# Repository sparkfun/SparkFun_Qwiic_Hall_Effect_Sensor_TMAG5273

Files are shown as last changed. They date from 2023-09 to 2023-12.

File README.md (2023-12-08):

SparkFun Hall-Effect Sensor - TMAG5273
========================================

| [	SparkFun Linear 3D Hall-Effect Sensor - TMAG5273 (Qwiic)  *(SEN-23880)*](https://www.sparkfun.com/products/23880) | [SparkFun Mini Linear 3D Hall-Effect Sensor - TMAG5273 (Qwiic) *(SEN-23881)*](https://www.sparkfun.com/products/23881) |
| --- | --- |
| product in standard 1x1 form factor (https://www.sparkfun.com/products/23880) | product in mini form factor (https://www.sparkfun.com/products/23881) |

Do you have a project that could use an inconspicuous [HID](https://en.wikipedia.org/wiki/Human_interface_device) (human interface device)? Ever wanted to tamper-proof your window alarm (i.e. contact sensors) from teenagers sneaking out or home intruders? Do you have a mechanical switch that keeps failing?

If you answered yes to any of those questions, the TMAG5273 from [Texas Instruments](https://www.ti.com) could be the solution to your problems. The TMAG5273 is low-power 3D [hall-effect sensor](https://en.wikipedia.org/wiki/Hall_effect_sensor) that is perfect for detecting and measuring changes in a nearby magnetic field. With a linear, magnetic range configurable to either ±40 mT or ±80 mT and TI's integrated angle calculation engine (CORDIC), the TMAG5273 can be used in various applications:

* Detecting motor movement
* Creating a [HID](https://en.wikipedia.org/wiki/Human_interface_device) (human interface device) *(i.e. joysticks, knobs, scroll wheels, etc.)*
* Replacing various mechanical switches (i.e. rotary encoders, contact switches, reed switches, etc.)*

In addition, the included magnetic tamper detection and wake-up/threshold settings can be configured to trigger interrupts through the I<sup>2</sup>C interface or only with the dedicated interrupt pin.

*These products are available in both the standard 1"x1" and mini Qwiic breakout boards. The mini is panel mount compatible for use in enclosures.*

Repository Contents
-------------------

* **[/docs](/docs/)** - Online documentation files
    * [assets](/docs/assets/) - Assets files
        * [board_files](/docs/assets/board_files/) - Files for the product design
            * [Eagle design files](/docs/assets/board_files/eagle_files.zip) (.zip)
            * [Schematic](/docs/assets/board_files/schematic.pdf) (.pdf)
            * [Dimensions](/docs/assets/board_files/dimensions.pdf) (.pdf)
        * [component_documentation](/docs/assets/component_documentation/) - Datasheets for hardware components
        * [img/hookup_guide/](/docs/assets/img/hookup_guide/) - Images for hookup guide documentation
* **[/Hardware](/Hardware/)** - Eagle design files (.brd, .sch)
  * **[/1U](/Hardware/1U/)** - 1"x1" Form Factor
    * **[/Production](/Hardware/1U/Production/)** - Production files
  * **[/Mini](/Hardware/Mini/)** - Mini Form Factor
    * **[/Production](/Hardware/Mini/Production/)** - Production files

Documentation
--------------

* **[Hookup Guide (mkdocs)](http://docs.sparkfun.com/SparkFun_Qwiic_Hall_Effect_Sensor_TMAG5273/)** - Hookup guide for the Qwiic hall-effect sensor hosted by GitHub pages.
  * [Arduino Library](https://github.com/sparkfun/SparkFun_TMAG5273_Arduino_Library/tree/main)

*Need to download or print our hookup guide?*

* [Print *(Print to PDF)* from Single-Page View](http://docs.sparkfun.com/SparkFun_Qwiic_Hall_Effect_Sensor_TMAG5273/print_view)

Product Variants
----------------

* [SEN-23880](https://www.sparkfun.com/products/23880)- v1.0, Initial Release *(1"x1" Form Factor)*
* [SEN-23881](https://www.sparkfun.com/products/23881)- v1.0, Initial Release *(Mini Form Factor)*

Version History
---------------

* [v10](https://github.com/sparkfun/SparkFun_Qwiic_Hall_Effect_Sensor_TMAG5273/releases/tag/v10) - Initial Release

License Information
-------------------

This product is ***open source***!

Please review the [`LICENSE.md`](./LICENSE.md) file for license information.

If you have any questions or concerns about licensing, please contact technical support on our [SparkFun forums](https://forum.sparkfun.com/viewforum.php?f=152).

Distributed as-is; no warranty is given.

- Your friends at SparkFun.

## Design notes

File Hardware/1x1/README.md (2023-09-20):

SparkFun <PRODUCT NAME> Design Files
=====================================

The .sch and .brd files hare are Eagle CAD schematic and PCB design files from SparkFun Electronics.
A freeware version of Autodesk Eagle can be found [here](https://www.autodesk.com/products/eagle/free-download).

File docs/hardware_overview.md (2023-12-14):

---
icon: material/cog
---

## Board Dimensions
The Qwiic Hall-Effect Sensors are laid out in the standardized 0.5"x 1" (1.77 x 2.54 cm) *mini* form-factor and the regular, 1" x 1" (2.54 x 2.54 cm) Qwiic breakout board. These boards also include standard 0.13" mounting holes, which are compatible with 4-40 screws. The dimensions of these boards are illustrated in the drawings below, where the listed measurements are in inches.

<div class="grid" markdown>

<div markdown>
<figure markdown>
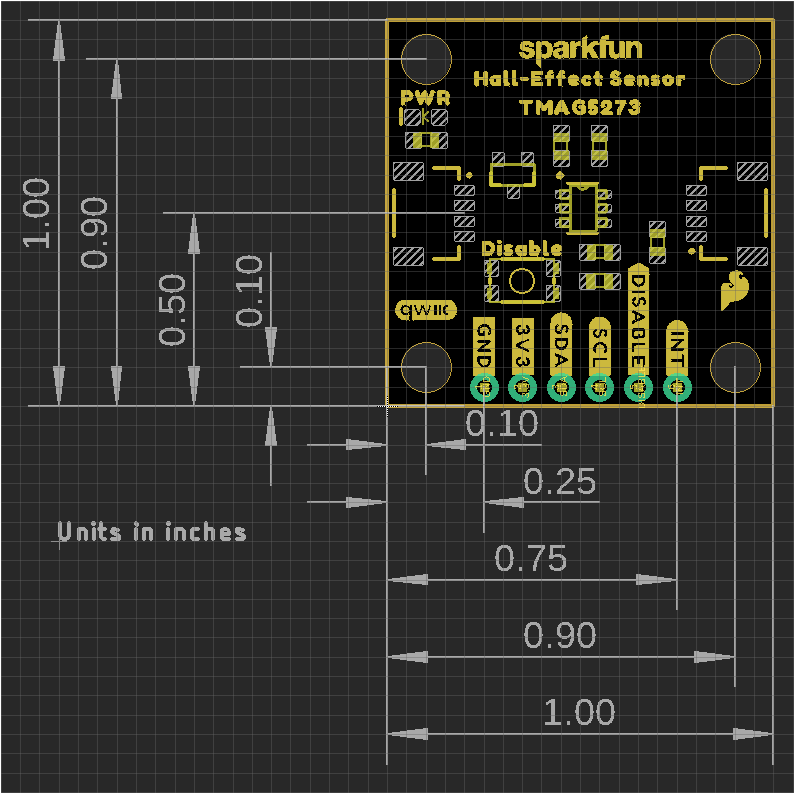
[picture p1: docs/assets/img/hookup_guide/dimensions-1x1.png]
Board Dimensions of the standard board

</figure>
</div>

<div markdown>
<figure markdown>
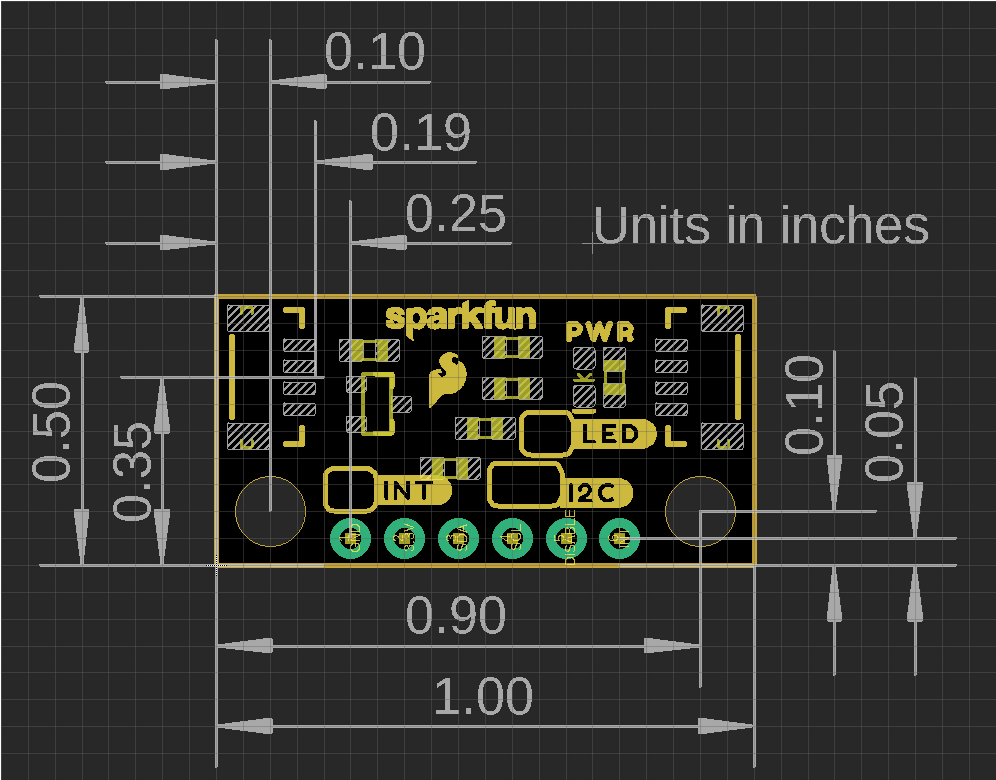
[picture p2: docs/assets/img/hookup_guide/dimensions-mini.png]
Board Dimensions of the mini board

</figure>
</div>

</div>

<center>
*[Dimensions (PDF)](./assets/board_files/dimensions.pdf) for the Qwiic Hall-Effect Sensor boards, in inches.*
</center>

??? tip "Need more measurements?"
	For more information about the board's dimensions, users can download the [eagle files](./assets/board_files/eagle_files.zip) for the boards. These files can be opened in Eagle and additional measurements can be made with the dimensions tool.

	??? info ":octicons-download-16:{ .heart } Eagle - Free Download!"
		Eagle is a [CAD]("computer-aided design") program for electronics that is free to use for hobbyists and students. However, it does require an account registration to utilize the software.

		<center>
		[Download from<br>:autodesk-primary:{ .autodesk }](https://www.autodesk.com/products/eagle/free-download "Go to downloads page"){ .md-button .md-button--primary width="250px" }
		</center>

	??? info ":straight_ruler: Dimensions Tool"
		This video from Autodesk demonstrates how to utilize the dimensions tool in Eagle, to include additional measurements:

		<center>
		<div class="video">
		<iframe src="https://www.youtube.com/embed/dZLNd1FtNB8" title="EAGLE Dimension Tool" frameborder="0" allow="accelerometer; autoplay; clipboard-write; encrypted-media; gyroscope; picture-in-picture" allowfullscreen></iframe>
		</div>
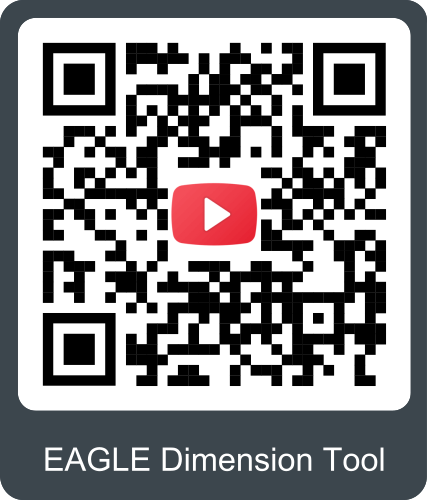
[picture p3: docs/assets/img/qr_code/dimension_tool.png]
QR code to play video
		
		</center>

## Power
The TMAG5273 requires a supply voltage between **2.3 to 3.6V** (1). This power can be provided to the board, either, through one of the *polarized* Qwiic connectors or the dedicated 3.3V (`3V3`) and ground (`GND`) [PTH](https://en.wikipedia.org/wiki/Through-hole_technology "Plated Through Holes") pins broken out on the board.
{ .annotate }

1. While the sensor's listed voltage range is 1.7 to 3.6V, its under-voltage range is 1.9 to 2.2V. Users may find that their sensor is unresponsive below 2.3V.

<div class="grid" markdown>

<div markdown>
<figure markdown>
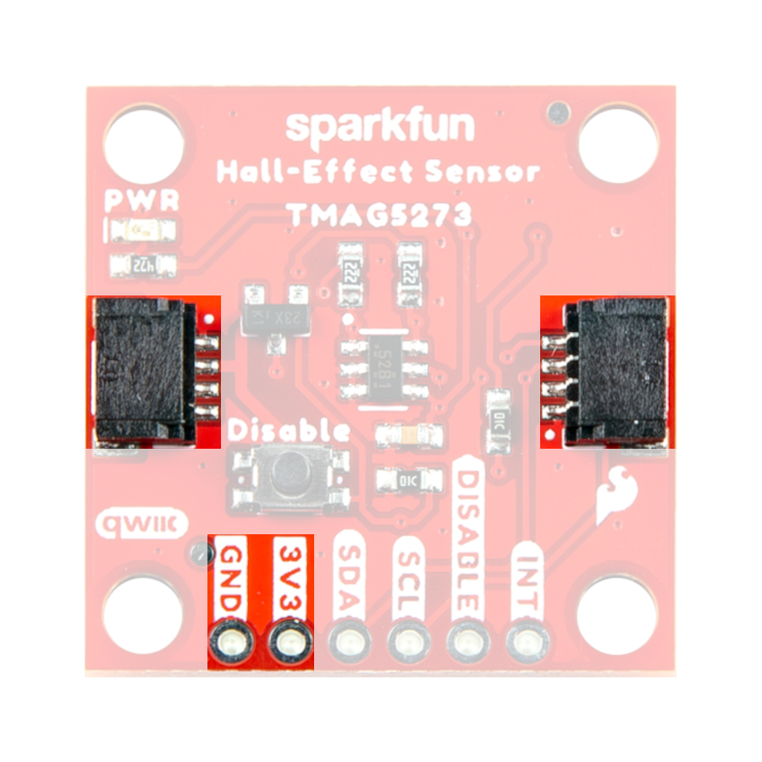
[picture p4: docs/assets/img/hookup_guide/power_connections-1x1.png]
Power connections on the standard board

</figure>
</div>

<div markdown>
<figure markdown>
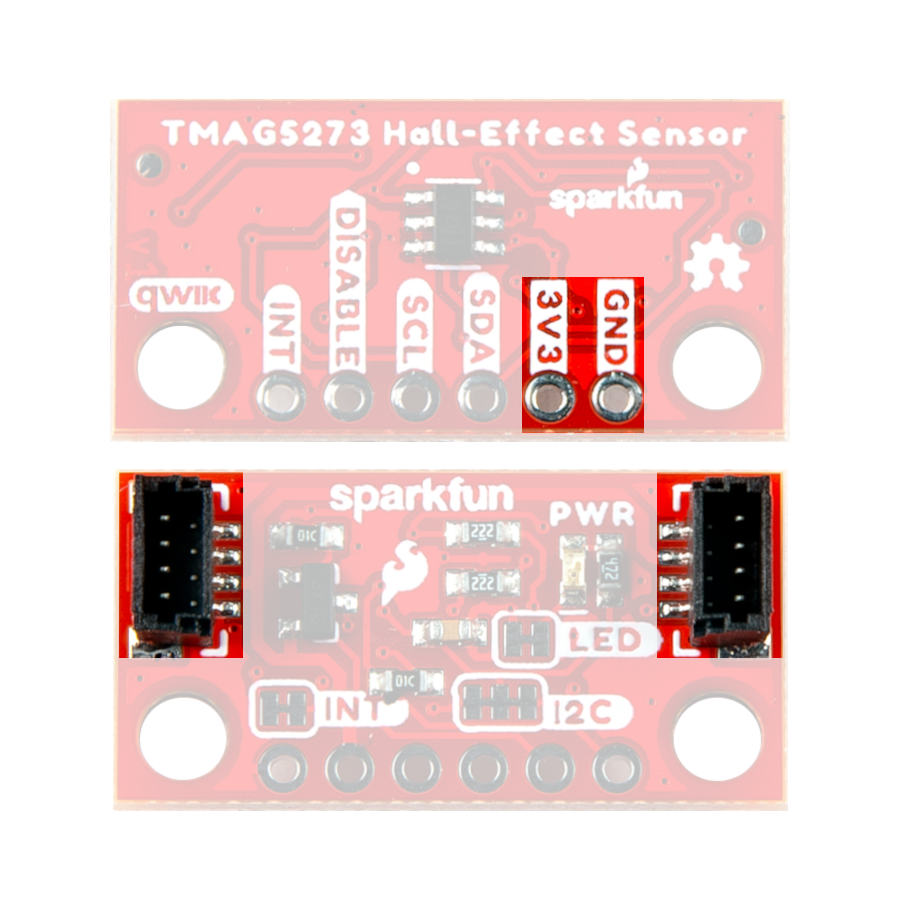
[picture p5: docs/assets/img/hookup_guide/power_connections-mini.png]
Power connections on the mini board

</figure>
</div>

</div>

<center>
*Qwiic Hall-Effect Sensor boards' power connections.*
</center>

!!! warning
	The Qwiic connect system is meant to run on **3.3V**. Ensure that another voltage is not being supplied through the PTH pins when utilized in conjunction with this system.

	??? tip "Under-Voltage Threshold"
		The under-voltage threshold of the TMAG5273 is **1.9 to 2.2V**. It is recommended that users provide an input voltage between **2.3 to 3.6V**.

!!! info
	For more details, users can reference the [schematic](./assets/board_files/schematic.pdf) and the [TMAG5273 datasheet](./assets/component_documentation/tmag5273.pdf).

### Power Status LED
The red, `PWR` LED will begin to light up once **~1.4V** is supplied to the board; however, for most users, it will light up when **3.3V** is supplied through the Qwiic connector. A jumper is available to disconnect the power from the LED, for low-power applications (see Jumpers section below).

<div class="grid" markdown>

<div markdown>
<figure markdown>
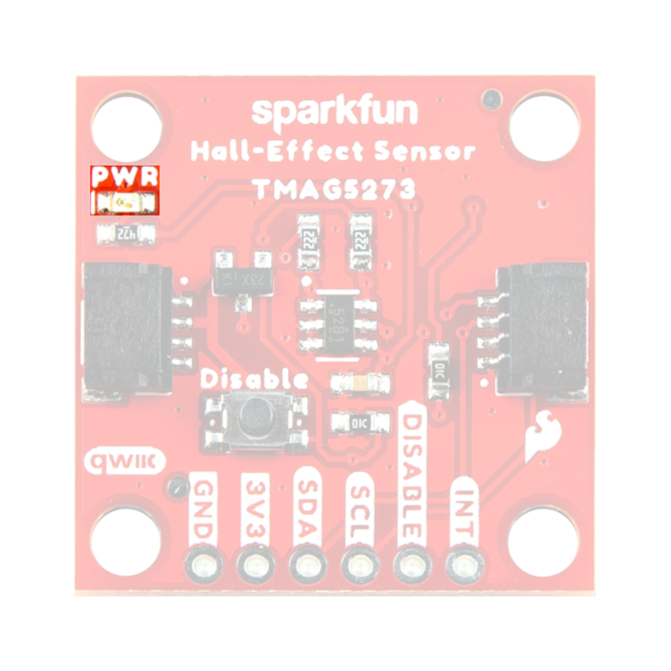
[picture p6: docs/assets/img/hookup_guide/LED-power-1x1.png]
Power LED on the standard board

</figure>
</div>

<div markdown>
<figure markdown>
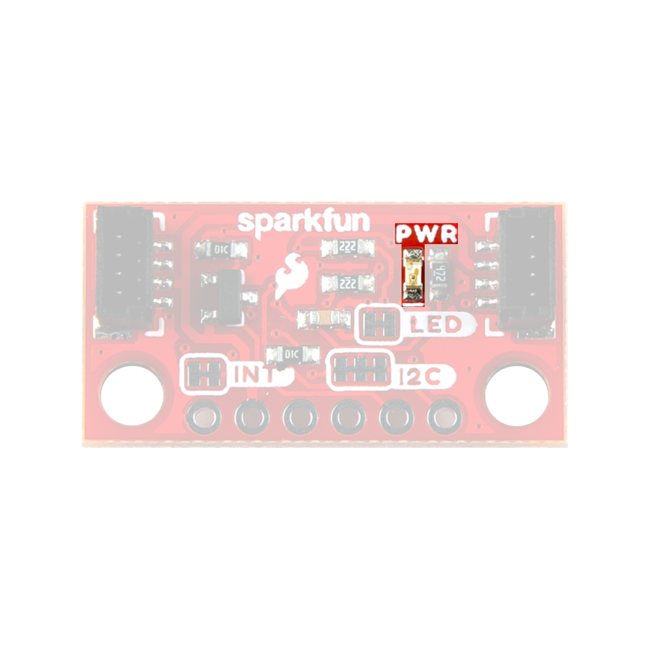
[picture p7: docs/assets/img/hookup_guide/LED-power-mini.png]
Power LED on the mini board

</figure>
</div>

</div>

<center>
*The `PWR` status LED on the Qwiic Hall-Effect Sensor boards.*
</center>

!!! tip "Minimum Voltage"
	Users should keep in mind that the forward voltage of the red LED is lower than the minimum voltage required to power the TMAG5273 sensor. Therefore, the LED could potentially be *(dimly)* lit, when there isn't enough voltage to power the sensor.

## :fontawesome-solid-microchip:&nbsp; TMAG5273
The Qwiic Hall-Effect Sensor board features the [TMAG5273 sensor](./assets/component_documentation/tmag5273.pdf) from [Texas Instruments](https://www.ti.com). The TMAG5273 is low-power 3D [hall-effect sensor](https://en.wikipedia.org/wiki/Hall_effect_sensor) that is perfect for detecting and measuring changes in a nearby magnetic field. The magnetic range of the sensor is configurable to either ±40 mT or ±80 mT. In addition, the TMAG5273 features TI's integrated angle calculation engine (CORDIC) with gain adjustment, tamper detection, and temperature compensation (for NdBFe and ceramic magnet types). The operation sensor's interrupt can be configured to trigger through the I<sup>2</sup>C interface or an interrupt pin, based upon a wake-up/threshold setting or the conversion of a new measurement.

<div class="grid" markdown>

<div markdown>

**Features:**

<div class="annotate" markdown>

* Configurable I<sup>2</sup>C Address:
    * Default (7-bit): **0x35** *(hex)* or **`0110101`** *(bin)*
* Operating Voltage: **1.7 to 3.6V** (1)
* Current Draw:
	* Active: 2.3mA
	* Sleep Mode: 5nA
	* Wake-Up/Sleep (@ 1Hz): 1&micro;A
* Full-Scale Range: &plusmn;40mT or &plusmn;80mT (2)
* Accuracy: &plusmn;5% (3)
	* Temperature Compensation (4)
* CORDIC Engine (5)
* Output Data Rate (Hz): (6)
	* 0.05, 0.2, 0.5, 1, 2, 10, 20, 33, 50, 66, 100, 200, or 1000
* Operating Temperature: -40 to 125&deg;C
* Interrupt Triggers:
	* Threshold
	* Conversion

</div>

1. The sensor may be unresponsive below 2.3V; its under-voltage range is 1.9 to 2.2V
2. The range on each axis
3. The typical sensitivity at room temperature
4. Adjusts for magnet type *(NdBFe or ceramic)*
5. Integrated angle calculation *(along a single axis)*
6. [CRC](https://en.wikipedia.org/wiki/Cyclic_redundancy_check "Cyclic Redundancy Check") can be enabled

</div>

<div markdown>

<figure markdown>
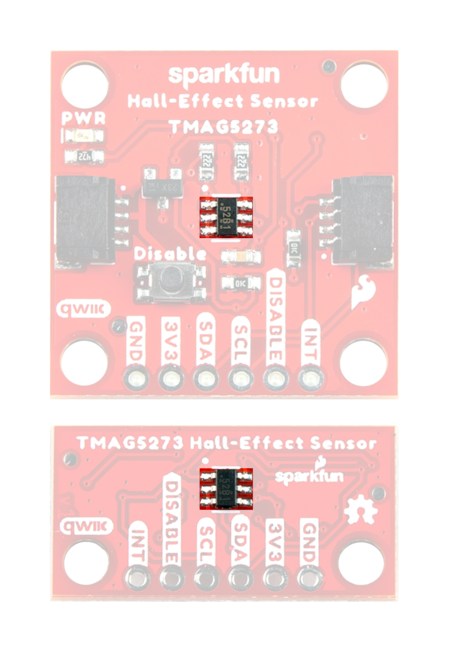
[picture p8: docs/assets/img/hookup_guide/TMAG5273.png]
TMAG5273 sensor on the boards

<figcaption markdown>The TMAG5273 sensor on the Qwiic Hall-Effect Sensor boards.</figcaption>
</figure>

</div>

</div>

??? tip "Sensor Alignment"
	=== "Position"
		We have positioned the TMAG5273 chip, based on the offset of the internal hall elements in the sensor.

		<figure markdown>
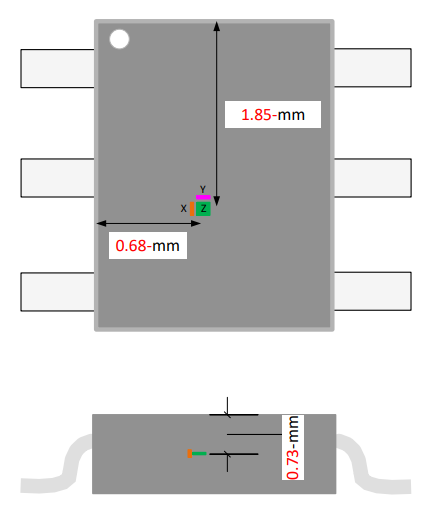
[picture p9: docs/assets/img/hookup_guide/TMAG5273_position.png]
TMAG5273 hall-effect elements position
		
		<figcaption markdown>Position of the hall elements in the TMAG5273. Source: [TMAG5273 Datasheet](./assets/component_documentation/tmag5273.pdf)</figcaption>
		</figure>

		!!! info
			For exact measurements, users can download and reference the [eagle files](./assets/board_files/eagle_files.zip) of the boards. We recommend referencing the sensor's position based on the board's CNC milled, mounting holes.
			
			!!! note
				In manufacturing, we panelize our boards on a single [PCB](https://en.wikipedia.org/wiki/Printed_circuit_board "Printed Circuit Board") with a v-score separation. This is an efficient method to assemble multiple boards at once. After the panel is populated, cleaned, and inspected, the individual boards are separated by slicing the v-scores.

				While efficient, this process means that measurements referencing the edges of the PCB won't be as accurate when compared to the included mounting holes.

	=== "Orientation"
		The orientation of the sensor's axes is illustrated in the figure below.

		<figure markdown>
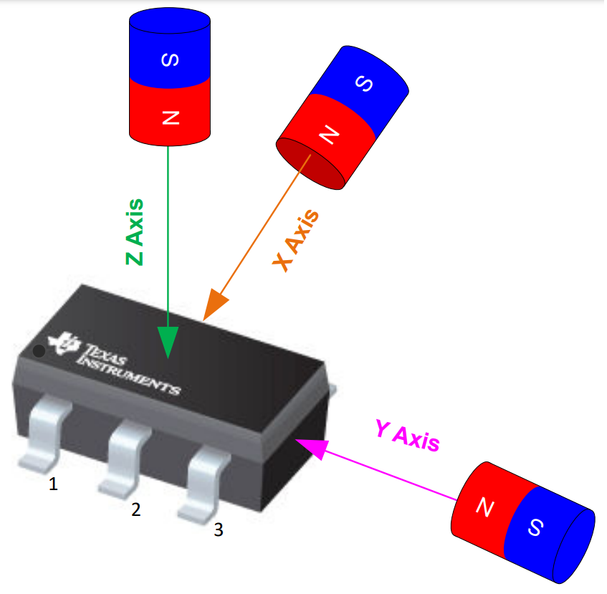
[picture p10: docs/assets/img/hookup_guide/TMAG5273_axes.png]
TMAG5273 sensor's field orientations
		
		<figcaption markdown>The magnetic field orientation of the TMAG5273 hall-effect sensor. The TMAG5273's orientation is indicated by the black dot, just below the TI logo. Source: [TMAG5273 Datasheet](./assets/component_documentation/tmag5273.pdf)</figcaption>
		</figure>

		!!! info
			The orientation of the TMAG5273 sensor is indicated by the white silkscreen dot, next to the sensor, on the [PCB](https://en.wikipedia.org/wiki/Printed_circuit_board "Printed Circuit Board") of the Qwiic Hall-Effect Sensor boards. That dot correlates with the black dot just below the Texas Instruments logo in the figure above. 

??? note "Interrupt Operation"
	The interrupt function for the TMAG5273 can be set up to operate on either the `INT` or `SCL` pins. Users can also configure what triggers the interrupt, a threshold or data conversion. Control of the interrupt's operation is managed in the following registers:

	* `DEVICE_CONFIG_2`
	* `SENSOR_CONFIG_2`
	* `INT_CONFIG_1`

??? note "Magnetic Offset Correction"
	The TMAG5273 features an offset correction, on a pair of magnetic axes for situations where the sensor might be affected by a persistent magnetic field. The offsets are configured in the following registers:

	* `MAG_OFFSET_CONFIG_1`
	* `MAG_OFFSET_CONFIG_2`
	* `SENSOR_CONFIG_2`

	<figure markdown>
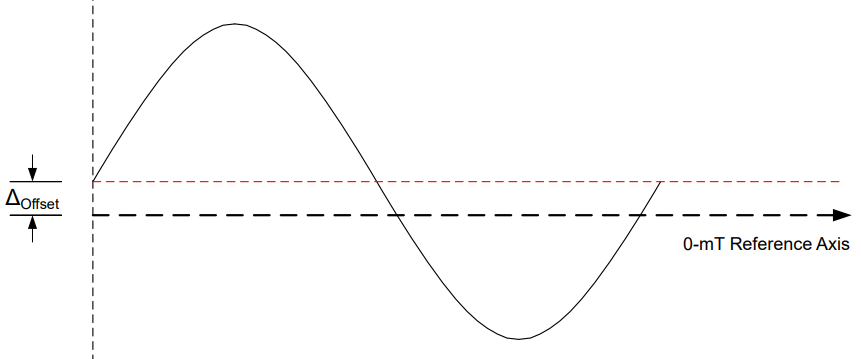
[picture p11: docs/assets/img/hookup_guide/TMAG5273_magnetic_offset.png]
example of a magnetic offset
	
	<figcaption markdown>The magnetic flux measurements of a sine curve with an offset above the reference axis. Source: [TMAG5273 Datasheet](./assets/component_documentation/tmag5273.pdf)</figcaption>
	</figure>

??? note "Gain Adjustment"
	The TMAG5273 features a gain adjustment, on a pair of magnetic axes for situations where a magnet's rotation axis is offset from the position of the sensor's hall elements. The gain adjustments are configured in the following registers:

	* `MAG_GAIN_CONFIG`
	* `SENSOR_CONFIG_2`

	<figure markdown>
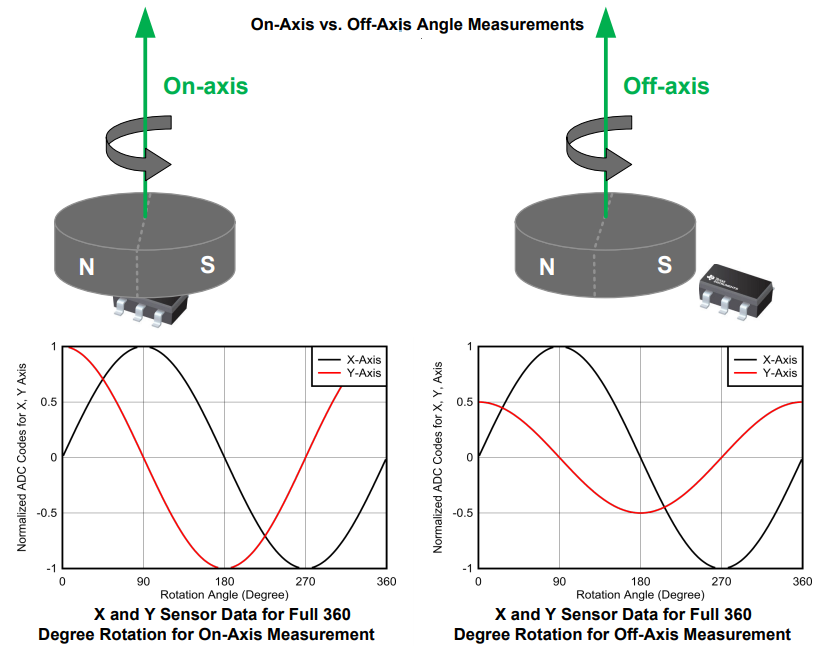
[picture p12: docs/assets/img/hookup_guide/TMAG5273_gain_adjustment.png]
example of a gain adjustment
	
	<figcaption markdown>The magnetic flux measurements of the TMAG5273 utilizing a magnet, with an on-axis and off-axis position. Source: [TMAG5273 Datasheet](./assets/component_documentation/tmag5273.pdf)</figcaption>
	</figure>

??? example "Tamper Detection"
	Magnetic tamper detection can be employed with the TMAG5273 by continuously monitoring for external magnetic fields. For more details, users can reference section **8.2.1** of the [TMAG5273 datasheet](./assets/component_documentation/tmag5273.pdf) and the [application note](./assets/component_documentation/sboa514a.pdf).

!!! info
	For more details, users can reference the [TMAG5273 datasheet](./assets/component_documentation/tmag5273.pdf).

## Breakout Pins
There are six [PTH](https://en.wikipedia.org/wiki/Through-hole_technology "Plated Through Holes") pins broken out on the Qwiic Hall-Effect Sensor boards. The pins are evenly spaced at 0.1" on the outer edge of the board; perfect for attaching [headers](https://www.sparkfun.com/categories/381). These pins provide access to the I<sup>2</sup>C interface and interrupt pin of the TMAG5273 sensor; and included is a `DISABLE` pin that controls the power to the sensor.

!!! note
	The I<sup>2</sup>C interface can also be accessed through the Qwiic connectors on the board.

### Disable Pin
Unfortunately, the TMAG5273 doesn't incorporate a software reset. The intended use of the TMAG5273 is to hard reset the sensor's power with a [GPIO](https://en.wikipedia.org/wiki/General-purpose_input/output "General Purpose I/O") pin. However, with the Qwiic connect system, users may not want to power cycle the other Qwiic devices on the system. Therefore, we have incorporated `DISABLE` pin whose circuitry allows users to reset the TMAG5273, without interrupting the power of the Qwiic connect system.

<div class="grid" markdown>

<div markdown>
<figure markdown>
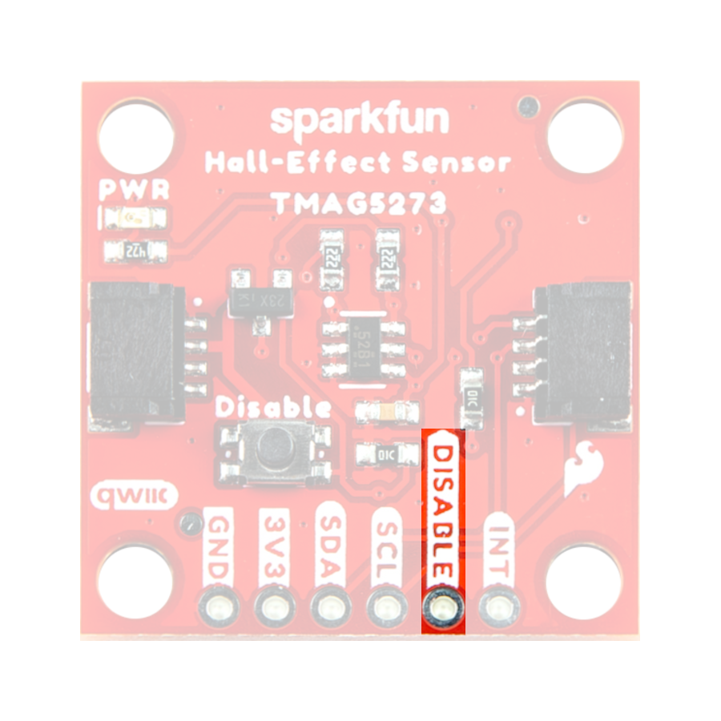
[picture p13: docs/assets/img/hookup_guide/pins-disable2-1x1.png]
Disable pin on the standard board

</figure>
</div>

<div markdown>
<figure markdown>
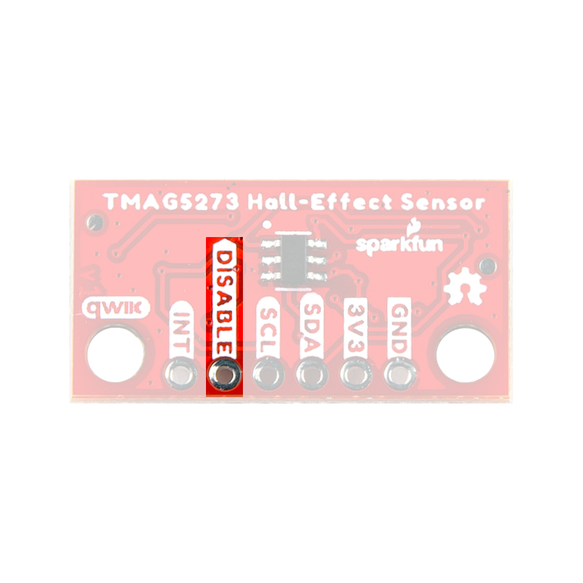
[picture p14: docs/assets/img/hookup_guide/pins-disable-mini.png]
Disable pin on the mini board

</figure>
</div>

</div>
<center>
*The `DISABLE` pin on the Qwiic Hall-Effect Sensor boards.*
</center>

!!! info
	For more details, users can reference the [schematic](./assets/board_files/schematic.pdf) and the [TMAG5273 datasheet](./assets/component_documentation/tmag5273.pdf).

#### Disable Button
A ++"Disable"++ button is only provided on the regular, 1" x 1" Qwiic board. This button is connected to the same reset circuitry of the `DISABLE` pin.

<figure markdown>
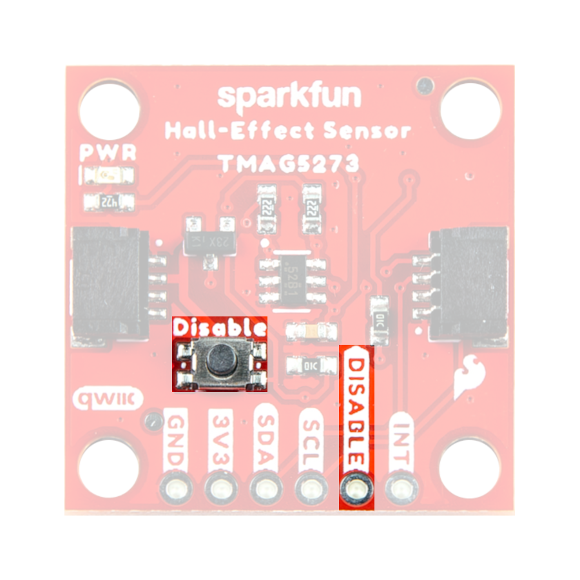
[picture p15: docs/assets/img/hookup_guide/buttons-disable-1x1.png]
Disable button on the standard board

<figcaption markdown>The ++"Disable"++ button on the Qwiic Hall-Effect Sensor.</figcaption>
</figure>

!!! tip
	The button casing appears to be ferromagnetic. Therefore, a strong magnetic field *(i.e. from a rare Earth magnet)* could potentially exert enough force to rotate or lift the board.

### I<sup>2</sup>C Pins
The I<sup>2</sup>C interface can also be accessed either through the breakout pins or the Qwiic connectors on the board. In most cases, the Qwiic connector will be the simplest method to connect the Qwiic Hall-Effect Sensor boards to a microcontroller.

<div class="grid" markdown>

<div markdown>
<figure markdown>
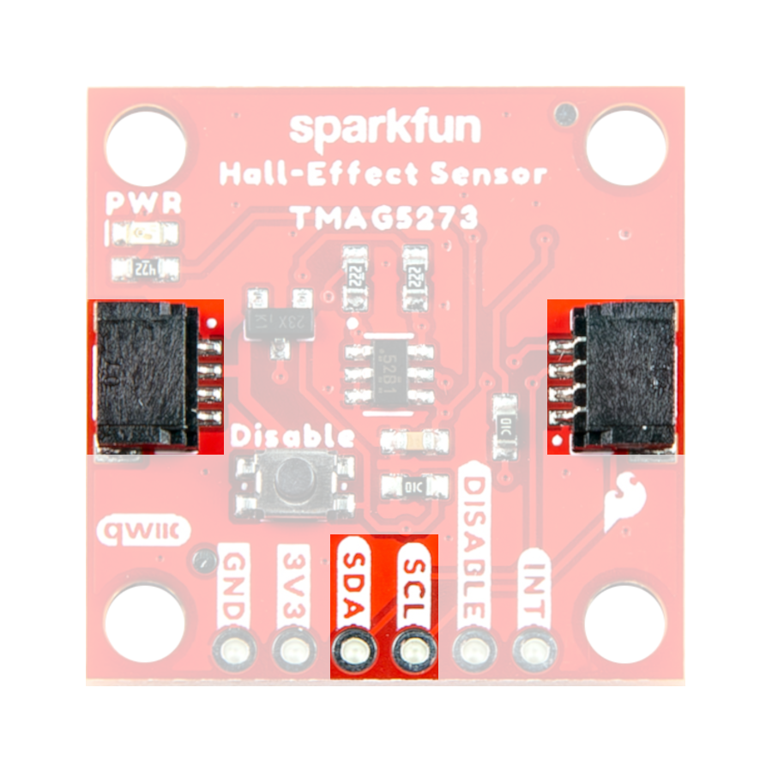
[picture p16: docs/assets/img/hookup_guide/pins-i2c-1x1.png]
I2C pins on the standard board

</figure>
</div>

<div markdown>
<figure markdown>
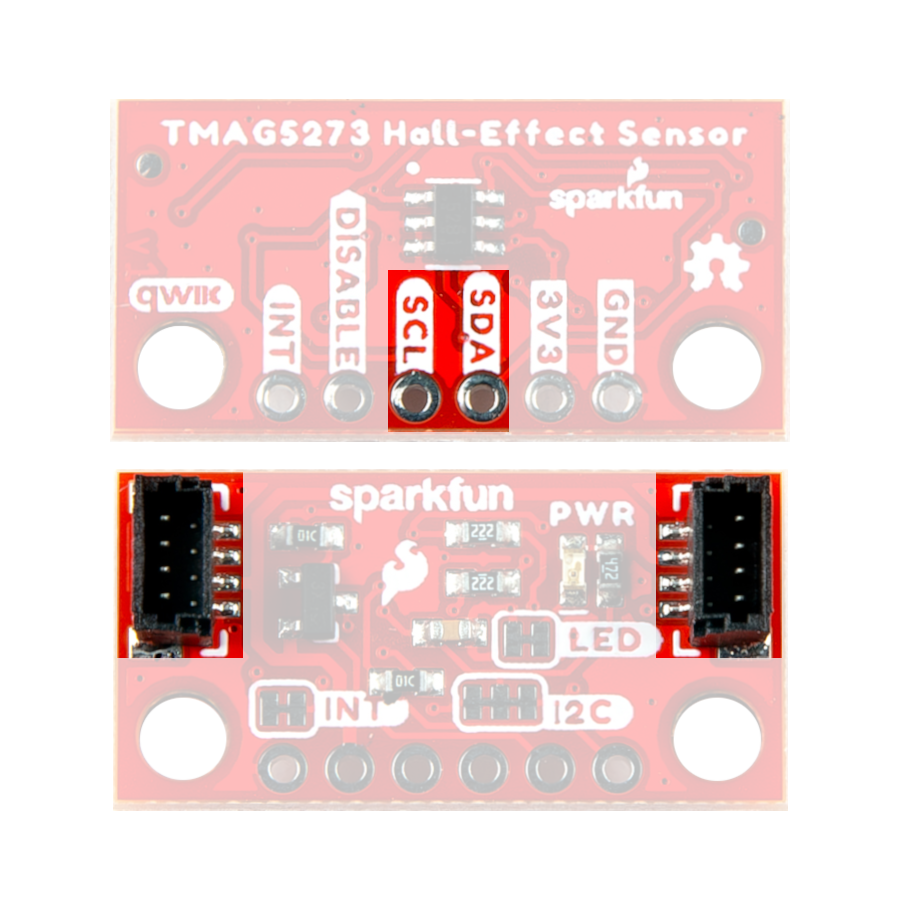
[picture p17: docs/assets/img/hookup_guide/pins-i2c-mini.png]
I2C pins on the mini board

</figure>
</div>

</div>

<center>
*I<sup>2</sup>C pins on the Qwiic Hall-Effect Sensor boards.*
</center>

??? tip " Qwiic Connector"
	Qwiic connectors are provided for users to seamlessly integrate I<sup>2</sup>C devices with [SparkFun's Qwiic Ecosystem](https://www.sparkfun.com/qwiic).

	<div class="grid" markdown>

	<div markdown>

	<figure markdown>
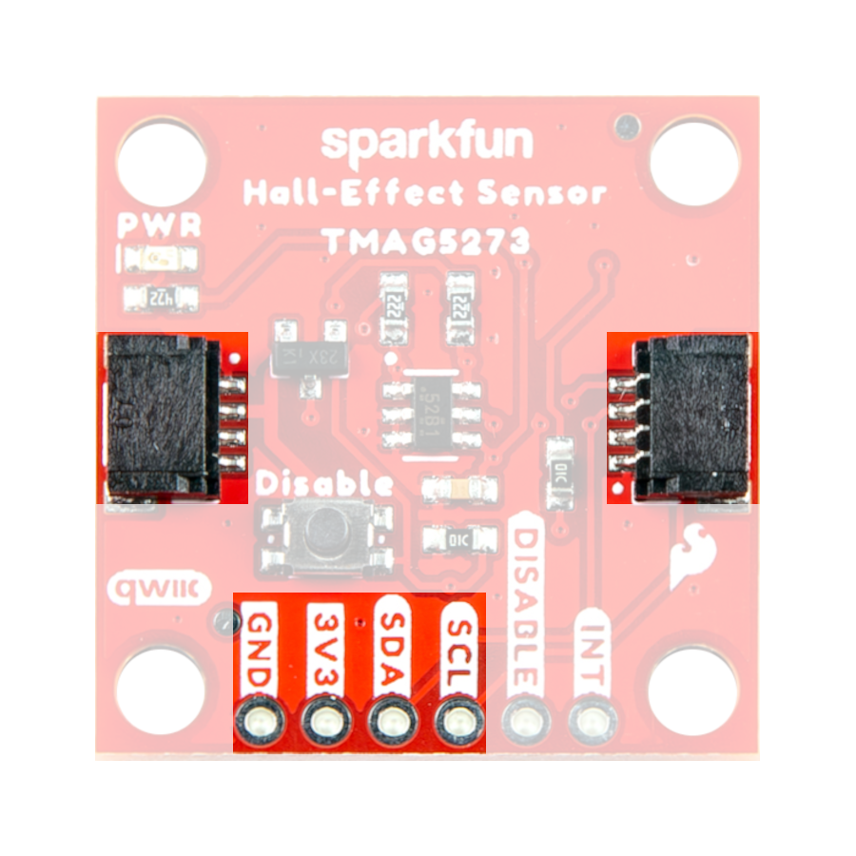
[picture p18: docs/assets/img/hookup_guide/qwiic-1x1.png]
Qwiic connector and pins on the standard board
	
	</figure>

	</div>

	<div markdown>

	<figure markdown>
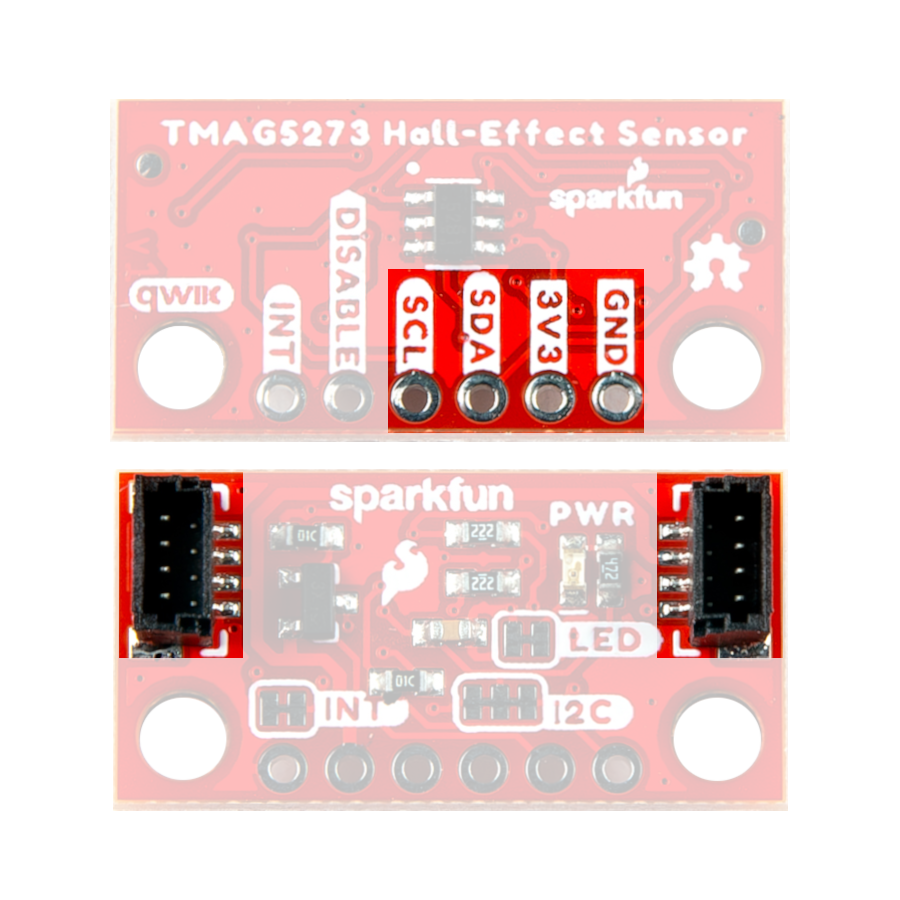
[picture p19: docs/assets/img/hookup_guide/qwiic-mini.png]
Qwiic connector and pins on the mini board
	
	</figure>

	</div>

	</div>

	<center>
	*Qwiic connector and its pins on the Qwiic Hall-Effect Sensor boards.*
	</center>

!!! warning "Interrupt Function"
	TI does not recommend sharing the same I<sup>2</sup>C bus with multiple secondary devices when using the `SCL` pin for interrupt function. The `SCL` interrupt may cause bus contention issues that would corrupt the I<sup>2</sup>C transactions with other secondary devices, when present on the same I<sup>2</sup>C bus.

### Interrupt Pin
The interrupt function can be configured to operate through either the `SCL` or `INT` pins. When utilizing the interrupt pin (`INT`), the interrupt function can be configured to trigger once a conversion is completed or when a magnetic threshold has been surpassed.

<div class="grid" markdown>

<div markdown>
<figure markdown>
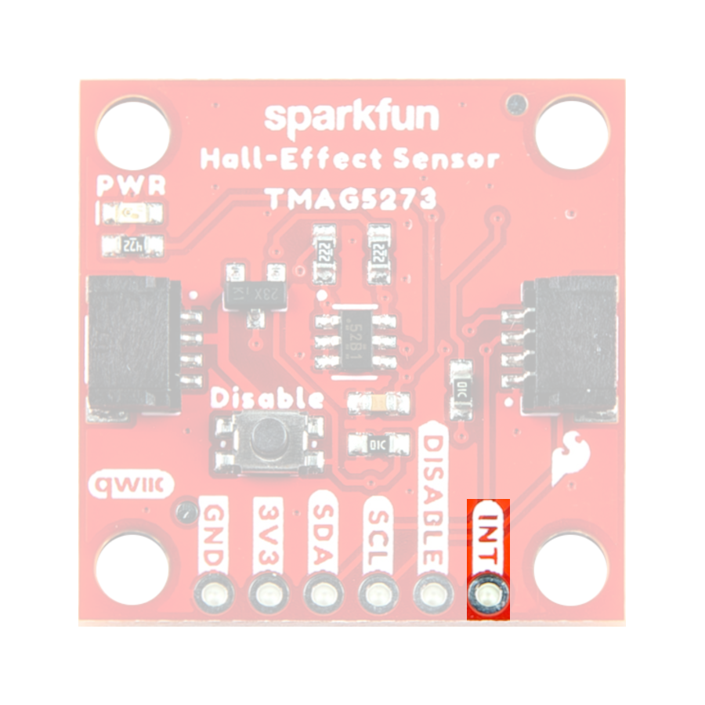
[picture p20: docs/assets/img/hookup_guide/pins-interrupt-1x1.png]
Interrupt pin on the standard board

</figure>
</div>

<div markdown>
<figure markdown>
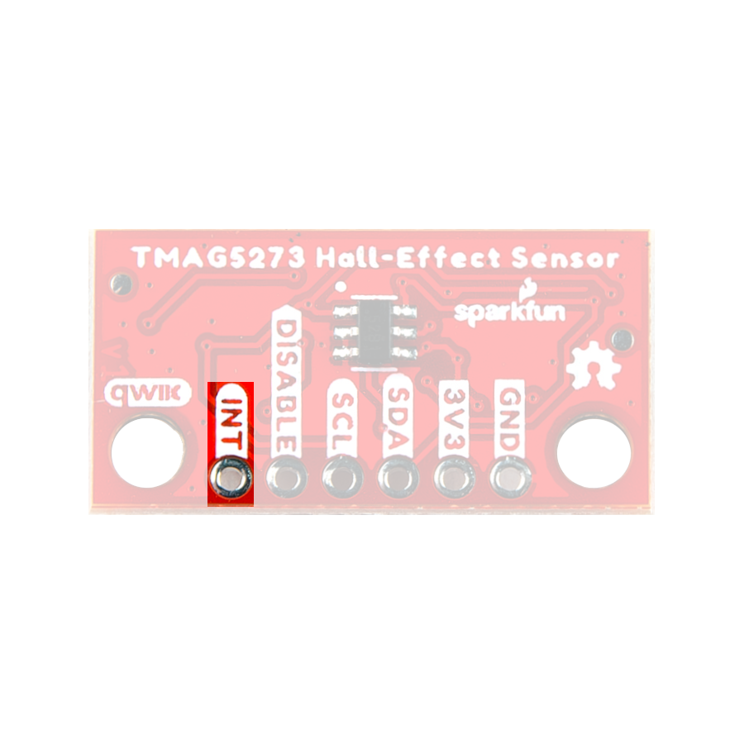
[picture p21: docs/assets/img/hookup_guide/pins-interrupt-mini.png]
Interrupt pin on the mini board

</figure>
</div>

</div>

<center>
*Interrupt pin on the Qwiic Hall-Effect Sensor boards.*
</center>

## Qwiic Connectors
Qwiic connectors are provided for users to seamlessly integrate with [SparkFun's Qwiic Ecosystem](https://www.sparkfun.com/qwiic). Otherwise, users can access the I<sup>2</sup>C interface through the [PTH pins broken out on the board](#i2c-interface).

<div class="grid" markdown>

<div markdown>
<figure markdown>
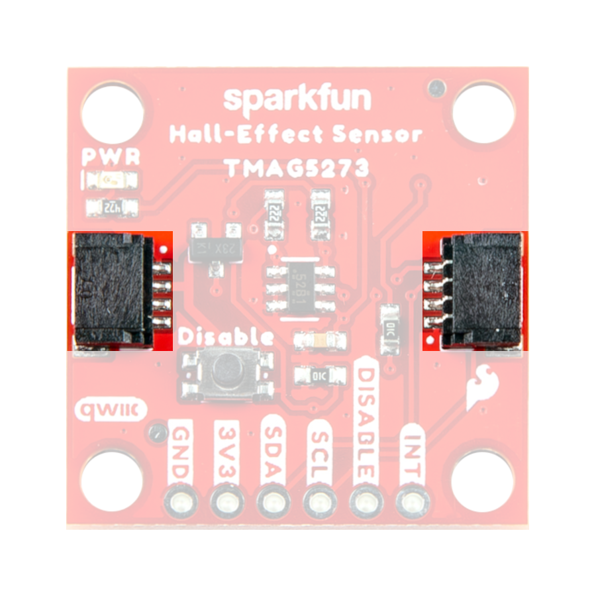
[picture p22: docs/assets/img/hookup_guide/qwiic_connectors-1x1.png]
Qwiic connector on the standard board

</figure>
</div>

<div markdown>
<figure markdown>
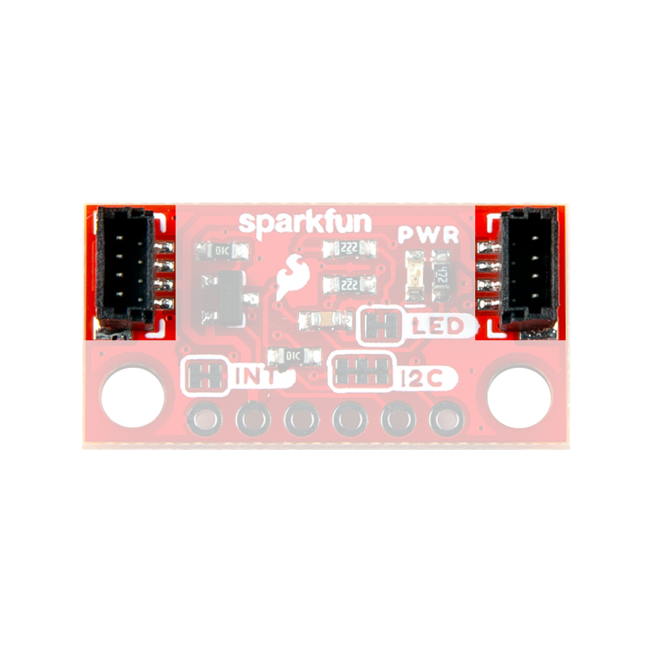
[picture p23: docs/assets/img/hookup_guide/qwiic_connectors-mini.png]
Qwiic connector on the mini board

</figure>
</div>

</div>

<center>
*Qwiic connectors on the Qwiic Hall-Effect Sensor boards.*
</center>

??? tip "What is Qwiic?"

	<!-- Qwiic Banner -->
	<center>
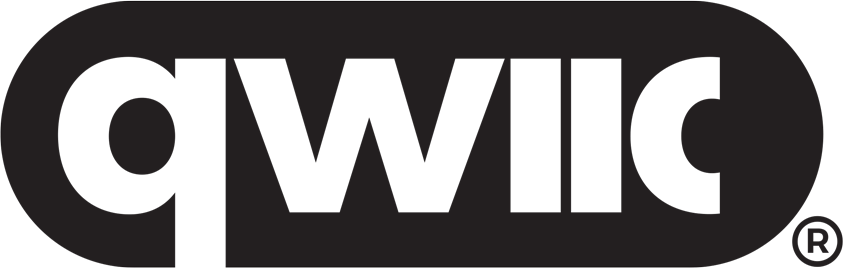
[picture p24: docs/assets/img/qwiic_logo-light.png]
Qwiic Logo - light theme (https://www.sparkfun.com/qwiic)
	
	Qwiic Logo - dark theme (https://www.sparkfun.com/qwiic)
	</center>

	---

	The [Qwiic connect system](https://www.sparkfun.com/qwiic) is a solderless, polarized connection system that allows users to seamlessly daisy chain I<sup>2</sup>C boards together. Play the video below to learn more about the Qwiic connect system or click on the banner above to learn more about [Qwiic products](https://www.sparkfun.com/qwiic).

	<center>
	<div class="video">
	<iframe src="https://www.youtube.com/embed/x0RDEHqFIF8" title="SparkFun's Qwiic Connect System" frameborder="0" allow="accelerometer; encrypted-media; gyroscope; picture-in-picture" allowfullscreen></iframe>
	</div>
	</center>

	!!! abstract "Features of the Qwiic System"

		=== "No Soldering"

			no soldering - light theme
			no soldering - dark theme

			Qwiic cables (4-pin JST) plug easily from development boards to sensors, shields, accessory boards and more, making easy work of setting up a new prototype.

		=== "Polarized Connector"

			polarized connector - light theme
			polarized connector - dark theme

			There's no need to worry about accidentally swapping the SDA and SCL wires on your breadboard. The Qwiic connector is polarized so you know you’ll have it wired correctly 	every time, right from the start.

			The PCB connector is part number SM04B-SRSS ([Datasheet](https://cdn.sparkfun.com/assets/parts/1/2/2/8/9/Qwiic_Connector_Datasheet.pdf)) or equivalent. The mating connector used on cables is part number SHR04V-S-B or an equivalent *(1mm pitch, 4-pin JST connector)*.

		=== "Daisy Chain-able"

			daisy chainable - light theme
			daisy chainable - dark theme

			It’s time to leverage the power of the I<sup>2</sup>C bus! Most Qwiic boards will have two or more connectors on them, allowing multiple devices to be connected.

## Jumpers

??? note "Never modified a jumper before?"
	Check out our <a href="https://learn.sparkfun.com/tutorials/664">Jumper Pads and PCB Traces tutorial</a> for a quick introduction!

	<div class="grid cards col-4" markdown align="center">

	-   <a href="https://learn.sparkfun.com/tutorials/664">
		<figure markdown>
		Tutorial thumbnail
		</figure>

		---

		**How to Work with Jumper Pads and PCB Traces**</a>

	</div>

There are three jumpers on the back of the board that can be used to easily modify the hardware connections of the board.

* **LED** - This jumper can be used to disconnect power from the red, power LED for low-power applications.
* **I2C** - This jumper can be used to remove the pull-up resistors on the I<sup>2</sup>C bus.
* **INT** - This jumper can be used to remove the pull-up resistor from the `INT` pin.

<div class="grid" markdown>

<div markdown>
<figure markdown>
Jumpers on the standard board
<figcaption markdown>Jumpers on the back of the Qwiic Hall-Effect Sensor board.</figcaption>
</figure>
</div>

<div markdown>
<figure markdown>
Jumpers on the mini board
<figcaption markdown>Jumpers on the Qwiic Hall-Effect Sensor board.</figcaption>
</figure>
</div>

</div>

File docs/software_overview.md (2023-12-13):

---
icon: simple/arduino
---

## Arduino IDE
!!! tip
	For first-time users, who have never programmed before and are looking to use the Arduino IDE, we recommend beginning with the <a href="https://www.sparkfun.com/products/15631">SparkFun Inventor's Kit (SIK)</a>, which is designed to help users get started programming with the Arduino IDE.

Most users may already be familiar with the Arduino IDE and its use. However, for those of you who have never heard the name *Arduino* before, feel free to check out the [Arduino website](https://www.arduino.cc/en/Guide/HomePage). To get started with using the Arduino IDE, check out our tutorials below:

<div class="grid cards" markdown align="center">

-   <a href="https://learn.sparkfun.com/tutorials/50"><figure markdown>
	What is an Arduino?
	</figure>

	---

	**What is an Arduino?**</a>

-   <a href="https://learn.sparkfun.com/tutorials/61"><figure markdown>
	Installing the Arduino IDE
	</figure>

	---
	
	**Installing the Arduino IDE**</a>

-   <a href="https://learn.sparkfun.com/tutorials/15"><figure markdown>
	Installing an Arduino Library
	</figure>

	---
	
	**Installing an Arduino Library**</a>

-   <a href="https://learn.sparkfun.com/tutorials/1265"><figure markdown>
	Installing Board Definitions in the Arduino IDE
	</figure>

	---
	
	**Installing Board Definitions in the Arduino IDE**</a>
</div>

??? tip "Need help setting up the RedBoard Plus?"
	### RedBoard Plus
	The following instructions should help users get started with the RedBoard Plus. For more information about the board, please check out our hookup guide below:

	<div class="grid cards" markdown align="center">

	-   <a href="https://learn.sparkfun.com/tutorials/1758">
		<figure markdown>
		Tutorial Thumbnail
		</figure>

		---

		**RedBoard Plus Hookup Guide**</a>

	</div>

	#### CH340 Driver
	Users will need to install the appropriate driver for their computer to recognize the serial-to-UART chip on their board/adapter. Most of the latest operating systems will recognize the CH340C chip on the board and automatically install the required driver.

	!!! tip
		To manually install the *latest* CH340 driver on their computer, users can download it from the [WCH website](http://www.wch-ic.com/products/CH340.html?). For more information, check out our [How to Install CH340 Drivers Tutorial](https://www.sparkfun.com/ch340).

	<div class="grid cards" markdown align="center">

	-   <a href="https://learn.sparkfun.com/tutorials/908">
		<figure markdown>
		Tutorial Thumbnail
		</figure>

		---

		**How to Install CH340 Drivers**</a>

	</div>

	#### Selecting a Board
	When selecting a board to program in the Arduino IDE, users should select the **Arduino Uno** from the **Tools** drop-down menu _(_i.e. **Tools** > **Board** > **Arduino AVR Boards** > **Arduino Uno**)_.

	<figure markdown>
	Click to enlarge
	<figcaption markdown>Select the **Arduino Uno** from the Tools drop-down menu in the Arduino IDE.</figcaption>
	</figure>

	??? info "Arduino IDE 2.x.x - *Alternative Method*"
		In the newest version of the Arduino IDE 2.`x`.`x`, users can also select their board (*green*) and port (*blue*) from the `Select Board & Port` dropdown menu (*yellow*).

		<figure markdown>
		Click to enlarge
		<figcaption markdown>Selecting the **Arduino Uno** and **COM5** port from the **Select Board & Port** drop-down menu in the Arduino IDE (v2.0.3).</figcaption>
	</figure>

## SparkFun TMAG5273 Arduino Library
The [SparkFun TMAG5273 Arduino library](https://github.com/sparkfun/SparkFun_TMAG5273_Arduino_Library) can be installed from the library manager in the Arduino IDE by searching for:

	SparkFun TMAG5273 Arduino library

<figure markdown>
Click to enlarge
<figcaption markdown>SparkFun TMAG5273 Arduino library in the library manager of the Arduino IDE.</figcaption>
</figure>

??? tip "Manually Downloading the Arduino Library"
	For users who would like to manually download and install the library, the `*.zip` file can be accessed from the [GitHub repository](https://github.com/sparkfun/SparkFun_TMAG5273_Arduino_Library) or downloaded by clicking the button below.

	<center>
	[:octicons-download-16:{ .heart } Download the Arduino Library](https://github.com/sparkfun/SparkFun_TMAG5273_Arduino_Library/archive/refs/heads/main.zip){ .md-button .md-button--primary }
	</center>

<!-- 
??? tip "Arduino IDE *(v1.x.x)*"
	In the Arduino IDE v1.x.x, the library manager will have the following appearance for the SparkFun TMAG5273 Arduino library:

	<figure markdown>
	[![](./assets/img/hookup_guide/arduino_library-legacy.png "Click to enlarge"){ width="400" }](./assets/img/hookup_guide/arduino_library-legacy.png)
	<figcaption markdown>SparkFun TMAG5273 Arduino library in the library manager of the Arduino IDE (v1.x.x).</figcaption>
	</figure>
 -->

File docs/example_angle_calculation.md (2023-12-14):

## Description
The [`Example3_AngleCalculations.ino`](https://github.com/sparkfun/SparkFun_TMAG5273_Arduino_Library/blob/main/examples/Example3_AngleCalculations) example file can be accessed from the **File** > **Examples** > **SparkFun TMAG5273 Arduino Library** > **Example3_AngleCalculations** drop-down menu. This example demonstrates one of the advanced features of the TMAG5273; it enables a CORDIC engine to calculate the angle of a magnet rotating about the z-axis.

??? code "`Example3_AngleCalculations.ino`"
	??? info "Code Verification"
		This code was last verified to be functional under the following parameters:

		```
		Arduino IDE Version: 2.2.1
		Arduino Library Version: 1.0.3

		Hardware Platform:
		- SparkFun RedBoard Plus
		- SparkFun Linear 3D Hall-Effect Sensor - TMAG5273 (Qwiic)
		- SparkFun Mini Linear 3D Hall-Effect Sensor - TMAG5273 (Qwiic)
		```

	```cpp linenums="1"
	--8<-- "https://raw.githubusercontent.com/sparkfun/SparkFun_TMAG5273_Arduino_Library/main/examples/Example3_AngleCalculations/Example3_AngleCalculations.ino"
	```

## Hardware Connections
For this example, users simply need to connect their Qwiic Hall-Effect Sensor board to their microcontroller, utilizing the I<sup>2</sup>C interface. With the recommended hardware, users can easily connect their boards with the Qwiic connection system.

<div class="grid" markdown>

<div markdown>
<figure markdown>
The sensor connected to a RedBoard Plus
</figure>
</div>

<div markdown>
<figure markdown>
The mini sensor connected to a RedBoard Plus
</figure>
</div>

</div>

<center>
*The Qwiic Hall-Effect Sensor boards are connected to a [RedBoard Plus](https://www.sparkfun.com/products/18158), with a [Qwiic cable](https://www.sparkfun.com/products/15081).*
</center>

??? info "Pin Connections"
	For users with a development board without a Qwiic connector, the table below illustrates the required pin connections. Make sure that the logic-level of the sensor is compatible with the development board that is being connected.

	<center>

	| Sensor Pin | Microcontroller Pin | RedBoard/Uno |
	| :--------: | :------------------ | :----------: |
	| `SCL` | I<sup>2</sup>C - Serial Clock | `SCL`/`A5` |
	| `SDA` | I<sup>2</sup>C - Serial Data  | `SDA`/`A4` |
	| `3V3` | Power: **1.7 to 3.6V**        | `3.3V`     |
	| `GND` | Ground                        | `GND`      |

	</center>

## Serial Monitor
This example enables the CORDIC engine to calculate the angle of a magnet rotating about the z-axis, which is then displayed in the [Serial Monitor](https://learn.sparkfun.com/tutorials/112).

<figure markdown>
Data stream in the serial monitor
<figcaption markdown>
The angle of the magnet is streamed from the TMAG5273 sensor into the [Serial Monitor](https://learn.sparkfun.com/tutorials/112).
</figcaption>
</figure>

!!! tip
	For this example to work, users should rotate a magnet's polarity about the z-axis of the TMAG5273 hall-effect sensor. Similar to how the magnetic knob is used for this stove top:

	<center>
	<div class="video_desc2">
	<iframe src="https://www.youtube.com/embed/B4OhGdPjmc4?&amp;start=22;&amp;end=32;" title="Demo Video - Magnetic Knob on Samsung Cooktop" frameborder="0" allow="accelerometer; autoplay; clipboard-write; encrypted-media; gyroscope; picture-in-picture" allowfullscreen></iframe>
	</div>
	</center>

	!!! warning
		The casing of rare Earth magnets is often conductive. Users should take precautions to avoid shorting out the components or electrical contacts with these types of magnets.

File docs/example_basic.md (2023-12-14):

## Description
Once the [Arduino library has been installed](../software_overview/#sparkfun-TMAG5273-arduino-library), the [`Example1_BasicReadings.ino`](https://github.com/sparkfun/SparkFun_TMAG5273_Arduino_Library/blob/main/examples/Example1_BasicReadings) example file can be accessed from the **File** > **Examples** > **SparkFun TMAG5273 Arduino Library** > **Example1_BasicReadings** drop-down menu. This example reads the raw magnetic flux (mT) and temperature (&deg;C) data from the TMAG5273 sensor through the I<sup>2</sup>C interface and displays them in the [Serial Monitor](https://learn.sparkfun.com/tutorials/112).

??? code "`Example1_BasicReadings.ino`"
	??? info "Code Verification"
		This code was last verified to be functional under the following parameters:

		```
		Arduino IDE Version: 2.2.1
		Arduino Library Version: 1.0.3

		Hardware Platform:
		- SparkFun RedBoard Plus
		- SparkFun Linear 3D Hall-Effect Sensor - TMAG5273 (Qwiic)
		- SparkFun Mini Linear 3D Hall-Effect Sensor - TMAG5273 (Qwiic)
		```

	```cpp linenums="1"
	--8<-- "https://raw.githubusercontent.com/sparkfun/SparkFun_TMAG5273_Arduino_Library/main/examples/Example1_BasicReadings/Example1_BasicReadings.ino"
	```

## Hardware Connections
For this example, users simply need to connect their Qwiic Hall-Effect Sensor board to their microcontroller, utilizing the I<sup>2</sup>C interface. With the recommended hardware, users can easily connect their boards with the Qwiic connection system.

<div class="grid" markdown>

<div markdown>
<figure markdown>
The sensor connected to a RedBoard Plus
</figure>
</div>

<div markdown>
<figure markdown>
The mini sensor connected to a RedBoard Plus
</figure>
</div>

</div>

<center>
*The Qwiic Hall-Effect Sensor boards are connected to a [RedBoard Plus](https://www.sparkfun.com/products/18158), with a [Qwiic cable](https://www.sparkfun.com/products/15081).*
</center>

??? info "Pin Connections"
	For users with a development board without a Qwiic connector, the table below illustrates the required pin connections. Make sure that the logic-level of the sensor is compatible with the development board that is being connected.

	<center>

	| Sensor Pin | Microcontroller Pin | RedBoard/Uno |
	| :--------: | :------------------ | :----------: |
	| `SCL` | I<sup>2</sup>C - Serial Clock | `SCL`/`A5` |
	| `SDA` | I<sup>2</sup>C - Serial Data  | `SDA`/`A4` |
	| `3V3` | Power: **1.7 to 3.6V**        | `3.3V`     |
	| `GND` | Ground                        | `GND`      |

	</center>

## Serial Monitor
This example reads the magnetic flux (mT) and temperature values (&deg;C) from the TMAG5273 sensor and displays them in the [Serial Monitor](https://learn.sparkfun.com/tutorials/112).

<figure markdown>
Data stream in the serial monitor
<figcaption markdown>
The magnetic flux (mT) and temperature (&deg;C) values streamed from the TMAG5273 sensor into the [Serial Monitor](https://learn.sparkfun.com/tutorials/112).
</figcaption>
</figure>

!!! tip
	For this example to work, users will need to move a magnet near the sensor.

	!!! warning
		The casing of rare Earth magnets is often conductive. Users should take precautions to avoid shorting out the components or electrical contacts with these types of magnets.

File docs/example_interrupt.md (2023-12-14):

## Description
The [`Example2_Interrupts.ino`](https://github.com/sparkfun/SparkFun_TMAG5273_Arduino_Library/blob/main/examples/Example2_Interrupts) example file can be accessed from the **File** > **Examples** > **SparkFun TMAG5273 Arduino Library** > **Example2_Interrupts** drop-down menu. This example builds upon the previous code in [`Example1_BasicReadings.ino`](https://github.com/sparkfun/SparkFun_TMAG5273_Arduino_Library/blob/main/examples/Example1_BasicReadings). Instead of constantly streaming the sensor values from the TMAG5273, the microcontroller enables a magnetic threshold interrupt on the x-axis. Then, it waits until an interrupt is triggered on the `INT` pin before the data is retrieved through the I<sup>2</sup>C interface.

??? code "`Example2_Interrupts.ino`"
	??? info "Code Verification"
		The code modification was last verified to be functional under the following parameters:

		```
		Arduino IDE Version: 2.2.1
		Arduino Library Version: 1.0.3

		Hardware Platform:
		- SparkFun RedBoard Plus
		- SparkFun Linear 3D Hall-Effect Sensor - TMAG5273 (Qwiic)
		- SparkFun Mini Linear 3D Hall-Effect Sensor - TMAG5273 (Qwiic)
		```

	!!! warning "Required Modification"
		This code was developed to be utilized with the ESP32 on the [IoT Motor Driver](https://www.sparkfun.com/products/22132). Users will need to modify the example code, to utilize the interrupt pins of the ATmega328P on the RedBoard Plus. Replace {--uint8_t intPin = 4;--} with {++uint8_t intPin = 2;++} to utilize the `D2` pin on the RedBoard Plus, which can handle interrupts.

		<div class="grid" markdown>

		<div markdown>

		**Original Code:**

		```cpp hl_lines="3"
		--8<-- "https://raw.githubusercontent.com/sparkfun/SparkFun_TMAG5273_Arduino_Library/main/examples/Example2_Interrupts/Example2_Interrupts.ino:9:11"
		```

		</div>

		<div markdown>

		**Modified Code:**

		```cpp hl_lines="3"
		// Interrupt pin used
		// NOTE: This pin is specific to the SparkFun IoT Motor Driver
		uint8_t intPin = 2;
		```

		</div>

		</div>

	```cpp linenums="1"
	--8<-- "https://raw.githubusercontent.com/sparkfun/SparkFun_TMAG5273_Arduino_Library/main/examples/Example2_Interrupts/Example2_Interrupts.ino"
	```

## Hardware Connections
For this example, users simply need to connect their Qwiic Hall-Effect Sensor board to their microcontroller, utilizing the I<sup>2</sup>C interface and interrupt pin. Users can easily connect the I<sup>2</sup>C interface with the Qwiic connection system on their boards. To connect the interrupt pin, we recommend utilizing an [IC-hook](https://www.sparkfun.com/products/9741) for a temporary connection.

<div class="grid" markdown>

<div markdown>
<figure markdown>
The sensor connected to a RedBoard Plus
</figure>
</div>

<div markdown>
<figure markdown>
The mini sensor connected to a RedBoard Plus
</figure>
</div>

</div>

<center>
*The Qwiic Hall-Effect Sensor boards are connected to a [RedBoard Plus](https://www.sparkfun.com/products/18158), with a [Qwiic cable](https://www.sparkfun.com/products/15081) and an [IC-hook](https://www.sparkfun.com/products/9741).*
</center>

??? info "Pin Connections"
	For users with a development board without a Qwiic connector, the table below illustrates the required pin connections. Make sure that the logic-level of the sensor is compatible with the development board that is being connected.

	<center>

	| Sensor Pin | Microcontroller Pin | RedBoard/Uno |
	| :--------: | :------------------ | :----------: |
	| `INT` | Interrupt Pin                 | `D2`       |
	| `SCL` | I<sup>2</sup>C - Serial Clock | `SCL`/`A5` |
	| `SDA` | I<sup>2</sup>C - Serial Data  | `SDA`/`A4` |
	| `3V3` | Power: **1.7 to 3.6V**        | `3.3V`     |
	| `GND` | Ground                        | `GND`      |

	</center>

## Serial Monitor
This example waits until an interrupt is triggered by the magnetic threshold before data is retrieved from the TMAG5273 sensor. The data is then displayed in the [Serial Monitor](https://learn.sparkfun.com/tutorials/112).

<figure markdown>
Data stream in the serial monitor
<figcaption markdown>
The magnetic flux (mT) and temperature (&deg;C) values streamed from the TMAG5273 sensor into the [Serial Monitor](https://learn.sparkfun.com/tutorials/112).
</figcaption>
</figure>

!!! tip
	For this example to work, users will need to move a magnet near the sensor to trigger the interrupt.

	!!! warning
		The casing of rare Earth magnets is often conductive. Users should take precautions to avoid shorting out the components or electrical contacts with these types of magnets.

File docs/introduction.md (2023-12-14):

---
icon: material/book-open-page-variant
---

# Introduction

Do you have a project that could use an inconspicuous [HID](https://en.wikipedia.org/wiki/Human_interface_device) (human interface device)? Ever wanted to tamper-proof your window alarm (i.e. contact sensors) from teenagers sneaking out or home intruders? Do you have a mechanical switch that keeps failing?

<section class="grid cards" markdown>

-   <a href="https://www.sparkfun.com/products/23880">
	**SparkFun Linear 3D Hall-Effect Sensor - TMAG5273 (Qwiic)**<br>
	**SKU:** SEN-23880

	---

	<figure markdown>
	Product Thumbnail
	</figure></a>

	<center>
	[QR code to product page&nbsp;&nbsp;Purchase from SparkFun :fontawesome-solid-cart-plus:{ .heart }](https://www.sparkfun.com/products/23880){ .md-button .md-button--primary }
	</center>

-   <a href="https://www.sparkfun.com/products/23881">
	**SparkFun Mini Linear 3D Hall-Effect Sensor - TMAG5273 (Qwiic)**<br>
	**SKU:** SEN-23881

	---

	<figure markdown>
	Product image
	</figure></a>

	<center>
	[QR code to product page&nbsp;&nbsp;&nbsp;Purchase from SparkFun :fontawesome-solid-cart-plus:{ .heart }](https://www.sparkfun.com/products/23881){ .md-button .md-button--primary }
	</center>

</section>

If you answered yes to any of those questions, the TMAG5273 from [Texas Instruments](https://www.ti.com) could be the solution to your problems. The [TMAG5273](](./assets/component_documentation/tmag5273.pdf)) is low-power 3D [hall-effect sensor](https://en.wikipedia.org/wiki/Hall_effect_sensor) that is perfect for detecting and measuring changes in a nearby magnetic field. With a linear, magnetic range configurable to either ±40 mT or ±80 mT and TI's integrated angle calculation engine (CORDIC), the TMAG5273 can be used in various applications:

* Detecting motor movement
* Creating a [HID](https://en.wikipedia.org/wiki/Human_interface_device) (human interface device) *(i.e. joysticks, knobs, scroll wheels, etc.)*
* Replacing various mechanical switches (i.e. rotary encoders, contact switches, reed switches, etc.)*

In addition, the included magnetic tamper detection and wake-up/threshold settings can be configured to trigger interrupts through the I<sup>2</sup>C interface or only with the dedicated interrupt pin.

## :fontawesome-solid-list-check:&nbsp;Required Materials
To get started, users will need a few items. Now some users may already have a few of these items, feel free to modify your cart accordingly.

<div class="annotate" markdown>

* Computer with an operating system (OS) that is compatible with all the software installation requirements
* A compatible microcontroller/Arduino board; we recommend the [SparkFun RedBoard Plus](https://www.sparkfun.com/products/18158).
* [USB 3.1 Cable A to C - 3 Foot](https://www.sparkfun.com/products/14743) - Used to interface with the RedBoard Plus (1)
* [SparkFun Qwiic Cable Kit](https://www.sparkfun.com/products/15081) (2)
* [SparkFun Hall-Effect Sensor - TMAG5273](https://www.sparkfun.com/products/23880) (3)
* [Magnet Square - 0.25"](https://www.sparkfun.com/products/8643) (4)

</div>

1. If your computer doesn't have a USB-A slot, then choose an appropriate cable or adapter.
2. Check out our [other Qwiic cable options](https://www.sparkfun.com/search/results?term=qwiic+cable).
3. The [mini version](https://www.sparkfun.com/products/23881) of this product is panel-mount compatible.
4. Check out the [other magnets](https://www.sparkfun.com/categories/322) in our catalog.

<div class="grid cards" markdown>

-   <a href="https://www.sparkfun.com/products/14743">
	<figure markdown>
	USB 3.1 Cable A to C - 3 Foot
	</figure>

	---

	**USB 3.1 Cable A to C - 3 Foot**<br>
	CAB-14743</a>

-   <a href="https://www.sparkfun.com/products/18158">
	<figure markdown>
	Product Thumbnail
	</figure>

	---

	**SparkFun RedBoard Plus**<br>
	DEV-18158</a>

-   <a href="https://www.sparkfun.com/products/15081">
	<figure markdown>
	Product Thumbnail
	</figure>

	---

	**SparkFun Qwiic Cable Kit**<br>
	KIT-15081</a>

-   <a href="https://www.sparkfun.com/products/23880">
	<figure markdown>
	Product Thumbnail
	</figure>

	---

	**SparkFun Linear 3D Hall-Effect Sensor - TMAG5273 (Qwiic)**<br>
	SEN-23880</a>

	??? tip "Button Casing"
		The button casing appears to be ferromagnetic. Therefore, a strong magnetic field *(i.e. from a rare Earth magnet)* could potentially exert enough force to rotate or lift the board.

-   <a href="https://www.sparkfun.com/products/23880">
	<figure markdown>
	Product Thumbnail
	</figure>

	---

	**SparkFun Mini Linear 3D Hall-Effect Sensor - TMAG5273 (Qwiic)**<br>
	SEN-23881</a>

-   <a href="https://www.sparkfun.com/products/8643">
	<figure markdown>
	Product Thumbnail
	</figure>

	---

	**Magnet Square - 0.25"**<br>
	COM-08643</a>

	??? danger "Metal Casing"
		The casing for rare Earth magnets, such as these, is often conductive. Users should take precautions to avoid shorting out the components or electrical contacts.

</div>

??? note "Headers and Wiring"
	To add headers or hookup wires, users will need [soldering equipment](https://www.sparkfun.com/categories/49) and [headers](https://www.sparkfun.com/categories/381)/[wire](https://www.sparkfun.com/search/results?term=hook-up+wire).

	!!! tip "New to soldering?"
		Check out our [How to Solder: Through-Hole Soldering](https://learn.sparkfun.com/tutorials/5) tutorial for a quick introduction!

		<div class="grid cards" markdown align="center">

		-   <a href="https://learn.sparkfun.com/tutorials/5">
			<figure markdown>
			Tutorial Thumbnail
			</figure>

			---

			**How to Solder: Through-Hole Soldering**</a>

		</div>

	<div class="grid cards" markdown>

	-   <a href="https://www.sparkfun.com/products/9325">
		<figure markdown>
		Product Thumbnail
		</figure>

		---

		**Solder Lead Free - 100-gram Spool**<br>
		TOL-09325</a>

	-   <a href="https://www.sparkfun.com/products/14228">
		<figure markdown>
		Product Thumbnail
		</figure>

		---

		**Weller WLC100 Soldering Station**<br>
		TOL-14228</a>

	-   <a href="https://www.sparkfun.com/products/14579">
		<figure markdown>
		Product Thumbnail
		</figure>

		---

		**Chip Quik No-Clean Flux Pen - 10mL**<br>
		TOL-14579</a>

	-   <a href="https://www.sparkfun.com/products/116">
		<figure markdown>
		Product Thumbnail
		</figure>

		---

		**Break Away Headers - Straight**<br>
		PRT-00116</a>

	-   <a href="https://www.sparkfun.com/products/11375">
		<figure markdown>
		Product Thumbnail
		</figure>

		---

		**Hook-Up Wire - Assortment (Stranded, 22 AWG)**<br>
		PRT-11375</a>

	</div>

??? note "Jumper Modification"
	To modify the [jumpers](../hardware_overview/#jumpers), users will need [soldering equipment](https://www.sparkfun.com/categories/49) and/or a [hobby knife](https://www.sparkfun.com/categories/379).

	!!! tip "New to jumper pads?"
		Check out our [Jumper Pads and PCB Traces Tutorial](https://learn.sparkfun.com/tutorials/664) for a quick introduction!

		<div class="grid cards" markdown align="center">

		-   <a href="https://learn.sparkfun.com/tutorials/664">
			<figure markdown>
			Tutorial thumbnail
			</figure>

			---

			**How to Work with Jumper Pads and PCB Traces**</a>

		</div>

	<div class="grid cards" markdown>

	-   <a href="https://www.sparkfun.com/products/9325">
		<figure markdown>
		Product Thumbnail
		</figure>

		---

		**Solder Lead Free - 100-gram Spool**<br>
		TOL-09325</a>

	-   <a href="https://www.sparkfun.com/products/14228">
		<figure markdown>
		Product Thumbnail
		</figure>

		---

		**Weller WLC100 Soldering Station**<br>
		TOL-14228</a>

	-   <a href="https://www.sparkfun.com/products/14579">
		<figure markdown>
		Product Thumbnail
		</figure>

		---

		**Chip Quik No-Clean Flux Pen - 10mL**<br>
		TOL-14579</a>

	-   <a href="https://www.sparkfun.com/products/9200">
		<figure markdown>
		Product Thumbnail
		</figure>

		---

		**Hobby Knife**<br>
		TOL-09200</a>

	</div>

## :material-bookshelf:&nbsp;Suggested Reading

As a more sophisticated product, we will skip over the more fundamental tutorials (i.e. [**Ohm's Law**](https://learn.sparkfun.com/tutorials/voltage-current-resistance-and-ohms-law) and [**What is Electricity?**](https://learn.sparkfun.com/tutorials/what-is-electricity)). However, below are a few tutorials that may help users familiarize themselves with various aspects of the board.

<div class="grid cards" markdown align="center">

-   <a href="https://learn.sparkfun.com/tutorials/61"><figure markdown>
	Installing the Arduino IDE
	</figure>

	---

	**Installing the Arduino IDE**</a>

-   <a href="https://learn.sparkfun.com/tutorials/15"><figure markdown>
	Installing an Arduino Library
	</figure>

	---

	**Installing an Arduino Library**</a>

-   <a href="https://learn.sparkfun.com/tutorials/1758">
	<figure markdown>
	Tutorial Thumbnail
	</figure>

	---

	**RedBoard Plus Hookup Guide**</a>

	??? tip "<div align="left">USB Driver<div>"
		<article class="grid cards" markdown align="center">

		-   <a href="https://learn.sparkfun.com/tutorials/908">
			<figure markdown>
			Tutorial Thumbnail
			</figure>

			---

			**How to Install CH340 Drivers**</a>

		</article>

-   <a href="https://learn.sparkfun.com/tutorials/112">
	<figure markdown>
	Tutorial Thumbnail
	</figure>

	---

	**Serial Terminal Basics**</a>

-   <a href="https://learn.sparkfun.com/tutorials/62">
	<figure markdown>
	Tutorial Thumbnail
	</figure>

	---

	**Logic Levels**</a>

-   <a href="https://learn.sparkfun.com/tutorials/82">
	<figure markdown>
	Tutorial Thumbnail
	</figure>

	---

	**I2C**</a>

-   <a href="https://learn.sparkfun.com/tutorials/5">
	<figure markdown>
	Tutorial Thumbnail
	</figure>

	---

	**How to Solder: Through-Hole Soldering**</a>

-   <a href="https://learn.sparkfun.com/tutorials/664">
	<figure markdown>
	Tutorial Thumbnail
	</figure>

	---

	**How to Work with Jumper Pads and PCB Traces**</a>

</div>

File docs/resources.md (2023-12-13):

## Product Resources

<section class="grid cards" markdown>

- **Composite (Both Boards)**

	---

	* :material-folder-cog: Design Files:
		* :fontawesome-solid-file-pdf: [Board Dimensions](./assets/board_files/dimensions.pdf)
		* :fontawesome-solid-file-pdf: [Schematic](./assets/board_files/schematic.pdf)
		* :material-folder-zip: [Eagle Files](./assets/board_files/eagle_files.zip)
	* :simple-arduino: [Arduino Library](https://github.com/sparkfun/SparkFun_TMAG5273_Arduino_Library/tree/main)
	* Component Documentation
		* :fontawesome-solid-file-pdf: [TMAG52735 Datasheet](./assets/component_documentation/tmag5273.pdf)
	* :material-github: [Hardware Repo](https://github.com/sparkfun/SparkFun_Qwiic_Hall_Effect_Sensor_TMAG5273)

- **Regular Version (1" x 1")**

	---
	<figure markdown>
	Product Thumbnail
	</figure></a>

	* :sfe-logo: [Product Page](https://www.sparkfun.com/products/23880)
	* :material-folder-cog: Design Files:
		* :fontawesome-solid-file-pdf: [Board Dimensions](./assets/board_files/dimensions-1x1.pdf)
		* :fontawesome-solid-file-pdf: [Schematic](./assets/board_files/schematic-1x1.pdf)
		* :material-folder-zip: [Eagle Files](./assets/board_files/eagle_files-1x1.zip)

- **Mini Version (0.5" x 1")**

	---

	<figure markdown>
	Product image
	</figure></a>

	* :sfe-logo: [Product Page](https://www.sparkfun.com/products/23881)
	* :material-folder-cog: Design Files:
		* :fontawesome-solid-file-pdf: [Board Dimensions](./assets/board_files/dimensions-mini.pdf)
		* :fontawesome-solid-file-pdf: [Schematic](./assets/board_files/schematic-mini.pdf)
		* :material-folder-zip: [Eagle Files](./assets/board_files/eagle_files-mini.zip)

</section>

### Additional Resources

* :material-account-supervisor: [SparkFun Technical Assistance](https://www.sparkfun.com/technical_assistance)

## 🏭&nbsp;Manufacturer's Resources
ST Microelectronics also provides additional resources for the TMAG52735:

* [TMAG52735 Product Page](https://www.st.com/en/mems-and-sensors/TMAG5273.html)

<center>
QR code to the hookup guide
</center>

[Designing with Hall-effect sensors - electronic smart lock](https://www.youtube.com/watch?v=3g0DYSVJstQ)
[Designing joysticks with Hall-effect sensors](https://www.youtube.com/watch?v=slAN-Ly4Mfk)

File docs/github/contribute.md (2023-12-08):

# Contribute: Make an Augmentation!
Spot an improvement opportunity? Feel free to contribute to our open-source design and documentation. 

## :material-file-document-multiple:&nbsp;Improve our Documentation
All of this documentation can be modified by you! Please help us make it better.

* These pages are contained in the [`docs` folder](https://github.com/sparkfun/SparkFun_Qwiic_Hall_Effect_Sensor_TMAG5273/tree/main/docs) of the [SparkFun Qwiic Hall-Effect Sensor TMAG5273 repository](https://github.com/sparkfun/SparkFun_Qwiic_Hall_Effect_Sensor_TMAG5273).

<!-- ### :material-source-pull:&nbsp;Submit a Correction -->
### Submit a Correction

1. With a GitHub account, [fork this repository](https://github.com/sparkfun/SparkFun_Qwiic_Hall_Effect_Sensor_TMAG5273/fork).
2. Add your corrections or improvements to the markdown file.
3. File a pull request with your changes, and enjoy making the ~~words~~ ~~worlds~~ world a better place.
	* Once received, the documentation specialist will automatically be notified.
	* We will review your suggested improvements to make sure they are correct and fit within our documentation standards.

## :material-cog:&nbsp;Improve our Hardware Design
All of our designs are open-source! Please help us make it better.

* Our board design files are contained in the [`Hardware` folder](https://github.com/sparkfun/SparkFun_Qwiic_Hall_Effect_Sensor_TMAG5273/tree/main/Hardware) of the [SparkFun Qwiic Hall-Effect Sensor TMAG5273 repository](https://github.com/sparkfun/SparkFun_Qwiic_Hall_Effect_Sensor_TMAG5273).

<!-- ### :material-source-pull:&nbsp;Submit a Design Enhancement -->
### Submit a Design Enhancement

1. With a GitHub account, [fork this repository](https://github.com/sparkfun/SparkFun_Qwiic_Hall_Effect_Sensor_TMAG5273/fork).
2. Add your design augmentation(s)
3. File a pull request with your changes, and enjoy making the ~~words~~ ~~worlds~~ world a better place.
	1. Once received, the engineer in charge of the original design will automatically be notified.
	2. We will review your suggested improvement(s) to verify that they are within our board design standards and meet our product design requirements.
	3. If approved, we will flag these changes for our next board revision. Congrats! 🍻

		!!! info
			Even if your suggestion is accepted, these changes may not be immediately available for purchase. We may have to cycle through our current product inventory first.

## Contributors&nbsp;:clap:
Let's provide some recognition to the contributors for this project!

GitHub Contributors Image
<br>


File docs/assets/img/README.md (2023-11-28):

img directory
====================
This folder should contain the images for the product documentation

## General Images
* `sfe_logo_sm.png` - SparkFun flame logo (Cover page for with-pdf extension)
* `sfe_logo_sq.png` - SparkFun flame logo (favicon)

## Directory
* `hookup_guide` - Images for the hookup guide pages

## QR Codes
* [QR code generator](https://qrgenerator.org/)
	* Flame Color: #E0311D
	* Frame Color: #3C464D
	* Label Font: Arial
* [Remove meta data from svg](https://jakearchibald.github.io/svgomg/)

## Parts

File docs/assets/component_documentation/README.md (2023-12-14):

component_documentation directory
====================

A copy of the datasheets, user manuals, programming guides, etc. of the major electrical components on the board.

* [TMAG5273 Datasheet](tmag5273.pdf) (PDF)
* [DMG2305UX Datasheet](DMG2305UX.pdf) (PDF)

Application Notes:

* [Introduction to Hall-Effect Sensors](slyt824a.pdf)
* [Magnet Selection for Linear Position Applications](slya059a.pdf)
* [Angle Calculation Methods Using Position Sensor Output Data](slya069a.pdf)
* [Angle Measurement With Multi-Axis Linear Hall-Effect Sensors](sbaa463a.pdf)
* [Absolute Angle Measurements for Rotational Motion Using Hall-Effect Sensors](sbaa503a.pdf)
* [Measuring 3D Motion With Absolute Position Sensors](sbaa512a.pdf)
* [Reed Switch Replacement with TI's Hall-effect and Linear 3D Hall-effect Sensors](sbaa510.pdf)
* [Using Hall-Effect Sensors For Contactless Rotary Encoding and Knob Applications](slya063a.pdf)
* [Joystick and Lever Design With Hall-Effect Sensors](slyu064.pdf)
* [3D Hall-Effect Sensor for Knobs in Appliances](slya080.pdf)
* [Limit Detection for Tamper and End-of-Travel Detection Using Hall-Effect Sensors](sboa514a.pdf)

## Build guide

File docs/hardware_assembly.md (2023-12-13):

---
icon: material/tools
---

## Qwiic Cable
The simplest method to connect a microcontroller to a Qwiic Hall-Effect Sensor board is through the Qwiic connector.

<figure markdown>
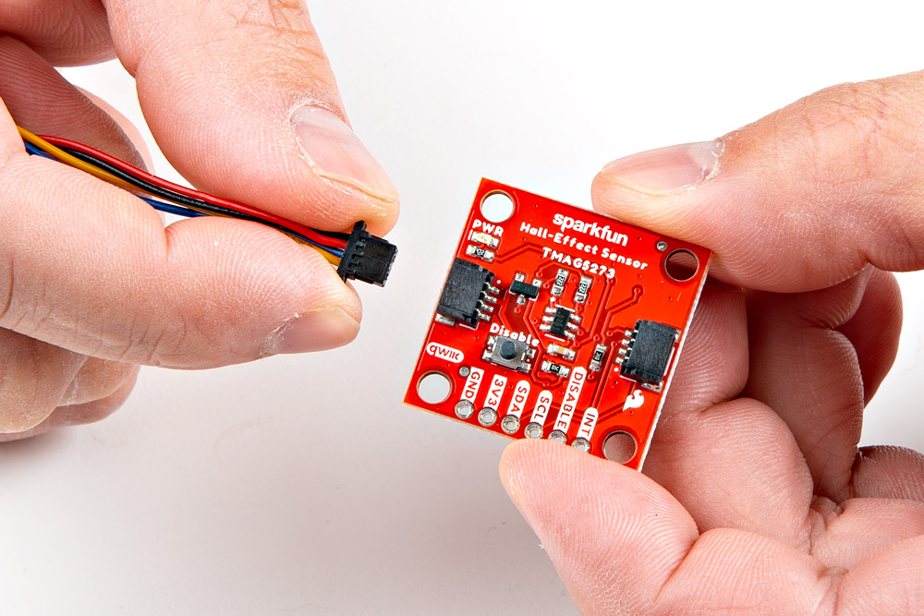
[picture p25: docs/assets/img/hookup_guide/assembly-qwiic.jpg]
Connecting Qwiic cable

<figcaption markdown>Connecting a [Qwiic cable](https://www.sparkfun.com/products/15081) to the Qwiic Hall-Effect Sensor board.</figcaption>
</figure>

!!! info
	The [Qwiic connection system](https://www.sparkfun.com/qwiic) is a standardized solderless, polarized connector interface that allows users to seamlessly daisy chain I<sup>2</sup>C boards together.

??? tip "Remove Tape"
	Users with the mini version of the Qwiic Hall-Effect Sensor board should remove the tape covering the Qwiic connector.

	<div class="grid" markdown>

	<div markdown>

	<figure markdown>
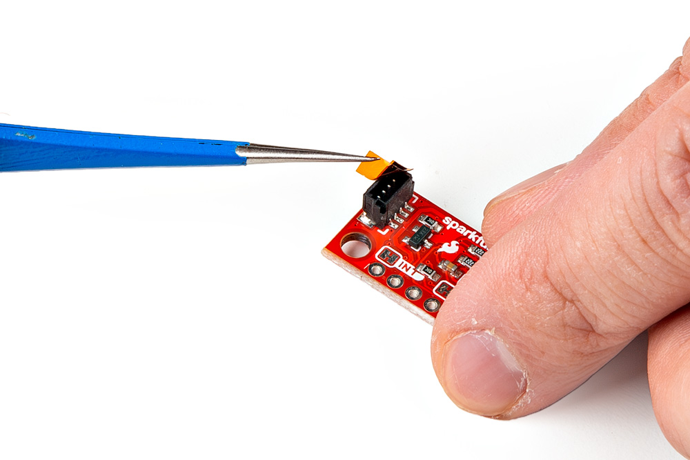
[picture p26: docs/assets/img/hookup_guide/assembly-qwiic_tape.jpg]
Removing tape
	
	<figcaption markdown>Removing the tape from the Qwiic connector to the Qwiic Hall-Effect Sensor board.</figcaption>
	</figure>

	</div>

	<div markdown>

	!!! info
		The tape is used by the [pick-and-place machine](https://en.wikipedia.org/wiki/Pick-and-place_machine) to place the connector on the board during assembly.

	!!! note
		The tweezers are not necessary, they were only used for illustration purposes. *(Fingers would have obscured the camera shot.)*

	</div>

	</div>

## Breakout Pins
The [PTH](https://en.wikipedia.org/wiki/Through-hole_technology "Plated Through Holes") pins on the Qwiic Hall-Effect Sensor board are broken out into 0.1"-spaced pins on the outer edge of the board.

??? note "New to soldering?"
	If you have never soldered before or need a quick refresher, check out our [How to Solder: Through-Hole Soldering](https://learn.sparkfun.com/tutorials/how-to-solder-through-hole-soldering) guide.

	<div class="grid cards col-4" markdown align="center">

	-   <a href="https://learn.sparkfun.com/tutorials/5">
		<figure markdown>
		Tutorial thumbnail
		</figure>

		---
		
		**How to Solder: Through-Hole Soldering**</a>

	</div>

### Hookup Wires
For a more permanent connection, users can solder wires directly to the board.

<figure markdown>
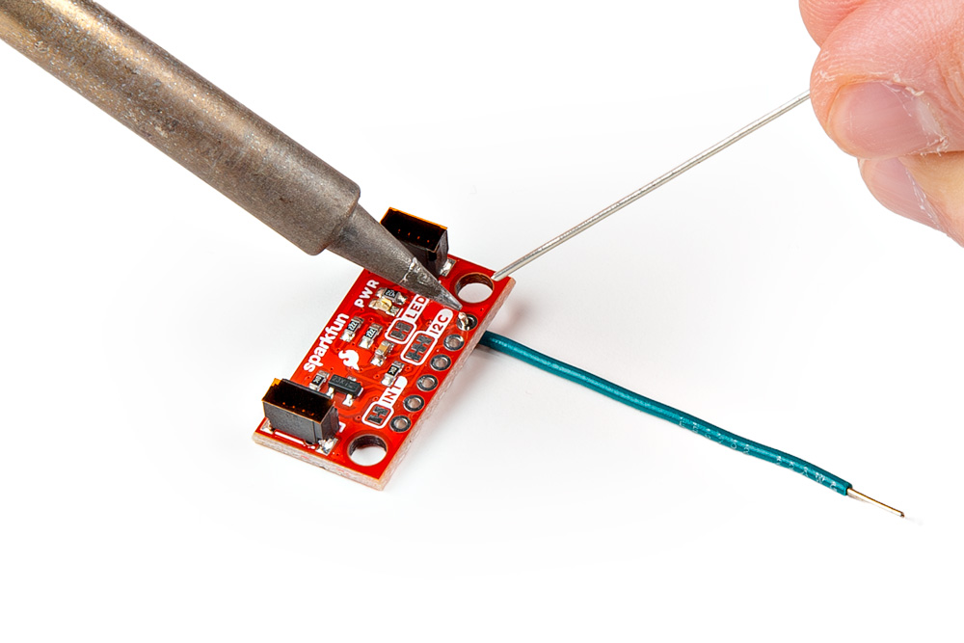
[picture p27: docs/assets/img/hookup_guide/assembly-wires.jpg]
Soldering wires

<figcaption markdown>Soldering wires to the Qwiic Hall-Effect Sensor board.</figcaption>
</figure>

### Headers
When [selecting headers](https://www.sparkfun.com/categories/381), be sure you are aware of the functionality or physical arrangement required.

<figure markdown>
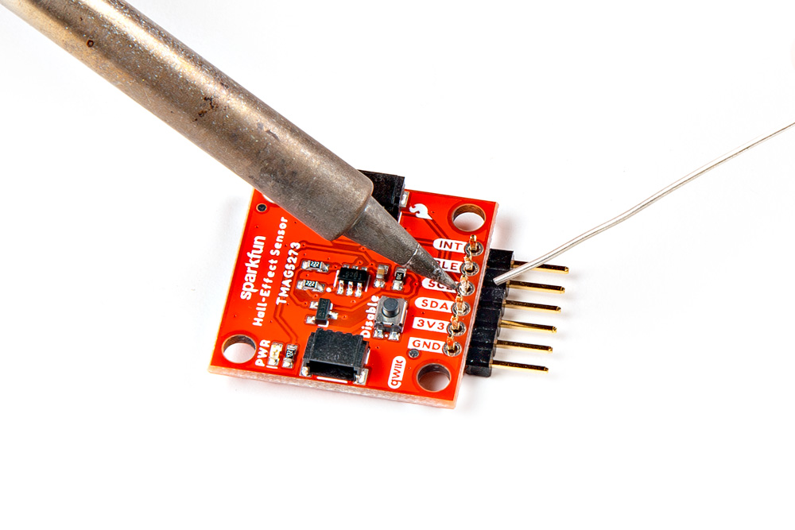
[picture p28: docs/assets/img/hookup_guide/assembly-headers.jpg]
Soldering headers

<figcaption markdown>Soldering [headers](https://www.sparkfun.com/products/116) to the Qwiic Hall-Effect Sensor board.</figcaption>
</figure>

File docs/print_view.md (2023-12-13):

---
hide:
  - navigation
  - toc
icon: material/printer
---

--8<-- "./docs/introduction.md:5"

# Hardware Overview
--8<-- "./docs/hardware_overview.md:5"

# Hardware Assembly
--8<-- "./docs/hardware_assembly.md:5"

# Software Overview
--8<-- "./docs/software_overview.md:5"

## Example - Basic
--8<-- "./docs/example_basic.md:2"

## Example - Interrupt
--8<-- "./docs/example_interrupt.md:2"

## Example - Angle Calculation
--8<-- "./docs/example_angle_calculation.md:2"

# Troubleshooting Tips
--8<-- "./docs/troubleshooting_tips.md:5"

# Resources
--8<-- "./docs/resources.md"

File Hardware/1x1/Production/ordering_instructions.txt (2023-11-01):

panel size, 117x117mm
PCB thickness, 1.6mm
number of layers, 2
soldermask color, Red
silkscreen color, White
oz copper, 1oz
finish, HASL lead free
stencils, top
pcs per panel, 16
min trace width, 0.2540mm / 0.0100in
min drill size, 0.3048mm / 0.0120in

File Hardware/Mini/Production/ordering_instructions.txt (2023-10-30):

panel size, 169x93mm
PCB thickness, 1.6mm
number of layers, 2
soldermask color, Red
silkscreen color, White
oz copper, 1oz
finish, HASL lead free
stencils, top+bottom
pcs per panel, 36
min trace width, 0.2540mm / 0.0100in
min drill size, 0.3048mm / 0.0120in

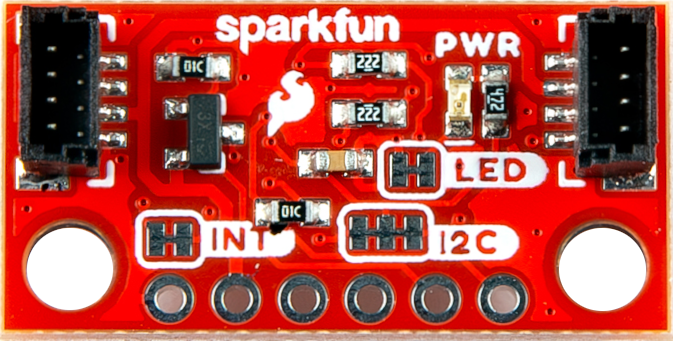
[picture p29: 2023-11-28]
docs/assets/img/hookup_guide/23881-bottom.png

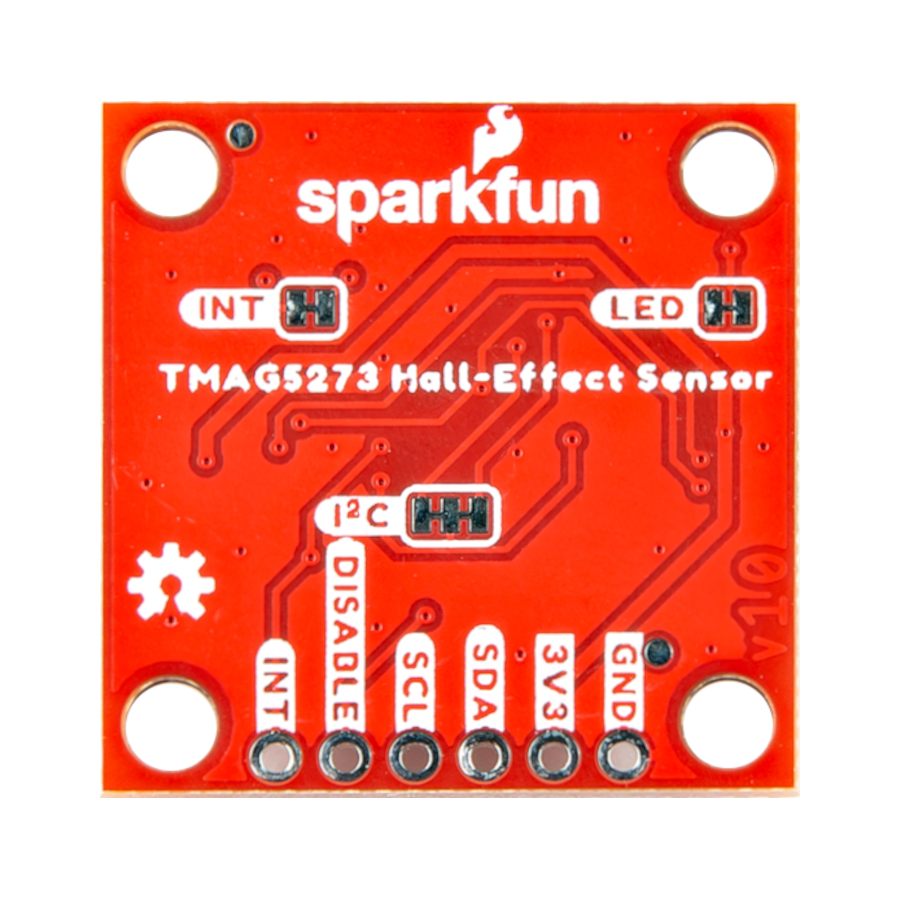
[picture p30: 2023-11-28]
docs/assets/img/hookup_guide/23880-template_bottom.png

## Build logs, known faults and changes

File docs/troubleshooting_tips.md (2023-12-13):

---
icon: sfe-logo
---

!!! warning "Need Help?"
	If you need technical assistance or more information on a product that is not working as you expected, we recommend heading on over to the [SparkFun Technical Assistance](https://www.sparkfun.com/technical_assistanc) page for some initial troubleshooting.

	<center>
	[SparkFun Technical Assistance Page](https://www.sparkfun.com/technical_assistance){ .md-button .md-button--primary }
	</center>
	
	If you can't find what you need there, the [SparkFun Forums](https://forum.sparkfun.com/index.php) is a great place to search product forums and ask questions.
	
	!!! info "Account Registration Required"
		If this is your first visit to our forum, you'll need to create a [Forum Account](https://forum.sparkfun.com/ucp.php?mode=register) to post questions.

### `PWR` LED dims when the board is disabled

The `PWR` LED on the Qwiic hall-effect sensor may only dim when it is disabled through the ++"Disable"++ button or `DISABLE` PTH pin. This will occur when the Qwiic hall-effect sensor is used in conjunction with development boards that have pull-up resistors on their `SDA` and `SCL` pins.

The combination of the pull-up resistors on the development board and the Qwiic hall-effect sensor will bypass the `DISABLE` pin's power cut-off circuitry. This results in the development board back-powering the Qwiic hall-effect sensor and its LED. In most circumstances, users shouldn't experience any issues, as the sensor should be within the under-voltage threshold and still reset.[^1] However, if the issue persists, users can disconnect the pull-up resistors on the Qwiic hall-effect sensor by cutting the `I2C` jumper.

[^1]: We have thoroughly tested this issue with all of our development boards and have found that the Qwiic hall-effect sensor will still reset, when disabled because the sensor will be within its under-voltage threshold.

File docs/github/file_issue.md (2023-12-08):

# Did we make a mistake?

Spot something wrong? Please let us know. 

<!-- Technical Assistance Box -->
!!! warning "Need Help?"
	If you need technical assistance or more information on a product that is not working as you expected, we recommend heading on over to the [SparkFun Technical Assistance](https://www.sparkfun.com/technical_assistanc) page for some initial troubleshooting. This **Submit Issues** page is not where users should seek assistance.

	<center>
	[SparkFun Technical Assistance Page](https://www.sparkfun.com/technical_assistance){ .md-button .md-button--primary }
	</center>
	
	If you can't find what you need there, the [SparkFun Forums](https://forum.sparkfun.com/index.php) is a great place to search the product forums and ask questions.
	
	!!! info "Account Registration Required"
		For your first visit to our forum, you'll need to create a [Forum Account](https://forum.sparkfun.com/ucp.php?mode=register) to post questions.

## :material-file-document-multiple:&nbsp;Discrepancies in the Documentation

All of our documentation can be modified by you! Please help us make it better.

* The documentation files for these pages are contained in the [`docs` folder](https://github.com/sparkfun/SparkFun_Qwiic_Hall_Effect_Sensor_TMAG5273/tree/main/docs) of the [SparkFun Qwiic Hall-Effect Sensor TMAG5273 repository](https://github.com/sparkfun/SparkFun_Qwiic_Hall_Effect_Sensor_TMAG5273).

### 🔍 Spot something wrong?

If a section of the documentation is incorrect, please [open an issue](https://github.com/sparkfun/SparkFun_Qwiic_Hall_Effect_Sensor_TMAG5273/issues) and let us know.

### Do you have a suggested correction?

Please, refer to the [Contribute](../contribute/#improve-our-documentation) page.

<!-- 
1. With a GitHub account, [fork this repository](https://github.com/sparkfun/SparkFun_Qwiic_Hall_Effect_Sensor_TMAG5273/fork).
2. Add your correction(s) or improvement(s) to the markdown file(s)
3. File a pull request with your changes, and enjoy making the ~~words~~ ~~worlds~~ world a better place.
	* Once received, the documentation specialist will automatically be notified.
	* We will review your suggested improvement(s) to make sure they are correct and fit within our documentation standards. -->

## :material-cog:&nbsp;Problems in the Hardware Design

All of our designs are open-source! Please help us make it better.

* Our board design files are contained in the [`Hardware` folder](https://github.com/sparkfun/SparkFun_Qwiic_Hall_Effect_Sensor_TMAG5273/tree/main/Hardware) of the [SparkFun Qwiic Hall-Effect Sensor TMAG5273 repository](https://github.com/sparkfun/SparkFun_Qwiic_Hall_Effect_Sensor_TMAG5273).

### Does something not make sense? 🤔

If part of the design is confusing, please [open an issue](https://github.com/sparkfun/SparkFun_Qwiic_Hall_Effect_Sensor_TMAG5273/issues) and let us know.

### Did we forget to include an important function of the board? 🤦

If part of the board's functionality is missing, please [open an issue](https://github.com/sparkfun/SparkFun_Qwiic_Hall_Effect_Sensor_TMAG5273/issues) and file a feature request.

!!! tip "Design Considerations"
	Please keep in mind that we may intentionally exclude certain functions of the board to meet our product design requirements.

	* *For example, our Qwiic Micro boards are intended to fit on a small board layout and only use I<sup>2</sup>C communication; therefore, we may not have the SPI and interrupt pins available for users.*

### Do you wish to contribute directly to improving the board design?

Please, refer to the [Contribute](../contribute/#improve-our-hardware-design) page.

<!-- 1. With a GitHub account, [fork this repository](https://github.com/sparkfun/SparkFun_Qwiic_Hall_Effect_Sensor_TMAG5273/fork).
2. Add your design augmentation(s)
3. File a pull request with your changes, and enjoy making the ~~words~~ ~~worlds~~ world a better place.
	1. Once received, the engineer in charge of the original design will automatically be notified.
	2. We will review your suggested improvement(s) to verify that they are within our board design standards and meet our product design requirements.
	3. If approved, we will flag these changes for our next board revision. Congrats! 🍻

		!!! info
			Even if your suggestion is accepted, these changes may not be immediately available for purchase. We may have to cycle through our current product inventory first. -->

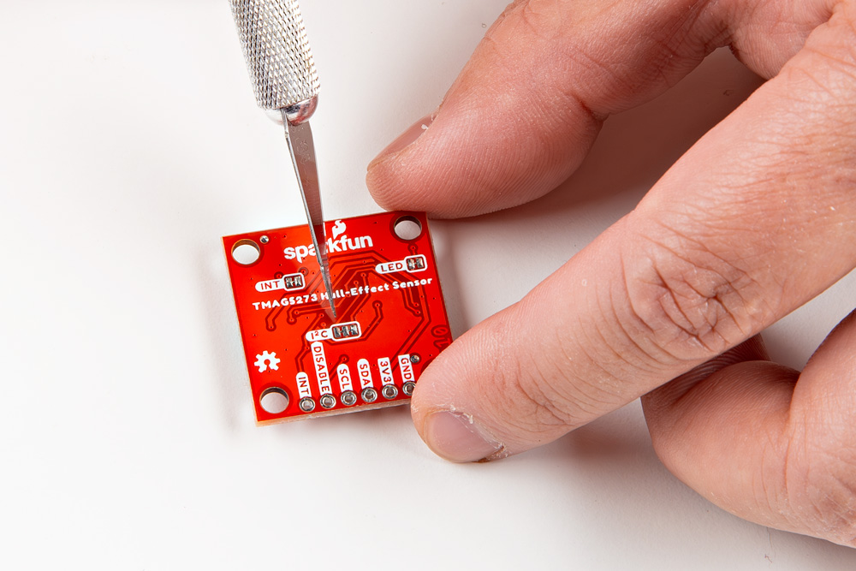
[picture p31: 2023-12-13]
docs/assets/img/hookup_guide/troubleshoot-i2c_jumper.jpg

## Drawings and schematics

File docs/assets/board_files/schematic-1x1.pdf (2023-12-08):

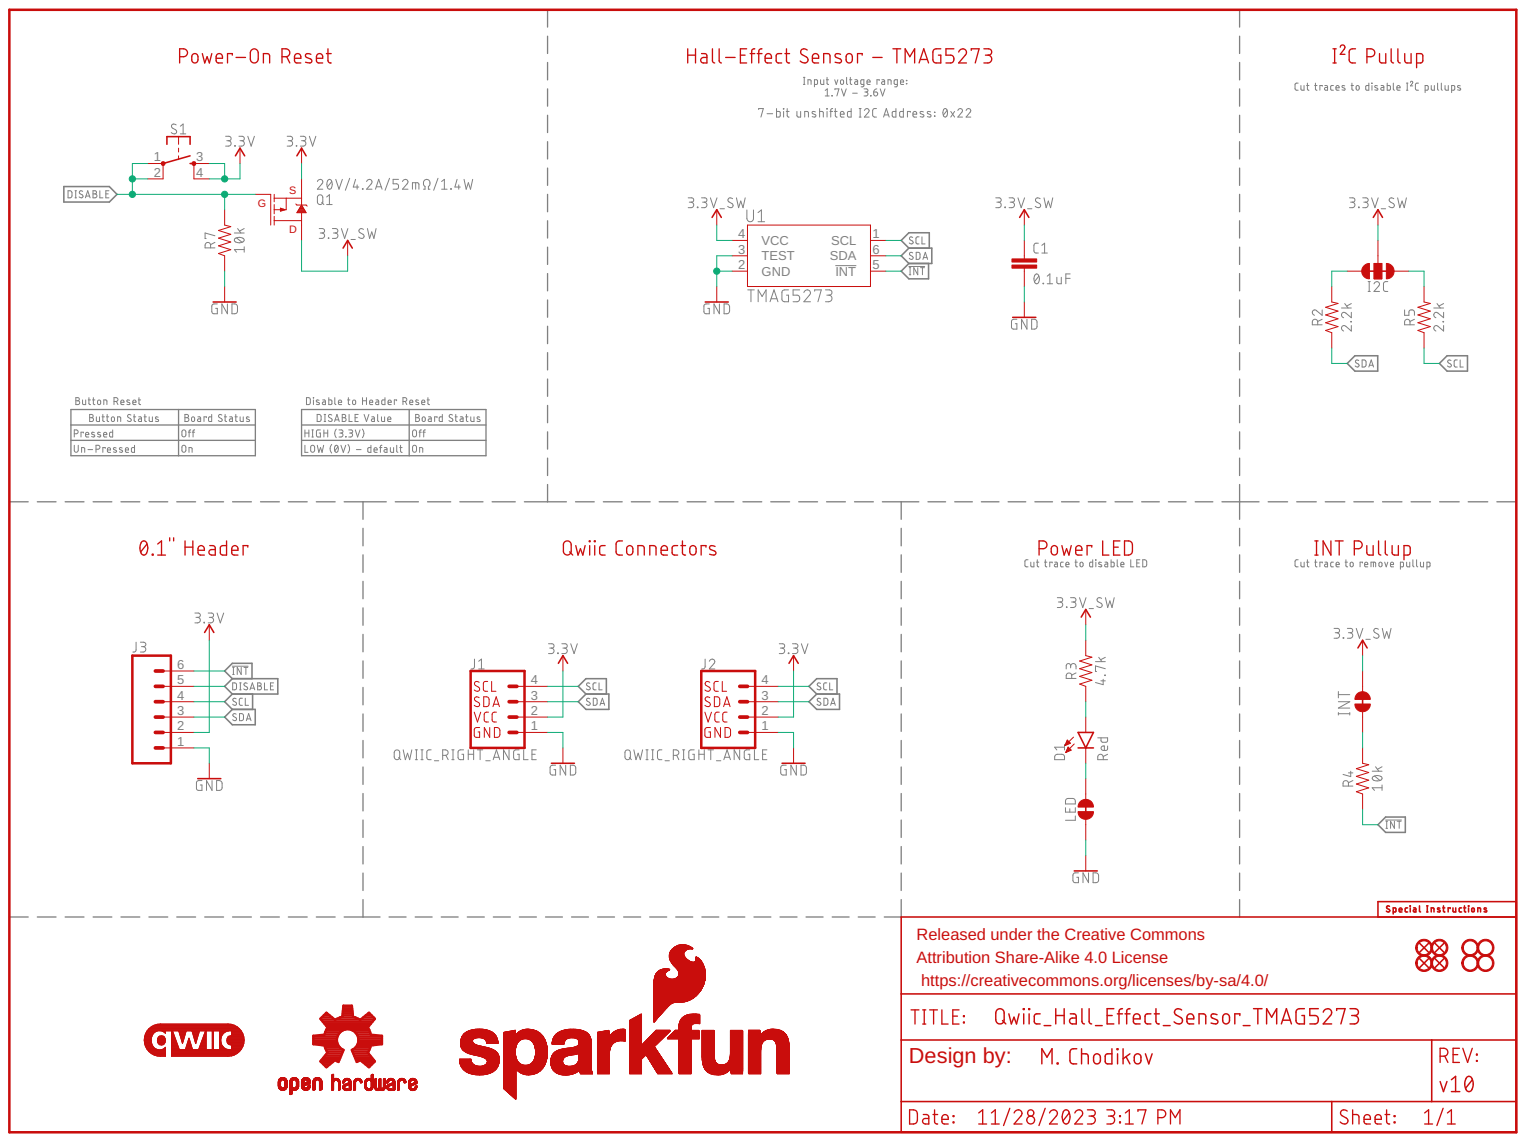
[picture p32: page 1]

Released under the Creative Commons
Attribution Share-Alike 4.0 License
https://creativecommons.org/licenses/by-sa/4.0/

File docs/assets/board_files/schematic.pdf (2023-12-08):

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

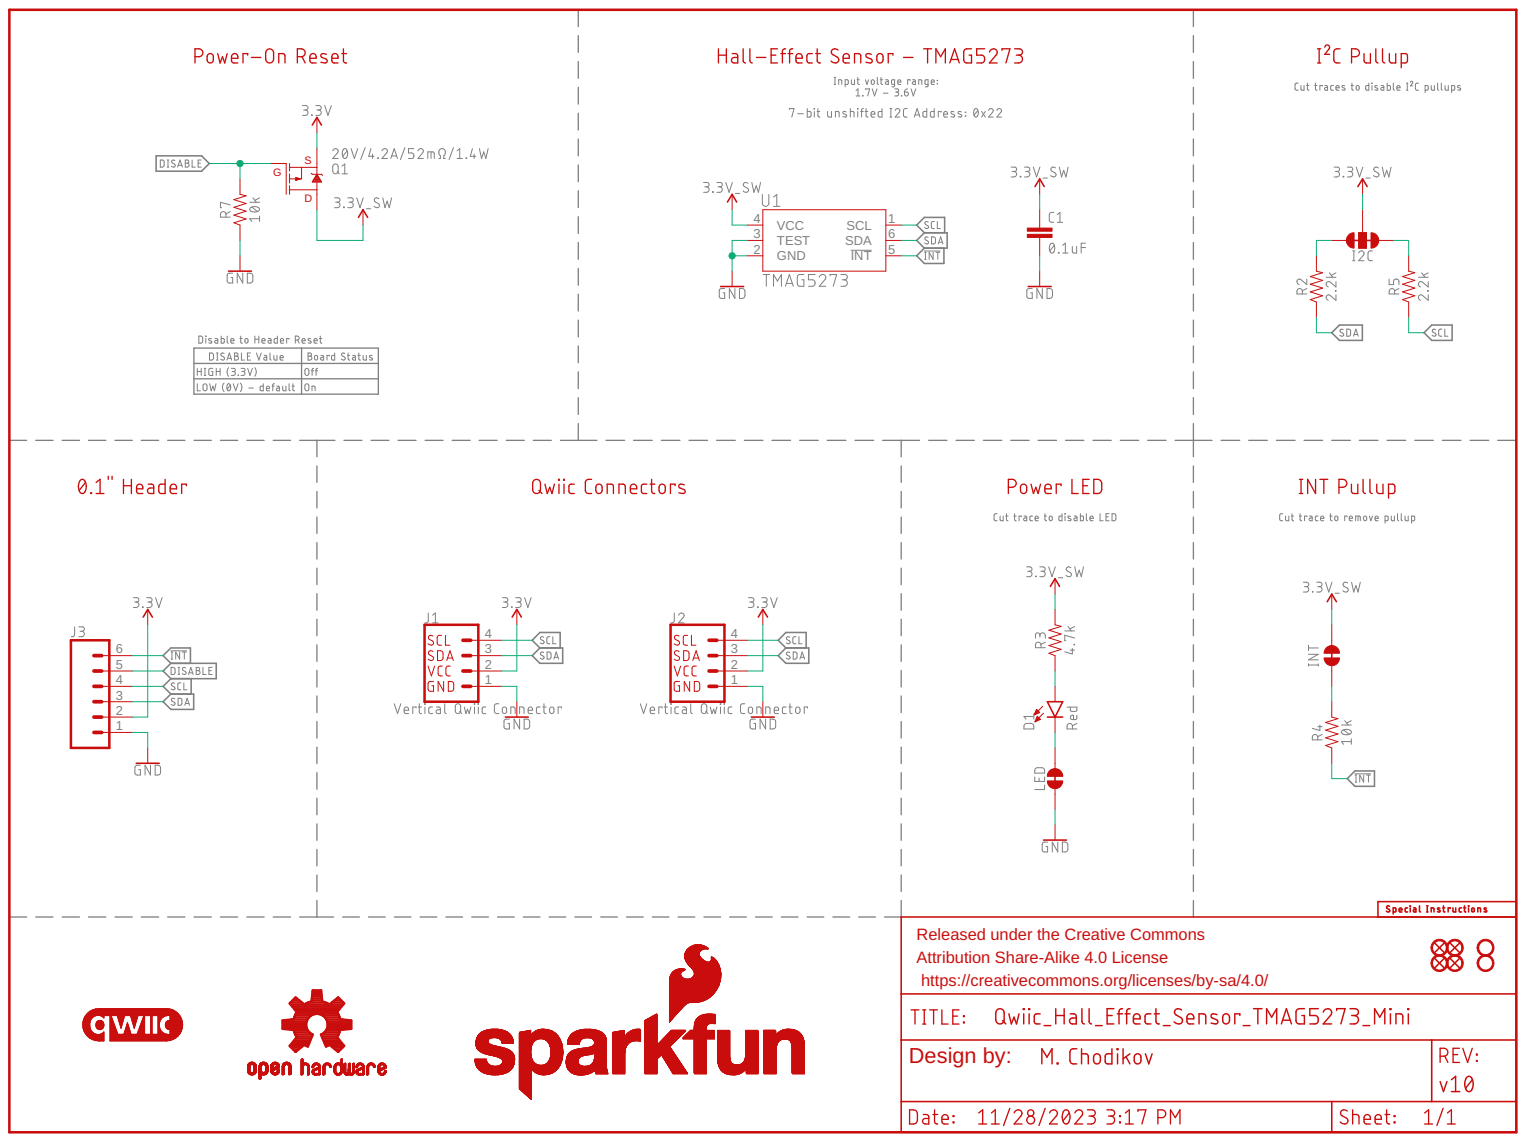
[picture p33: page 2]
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

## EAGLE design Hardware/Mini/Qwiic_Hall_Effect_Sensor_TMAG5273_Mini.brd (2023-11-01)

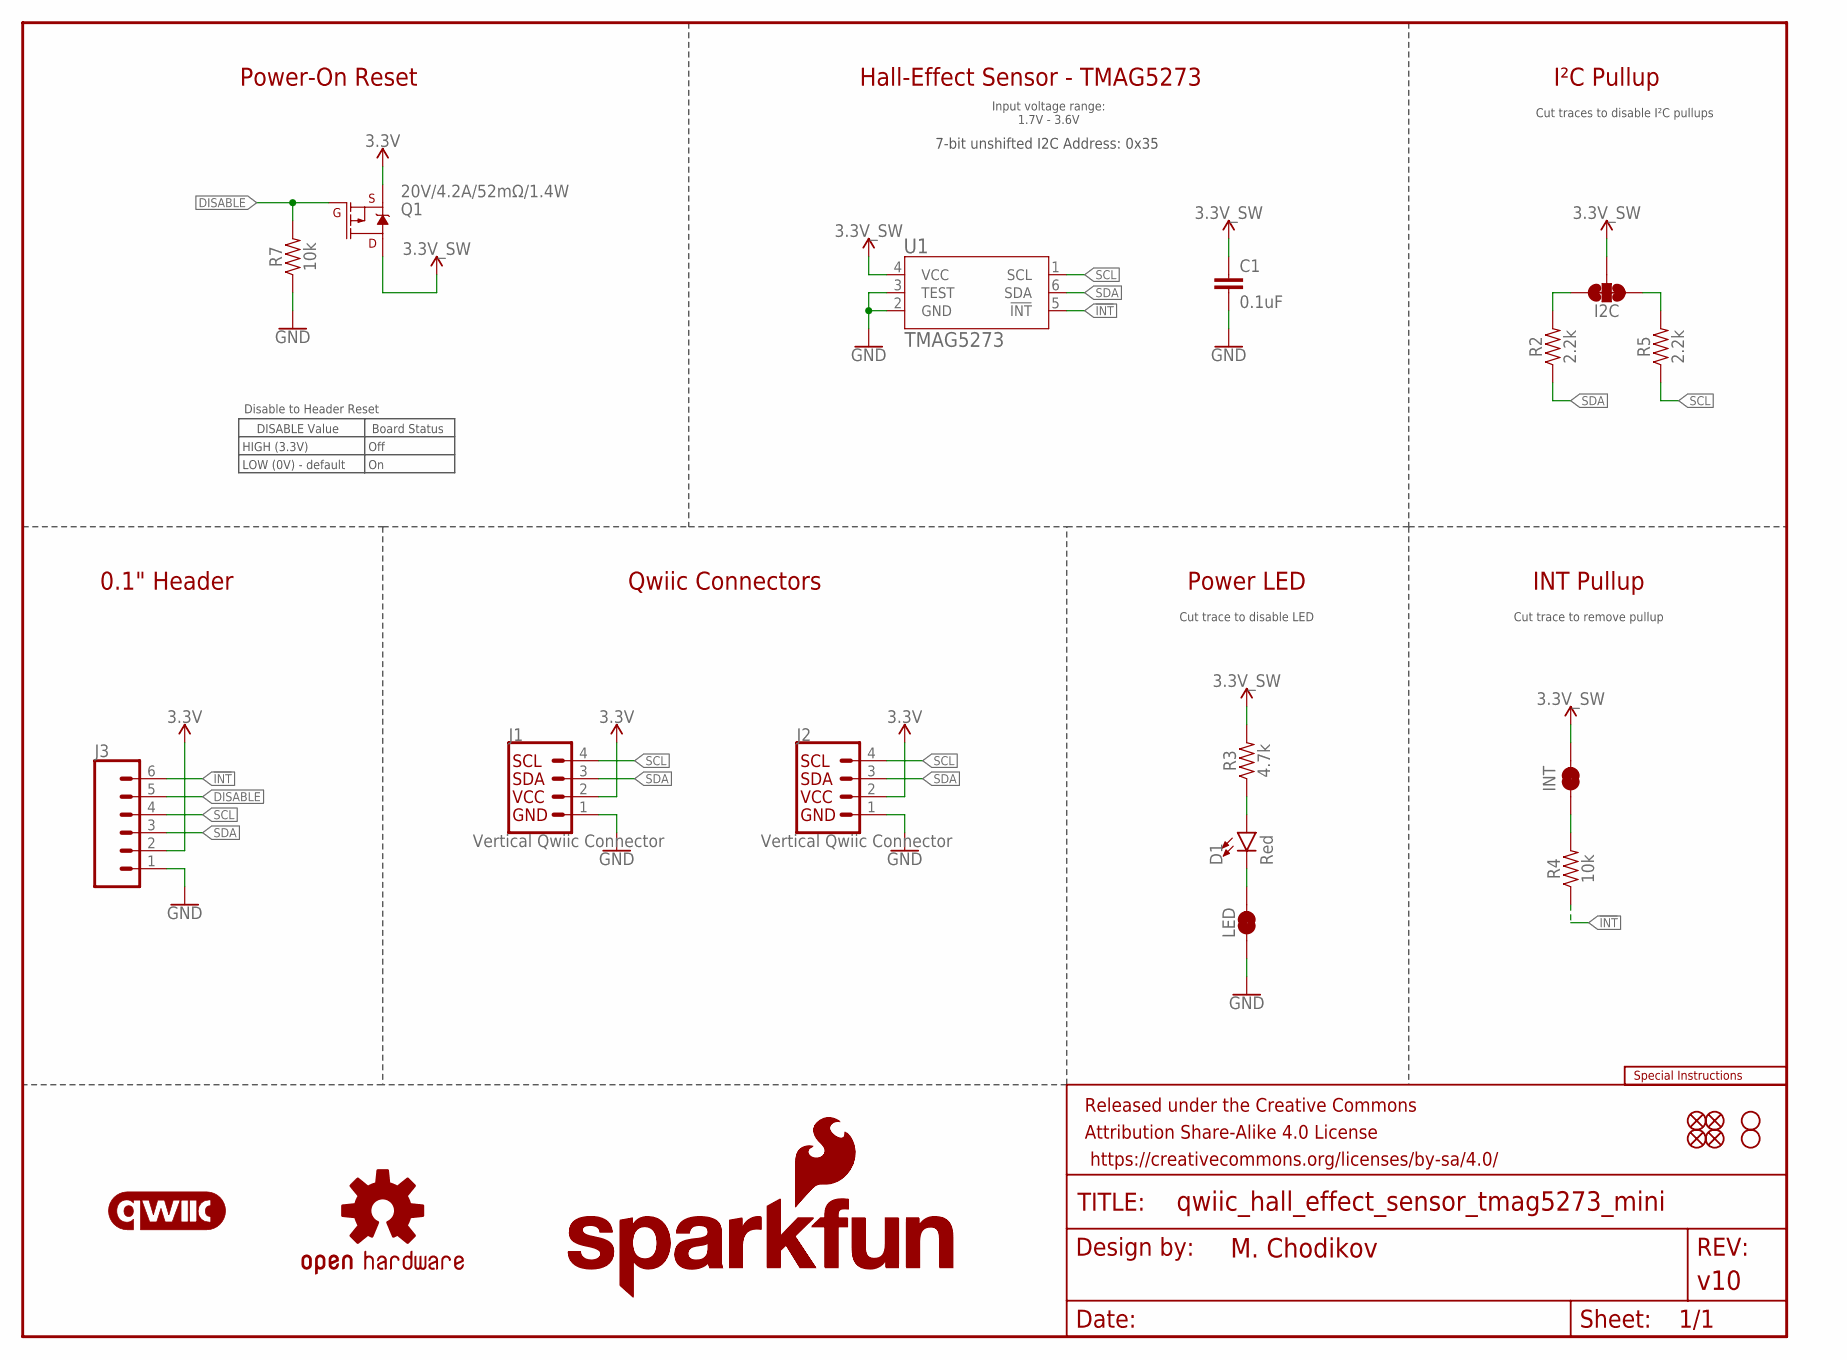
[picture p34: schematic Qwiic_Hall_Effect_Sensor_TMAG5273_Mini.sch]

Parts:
C1: 0.1uF; 0603
D1: Red; LED-0603
FD1, FD2, FD3, FD4: FIDUCIAL1X2; FIDUCIAL-1X2
FRAME1: FRAME-LETTER; CREATIVE_COMMONS
H2, H4: STAND-OFF
I2C: JUMPER-SMT_3_2-NC_TRACE_SILK; SMT-JUMPER_3_2-NC_TRACE_SILK
INT: JUMPER-SMT_2_NC_TRACE_SILK; SMT-JUMPER_2_NC_TRACE_SILK
J1, J2: Vertical Qwiic Connector; JST04_1MM_VERT
J3: CONN_06NO_SILK_FEMALE_PTH; 1X06_NO_SILK
LED: JUMPER-SMT_2_NC_TRACE_SILK; SMT-JUMPER_2_NC_TRACE_SILK
LOGO1: OSHW-LOGOMINI; OSHW-LOGO-MINI
LOGO2: SFE_LOGO_NAME_FLAME5_MM; SFE_LOGO_NAME_FLAME_5MM
LOGO3: QWIIC_LOGO_4MM; QWIIC_4MM
LOGO4: SFE_LOGO_NAME7_MM; SFE_LOGO_NAME_7MM
LOGO5: SPECIAL_INSTRUCTIONS-ORDERING; ORDERING_INSTRUCTIONS
LOGO6: SFE_LOGO_FLAME.1_INCH; SFE_LOGO_FLAME_.1
Q1: 20V/4.2A/52mΩ/1.4W; SOT23-3
R2, R5: 2.2k; 0603
R3: 4.7k; 0603
R4, R7: 10k; 0603
U1: TMAG5273; SOT23-6_DBV_TEX

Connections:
3.3V: J1.2, J2.2, J3.2, Q1.2 (S)
3.3V_SW: C1.1, I2C.2, INT.2, Q1.3 (D), R3.2, U1.4 (VCC)
!INT: J3.6, R4.1, U1.5 (!INT)
DISABLE: J3.5, Q1.1 (G), R7.2
GND: C1.2, J1.1, J2.1, J3.1, LED.1, R7.1, U1.2 (GND), U1.3 (TEST)
unnamed: D1.C, LED.2
unnamed: I2C.3, R2.2
unnamed: D1.A, R3.1
unnamed: INT.1, R4.2
unnamed: I2C.1, R5.2
SCL: J1.4, J2.4, J3.4, R5.1, U1.1 (SCL)
SDA: J1.3, J2.3, J3.3, R2.1, U1.6 (SDA)

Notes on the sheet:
7-bit unshifted I2C Address: 0x35
Hall-Effect Sensor - TMAG5273
I²C Pullup
Cut traces to disable I²C pullups
Input voltage range: 1.7V - 3.6V
Cut trace to disable LED
Power LED
Cut trace to remove pullup
INT Pullup
0.1" Header
Qwiic Connectors
Power-On Reset
Disable to Header Reset
DISABLE Value
HIGH (3.3V)
LOW (0V) - default
Off
Board Status

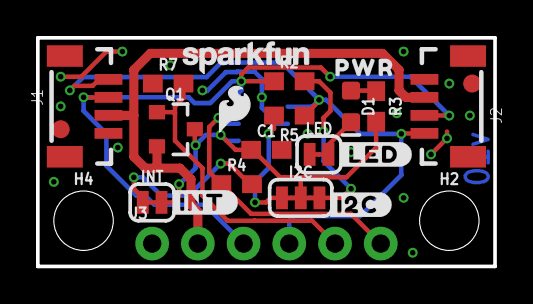
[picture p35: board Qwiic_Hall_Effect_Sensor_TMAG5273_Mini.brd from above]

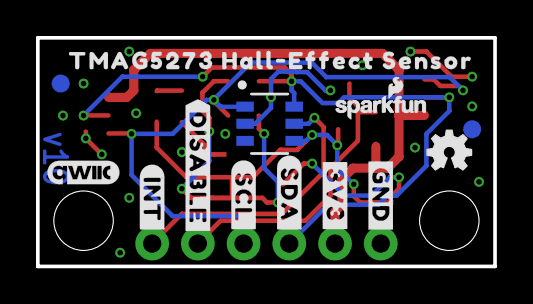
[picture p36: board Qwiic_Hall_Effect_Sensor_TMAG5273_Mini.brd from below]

Board: 2 copper layers, 25.4 x 12.7 mm, 39 parts (13 on the bottom side), 12 nets.

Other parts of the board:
U$1: PWR5282
U$2: #SCL#38
U$3: #SDA#37
U$4: #3V3#37
U$5: #GND#36
U$6: TMAG5273_HALL#EFFECT_SENSOR0
U$7: #DISABLE#5291
U$8: #I2C#5276
U$9: #INT#5285
U$10: #LED#5275
U$12: #INT#5287

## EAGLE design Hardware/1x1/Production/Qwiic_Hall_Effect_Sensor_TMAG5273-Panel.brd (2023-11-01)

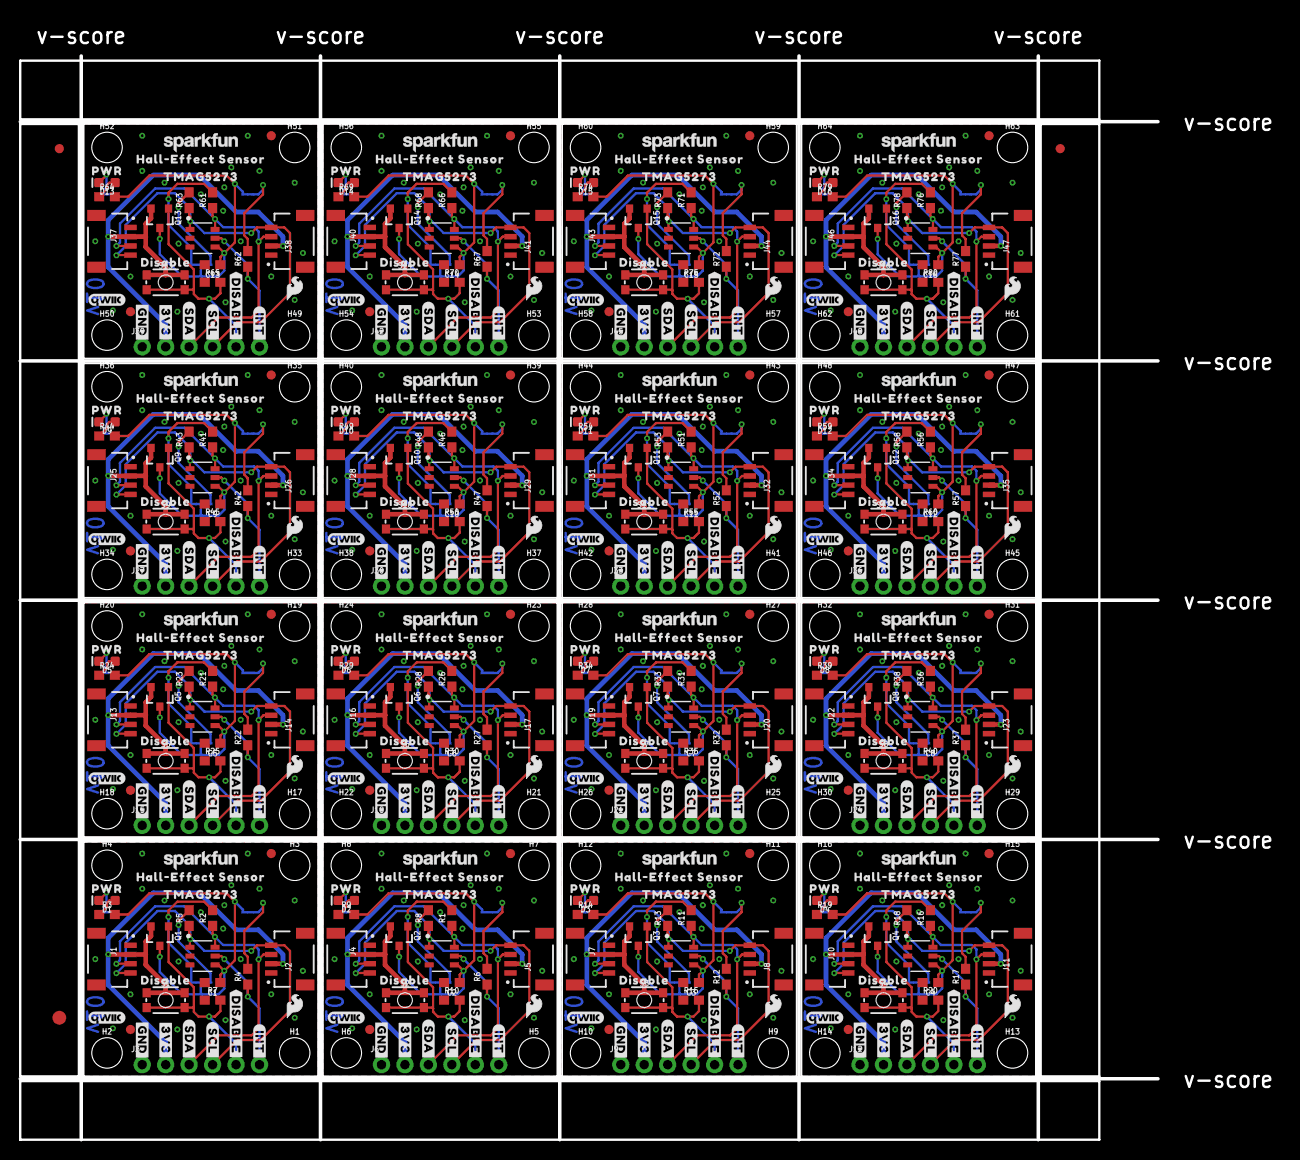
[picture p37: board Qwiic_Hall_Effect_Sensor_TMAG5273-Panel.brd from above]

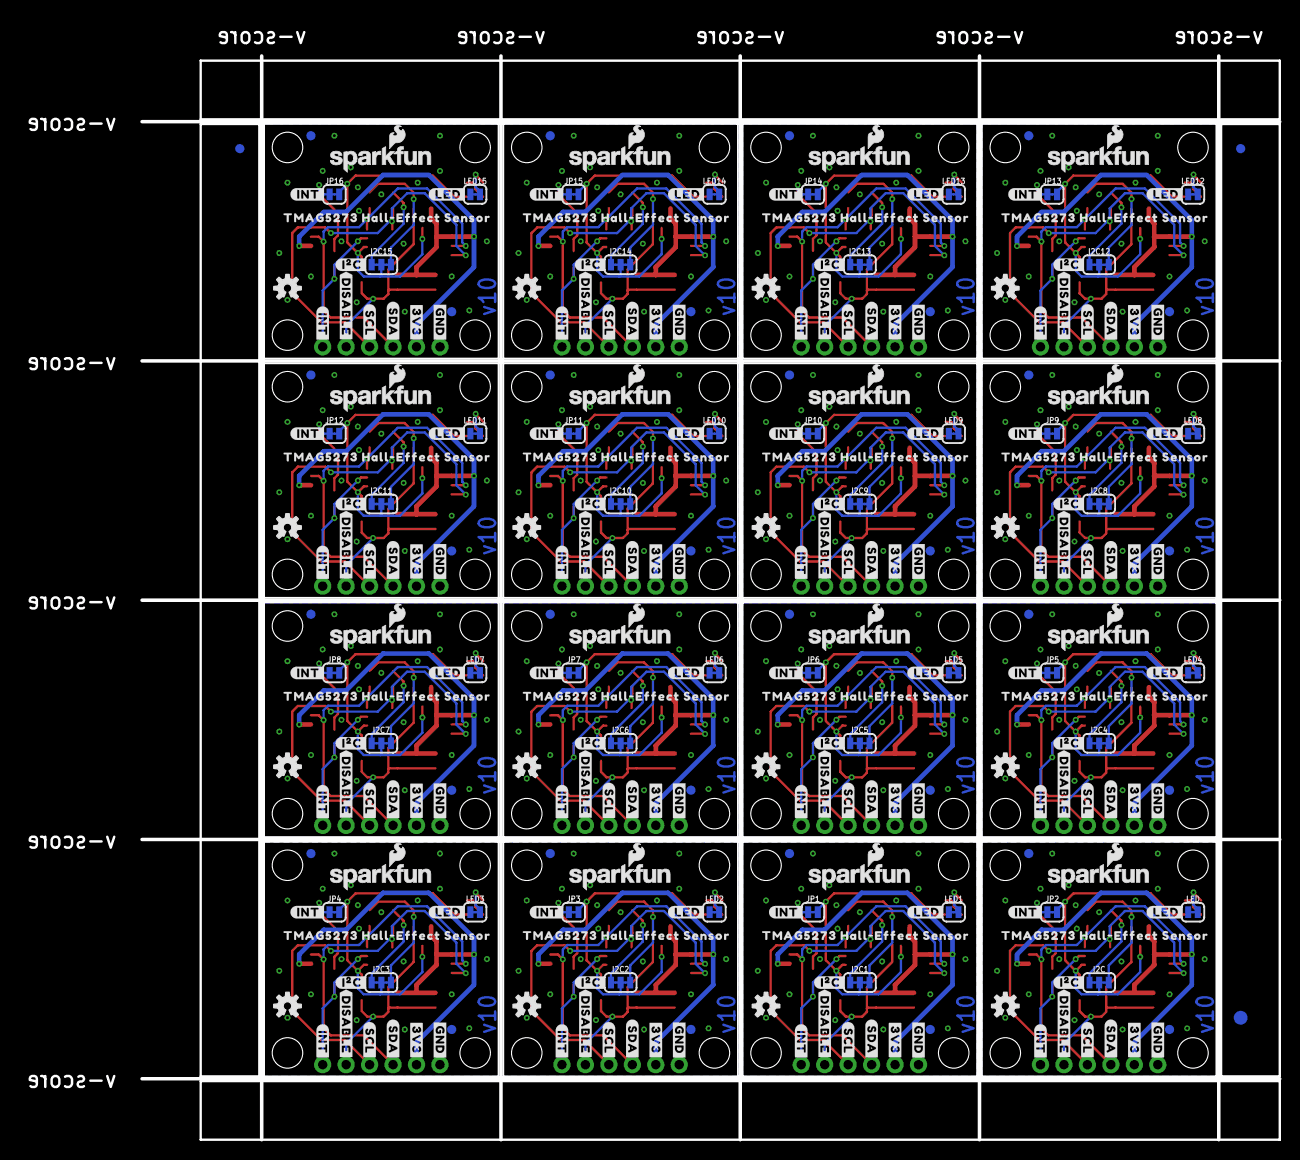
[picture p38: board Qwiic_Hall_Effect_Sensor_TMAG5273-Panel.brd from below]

Board: 2 copper layers, 123.2 x 117.3 mm, 790 parts (275 on the bottom side), 192 nets.

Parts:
C1, C2, C3, C4, C5, C6, C7, C8, C9, C10, C11, C12, C13, C14, C15, C16: 0.1uF; 0603
D1, D2, D3, D4, D5, D6, D7, D8, D9, D10, D11, D12, D13, D14, D15, D16: Red; LED-0603
E$1, E$2, E$3, E$4: FIDUCIAL-1X2
E$5, E$6: FIDUCIAL-1.5X3
FD1, FD2, FD3, FD4, FD5, FD6, FD7, FD8, FD9, FD10, FD11, FD12, FD13, FD14, FD15, FD16, FD17, FD18, FD19, FD20, FD21, FD22, FD23, FD24, FD25, FD26, FD27, FD28, FD29, FD30, FD31, FD32, FD33, FD34, FD35, FD36, FD37, FD38, FD39, FD40, FD41, FD42, FD43, FD44, FD45, FD46, FD47, FD48, FD49, FD50, FD51, FD52, FD53, FD54, FD55, FD56, FD57, FD58, FD59, FD60, FD61, FD62, FD63, FD64: FIDUCIAL1X2; FIDUCIAL-1X2
H1, H2, H3, H4, H5, H6, H7, H8, H9, H10, H11, H12, H13, H14, H15, H16, H17, H18, H19, H20, H21, H22, H23, H24, H25, H26, H27, H28, H29, H30, H31, H32, H33, H34, H35, H36, H37, H38, H39, H40, H41, H42, H43, H44, H45, H46, H47, H48, H49, H50, H51, H52, H53, H54, H55, H56, H57, H58, H59, H60, H61, H62, H63, H64: STAND-OFF
I2C, I2C1, I2C2, I2C3, I2C4, I2C5, I2C6, I2C7, I2C8, I2C9, I2C10, I2C11, I2C12, I2C13, I2C14, I2C15: JUMPER-SMT_3_2-NC_TRACE_SILK; SMT-JUMPER_3_2-NC_TRACE_SILK
J1, J2, J4, J5, J7, J8, J10, J11, J13, J14, J16, J17, J19, J20, J22, J23, J25, J26, J28, J29, J31, J32, J34, J35, J37, J38, J40, J41, J43, J44, J46, J47: QWIIC_RIGHT_ANGLE; JST04_1MM_RA
J3, J6, J9, J12, J15, J18, J21, J24, J27, J30, J33, J36, J39, J42, J45, J48: 1X06_NO_SILK
JP1, JP2, JP3, JP4, JP5, JP6, JP7, JP8, JP9, JP10, JP11, JP12, JP13, JP14, JP15, JP16: JUMPER-SMT_2_NC_TRACE_SILK; SMT-JUMPER_2_NC_TRACE_SILK
LED, LED1, LED2, LED3, LED4, LED5, LED6, LED7, LED8, LED9, LED10, LED11, LED12, LED13, LED14, LED15: JUMPER-SMT_2_NC_TRACE_SILK; SMT-JUMPER_2_NC_TRACE_SILK
LOGO1, LOGO5, LOGO11, LOGO16, LOGO21, LOGO26, LOGO31, LOGO36, LOGO41, LOGO46, LOGO51, LOGO56, LOGO61, LOGO66, LOGO71, LOGO76: OSHW-LOGOS; OSHW-LOGO-S
LOGO2, LOGO7, LOGO12, LOGO17, LOGO22, LOGO27, LOGO32, LOGO37, LOGO42, LOGO47, LOGO52, LOGO57, LOGO62, LOGO67, LOGO72, LOGO77: SFE_LOGO_NAME_FLAME.1_INCH; SFE_LOGO_NAME_FLAME_.1
LOGO3, LOGO8, LOGO13, LOGO18, LOGO23, LOGO28, LOGO33, LOGO38, LOGO43, LOGO48, LOGO53, LOGO58, LOGO63, LOGO68, LOGO73, LOGO78: QWIIC_LOGO_4MM; QWIIC_4MM
LOGO4, LOGO9, LOGO14, LOGO19, LOGO24, LOGO29, LOGO34, LOGO39, LOGO44, LOGO49, LOGO54, LOGO59, LOGO64, LOGO69, LOGO74, LOGO79: SFE_LOGO_NAME8_MM; SFE_LOGO_NAME_8MM
LOGO6, LOGO10, LOGO15, LOGO20, LOGO25, LOGO30, LOGO35, LOGO40, LOGO45, LOGO50, LOGO55, LOGO60, LOGO65, LOGO70, LOGO75, LOGO80: SFE_LOGO_FLAME.1_INCH; SFE_LOGO_FLAME_.1
Q1, Q2, Q3, Q4, Q5, Q6, Q7, Q8, Q9, Q10, Q11, Q12, Q13, Q14, Q15, Q16: 20V/4.2A/52mΩ/1.4W; SOT23-3
R1, R2, R5, R8, R11, R13, R16, R18, R21, R23, R26, R28, R31, R33, R36, R38, R41, R43, R46, R48, R51, R53, R56, R58, R61, R63, R66, R68, R71, R73, R76, R78: 2.2k; 0603
R3, R9, R14, R19, R24, R29, R34, R39, R44, R49, R54, R59, R64, R69, R74, R79: 4.7k; 0603
R4, R6, R7, R10, R12, R15, R17, R20, R22, R25, R27, R30, R32, R35, R37, R40, R42, R45, R47, R50, R52, R55, R57, R60, R62, R65, R67, R70, R72, R75, R77, R80: 10k; 0603
S1, S2, S3, S4, S5, S6, S7, S8, S9, S10, S11, S12, S13, S14, S15, S16: TACTILE_SWITCH_SMD_4.6X2.8MM
U1, U2, U3, U4, U5, U6, U7, U8, U9, U10, U11, U12, U13, U14, U15, U16: TMAG5273; SOT23-6_DBV_TEX
U$1, U$22, U$42, U$62, U$82, U$102, U$122, U$142, U$162, U$182, U$202, U$222, U$242, U$262, U$282, U$302: #3V3#37
U$2, U$21, U$41, U$61, U$81, U$101, U$121, U$141, U$161, U$181, U$201, U$221, U$241, U$261, U$281, U$301: #GND#36
U$3, U$23, U$43, U$63, U$83, U$103, U$123, U$143, U$163, U$183, U$203, U$223, U$243, U$263, U$283, U$303: #SDA#37
U$4, U$24, U$44, U$64, U$84, U$104, U$124, U$144, U$164, U$184, U$204, U$224, U$244, U$264, U$284, U$304: #SCL#38
U$5, U$17, U$36, U$37, U$56, U$57, U$76, U$77, U$96, U$97, U$116, U$117, U$136, U$137, U$156, U$157, U$176, U$177, U$196, U$197, U$216, U$217, U$236, U$237, U$256, U$257, U$276, U$277, U$296, U$297, U$316, U$317: #INT#5285
U$6, U$38, U$58, U$78, U$98, U$118, U$138, U$158, U$178, U$198, U$218, U$238, U$258, U$278, U$298, U$318: #INT#5289
U$7, U$25, U$45, U$65, U$85, U$105, U$125, U$145, U$165, U$185, U$205, U$225, U$245, U$265, U$285, U$305: PWR41
U$8, U$26, U$46, U$66, U$86, U$106, U$126, U$146, U$166, U$186, U$206, U$226, U$246, U$266, U$286, U$306: #LED#42
U$9, U$15, U$39, U$40, U$59, U$60, U$79, U$80, U$99, U$100, U$119, U$120, U$139, U$140, U$159, U$160, U$179, U$180, U$199, U$200, U$219, U$220, U$239, U$240, U$259, U$260, U$279, U$280, U$299, U$300, U$319, U$320: #DISABLE#5290
U$10, U$27, U$47, U$67, U$87, U$107, U$127, U$147, U$167, U$187, U$207, U$227, U$247, U$267, U$287, U$307: #I�C#0
U$11, U$28, U$48, U$68, U$88, U$108, U$128, U$148, U$168, U$188, U$208, U$228, U$248, U$268, U$288, U$308: HALL#EFFECT_SENSOR45
U$12, U$29, U$49, U$69, U$89, U$109, U$129, U$149, U$169, U$189, U$209, U$229, U$249, U$269, U$289, U$309: TMAG527346
U$13, U$35, U$55, U$75, U$95, U$115, U$135, U$155, U$175, U$195, U$215, U$235, U$255, U$275, U$295, U$315: DISABLE5281
U$14, U$30, U$50, U$70, U$90, U$110, U$130, U$150, U$170, U$190, U$210, U$230, U$250, U$270, U$290, U$310: #SDA#5280
U$16, U$31, U$51, U$71, U$91, U$111, U$131, U$151, U$171, U$191, U$211, U$231, U$251, U$271, U$291, U$311: #SCL#5281
U$18, U$32, U$52, U$72, U$92, U$112, U$132, U$152, U$172, U$192, U$212, U$232, U$252, U$272, U$292, U$312: #3V3#0
U$19, U$33, U$53, U$73, U$93, U$113, U$133, U$153, U$173, U$193, U$213, U$233, U$253, U$273, U$293, U$313: #GND#4
U$20, U$34, U$54, U$74, U$94, U$114, U$134, U$154, U$174, U$194, U$214, U$234, U$254, U$274, U$294, U$314: TMAG5273_HALL#EFFECT_SENSOR5

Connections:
3.3V: J1.2, J2.2, J3.2, Q1.2, S1.3, S1.4
3.3V1: J4.2, J5.2, J6.2, Q2.2, S2.3, S2.4
3.3V2: J7.2, J8.2, J9.2, Q3.2, S3.3, S3.4
3.3V3: J10.2, J11.2, J12.2, Q4.2, S4.3, S4.4
3.3V4: J13.2, J14.2, J15.2, Q5.2, S5.3, S5.4
3.3V5: J16.2, J17.2, J18.2, Q6.2, S6.3, S6.4
3.3V6: J19.2, J20.2, J21.2, Q7.2, S7.3, S7.4
3.3V7: J22.2, J23.2, J24.2, Q8.2, S8.3, S8.4
3.3V8: J25.2, J26.2, J27.2, Q9.2, S9.3, S9.4
3.3V9: J28.2, J29.2, J30.2, Q10.2, S10.3, S10.4
3.3V10: J31.2, J32.2, J33.2, Q11.2, S11.3, S11.4
3.3V11: J34.2, J35.2, J36.2, Q12.2, S12.3, S12.4
3.3V12: J37.2, J38.2, J39.2, Q13.2, S13.3, S13.4
3.3V13: J40.2, J41.2, J42.2, Q14.2, S14.3, S14.4
3.3V14: J43.2, J44.2, J45.2, Q15.2, S15.3, S15.4
3.3V15: J46.2, J47.2, J48.2, Q16.2, S16.3, S16.4
3.3V_SW: C1.1, I2C.2, JP2.2, Q1.3, R3.2, U1.4
3.3V_SW1: C2.1, I2C1.2, JP1.2, Q2.3, R9.2, U2.4
3.3V_SW2: C3.1, I2C2.2, JP3.2, Q3.3, R14.2, U3.4
3.3V_SW3: C4.1, I2C3.2, JP4.2, Q4.3, R19.2, U4.4
3.3V_SW4: C5.1, I2C4.2, JP5.2, Q5.3, R24.2, U5.4
3.3V_SW5: C6.1, I2C5.2, JP6.2, Q6.3, R29.2, U6.4
3.3V_SW6: C7.1, I2C6.2, JP7.2, Q7.3, R34.2, U7.4
3.3V_SW7: C8.1, I2C7.2, JP8.2, Q8.3, R39.2, U8.4
3.3V_SW8: C9.1, I2C8.2, JP9.2, Q9.3, R44.2, U9.4
3.3V_SW9: C10.1, I2C9.2, JP10.2, Q10.3, R49.2, U10.4
3.3V_SW10: C11.1, I2C10.2, JP11.2, Q11.3, R54.2, U11.4
3.3V_SW11: C12.1, I2C11.2, JP12.2, Q12.3, R59.2, U12.4
3.3V_SW12: C13.1, I2C12.2, JP13.2, Q13.3, R64.2, U13.4
3.3V_SW13: C14.1, I2C13.2, JP14.2, Q14.3, R69.2, U14.4
3.3V_SW14: C15.1, I2C14.2, JP15.2, Q15.3, R74.2, U15.4
3.3V_SW15: C16.1, I2C15.2, JP16.2, Q16.3, R79.2, U16.4
!INT: J3.6, R4.1, U1.5
!INT1: J6.6, R6.1, U2.5
!INT2: J9.6, R12.1, U3.5
!INT3: J12.6, R17.1, U4.5
!INT4: J15.6, R22.1, U5.5
!INT5: J18.6, R27.1, U6.5
!INT6: J21.6, R32.1, U7.5
!INT7: J24.6, R37.1, U8.5
!INT8: J27.6, R42.1, U9.5
!INT9: J30.6, R47.1, U10.5
!INT10: J33.6, R52.1, U11.5
!INT11: J36.6, R57.1, U12.5
!INT12: J39.6, R62.1, U13.5
!INT13: J42.6, R67.1, U14.5
!INT14: J45.6, R72.1, U15.5
!INT15: J48.6, R77.1, U16.5
DISABLE: J3.5, Q1.1, R7.2, S1.1, S1.2
DISABLE1: J6.5, Q2.1, R10.2, S2.1, S2.2
DISABLE2: J9.5, Q3.1, R15.2, S3.1, S3.2
DISABLE3: J12.5, Q4.1, R20.2, S4.1, S4.2
DISABLE4: J15.5, Q5.1, R25.2, S5.1, S5.2
DISABLE5: J18.5, Q6.1, R30.2, S6.1, S6.2
DISABLE6: J21.5, Q7.1, R35.2, S7.1, S7.2
DISABLE7: J24.5, Q8.1, R40.2, S8.1, S8.2
DISABLE8: J27.5, Q9.1, R45.2, S9.1, S9.2
DISABLE9: J30.5, Q10.1, R50.2, S10.1, S10.2
DISABLE10: J33.5, Q11.1, R55.2, S11.1, S11.2
DISABLE11: J36.5, Q12.1, R60.2, S12.1, S12.2
DISABLE12: J39.5, Q13.1, R65.2, S13.1, S13.2
DISABLE13: J42.5, Q14.1, R70.2, S14.1, S14.2
DISABLE14: J45.5, Q15.1, R75.2, S15.1, S15.2
DISABLE15: J48.5, Q16.1, R80.2, S16.1, S16.2
GND: C1.2, J1.1, J2.1, J3.1, LED.1, R7.1, U1.2, U1.3
GND1: C2.2, J4.1, J5.1, J6.1, LED1.1, R10.1, U2.2, U2.3
GND2: C3.2, J7.1, J8.1, J9.1, LED2.1, R15.1, U3.2, U3.3
GND3: C4.2, J10.1, J11.1, J12.1, LED3.1, R20.1, U4.2, U4.3
GND4: C5.2, J13.1, J14.1, J15.1, LED4.1, R25.1, U5.2, U5.3
GND5: C6.2, J16.1, J17.1, J18.1, LED5.1, R30.1, U6.2, U6.3
GND6: C7.2, J19.1, J20.1, J21.1, LED6.1, R35.1, U7.2, U7.3
GND7: C8.2, J22.1, J23.1, J24.1, LED7.1, R40.1, U8.2, U8.3
GND8: C9.2, J25.1, J26.1, J27.1, LED8.1, R45.1, U9.2, U9.3
GND9: C10.2, J28.1, J29.1, J30.1, LED9.1, R50.1, U10.2, U10.3
GND10: C11.2, J31.1, J32.1, J33.1, LED10.1, R55.1, U11.2, U11.3
GND11: C12.2, J34.1, J35.1, J36.1, LED11.1, R60.1, U12.2, U12.3
GND12: C13.2, J37.1, J38.1, J39.1, LED12.1, R65.1, U13.2, U13.3
GND13: C14.2, J40.1, J41.1, J42.1, LED13.1, R70.1, U14.2, U14.3
GND14: C15.2, J43.1, J44.1, J45.1, LED14.1, R75.1, U15.2, U15.3
GND15: C16.2, J46.1, J47.1, J48.1, LED15.1, R80.1, U16.2, U16.3
unnamed: D1.C, LED.2
unnamed: I2C.3, R2.2
unnamed: D2.A, R9.1
unnamed: D1.A, R3.1
unnamed: JP2.1, R4.2
unnamed: I2C.1, R5.2
unnamed: D2.C, LED1.2
unnamed: JP1.1, R6.2
unnamed: I2C1.3, R1.2
unnamed: I2C1.1, R8.2
unnamed: D3.A, R14.1
unnamed: D3.C, LED2.2
unnamed: JP3.1, R12.2
unnamed: I2C2.3, R11.2
unnamed: I2C2.1, R13.2
unnamed: D4.A, R19.1
unnamed: D4.C, LED3.2
unnamed: JP4.1, R17.2
unnamed: I2C3.3, R16.2
unnamed: I2C3.1, R18.2
unnamed: D5.A, R24.1
unnamed: D5.C, LED4.2
unnamed: JP5.1, R22.2
unnamed: I2C4.3, R21.2
unnamed: I2C4.1, R23.2
unnamed: D6.A, R29.1
unnamed: D6.C, LED5.2
unnamed: JP6.1, R27.2
unnamed: I2C5.3, R26.2
unnamed: I2C5.1, R28.2
unnamed: D7.A, R34.1
unnamed: D7.C, LED6.2
unnamed: JP7.1, R32.2
unnamed: I2C6.3, R31.2
unnamed: I2C6.1, R33.2
unnamed: D8.A, R39.1
unnamed: D8.C, LED7.2
unnamed: JP8.1, R37.2
unnamed: I2C7.3, R36.2
unnamed: I2C7.1, R38.2
unnamed: D9.A, R44.1
unnamed: D9.C, LED8.2
unnamed: JP9.1, R42.2
unnamed: I2C8.3, R41.2
unnamed: I2C8.1, R43.2
unnamed: D10.A, R49.1
unnamed: D10.C, LED9.2
unnamed: JP10.1, R47.2
unnamed: I2C9.3, R46.2
unnamed: I2C9.1, R48.2
unnamed: D11.A, R54.1
unnamed: D11.C, LED10.2
unnamed: JP11.1, R52.2
unnamed: I2C10.3, R51.2
unnamed: I2C10.1, R53.2
unnamed: D12.A, R59.1
unnamed: D12.C, LED11.2
unnamed: JP12.1, R57.2
unnamed: I2C11.3, R56.2
unnamed: I2C11.1, R58.2
unnamed: D13.A, R64.1
unnamed: D13.C, LED12.2
unnamed: JP13.1, R62.2
unnamed: I2C12.3, R61.2
unnamed: I2C12.1, R63.2
unnamed: D14.A, R69.1
unnamed: D14.C, LED13.2
unnamed: JP14.1, R67.2
unnamed: I2C13.3, R66.2
unnamed: I2C13.1, R68.2
unnamed: D15.A, R74.1
unnamed: D15.C, LED14.2
unnamed: JP15.1, R72.2
unnamed: I2C14.3, R71.2
unnamed: I2C14.1, R73.2
unnamed: D16.A, R79.1
unnamed: D16.C, LED15.2
unnamed: JP16.1, R77.2
unnamed: I2C15.3, R76.2
unnamed: I2C15.1, R78.2
SCL: J1.4, J2.4, J3.4, R5.1, U1.1
SCL1: J4.4, J5.4, J6.4, R8.1, U2.1
SCL2: J7.4, J8.4, J9.4, R13.1, U3.1
SCL3: J10.4, J11.4, J12.4, R18.1, U4.1
SCL4: J13.4, J14.4, J15.4, R23.1, U5.1
SCL5: J16.4, J17.4, J18.4, R28.1, U6.1
SCL6: J19.4, J20.4, J21.4, R33.1, U7.1
SCL7: J22.4, J23.4, J24.4, R38.1, U8.1
SCL8: J25.4, J26.4, J27.4, R43.1, U9.1
SCL9: J28.4, J29.4, J30.4, R48.1, U10.1
SCL10: J31.4, J32.4, J33.4, R53.1, U11.1
SCL11: J34.4, J35.4, J36.4, R58.1, U12.1
SCL12: J37.4, J38.4, J39.4, R63.1, U13.1
SCL13: J40.4, J41.4, J42.4, R68.1, U14.1
SCL14: J43.4, J44.4, J45.4, R73.1, U15.1
SCL15: J46.4, J47.4, J48.4, R78.1, U16.1
SDA: J1.3, J2.3, J3.3, R2.1, U1.6
SDA1: J4.3, J5.3, J6.3, R1.1, U2.6
SDA2: J7.3, J8.3, J9.3, R11.1, U3.6
SDA3: J10.3, J11.3, J12.3, R16.1, U4.6
SDA4: J13.3, J14.3, J15.3, R21.1, U5.6
SDA5: J16.3, J17.3, J18.3, R26.1, U6.6
SDA6: J19.3, J20.3, J21.3, R31.1, U7.6
SDA7: J22.3, J23.3, J24.3, R36.1, U8.6
SDA8: J25.3, J26.3, J27.3, R41.1, U9.6
SDA9: J28.3, J29.3, J30.3, R46.1, U10.6
SDA10: J31.3, J32.3, J33.3, R51.1, U11.6
SDA11: J34.3, J35.3, J36.3, R56.1, U12.6
SDA12: J37.3, J38.3, J39.3, R61.1, U13.6
SDA13: J40.3, J41.3, J42.3, R66.1, U14.6
SDA14: J43.3, J44.3, J45.3, R71.1, U15.6
SDA15: J46.3, J47.3, J48.3, R76.1, U16.6

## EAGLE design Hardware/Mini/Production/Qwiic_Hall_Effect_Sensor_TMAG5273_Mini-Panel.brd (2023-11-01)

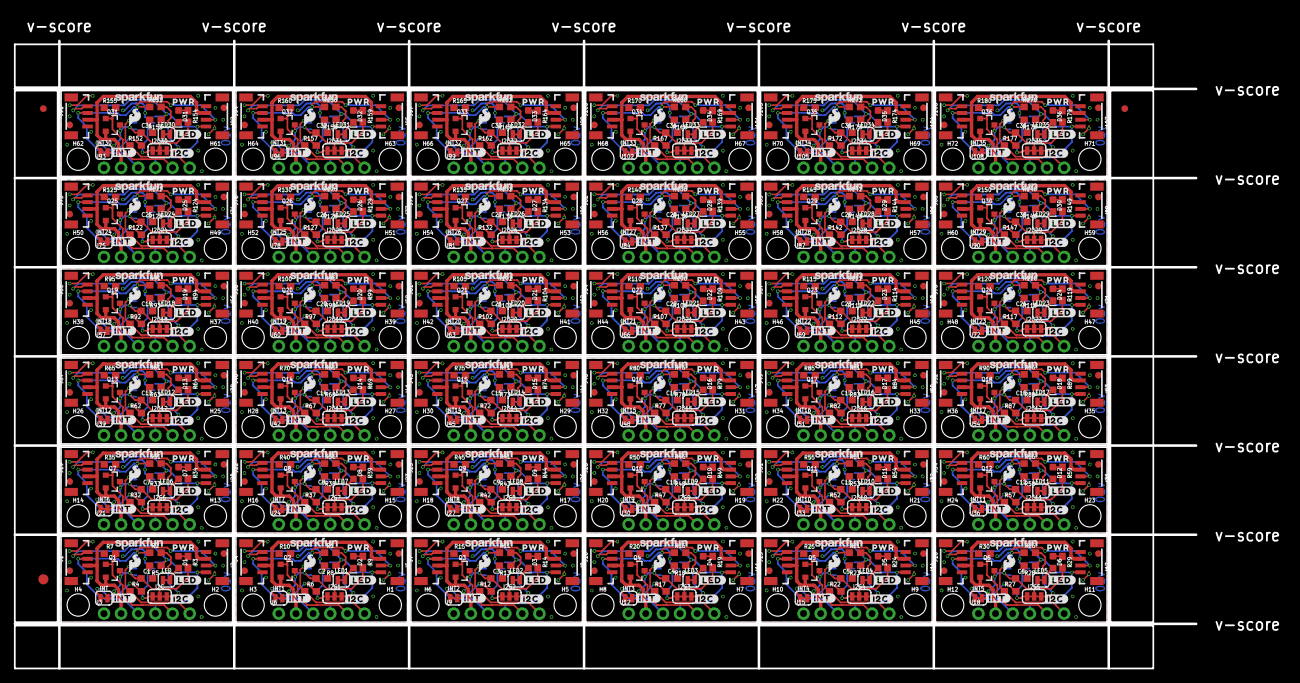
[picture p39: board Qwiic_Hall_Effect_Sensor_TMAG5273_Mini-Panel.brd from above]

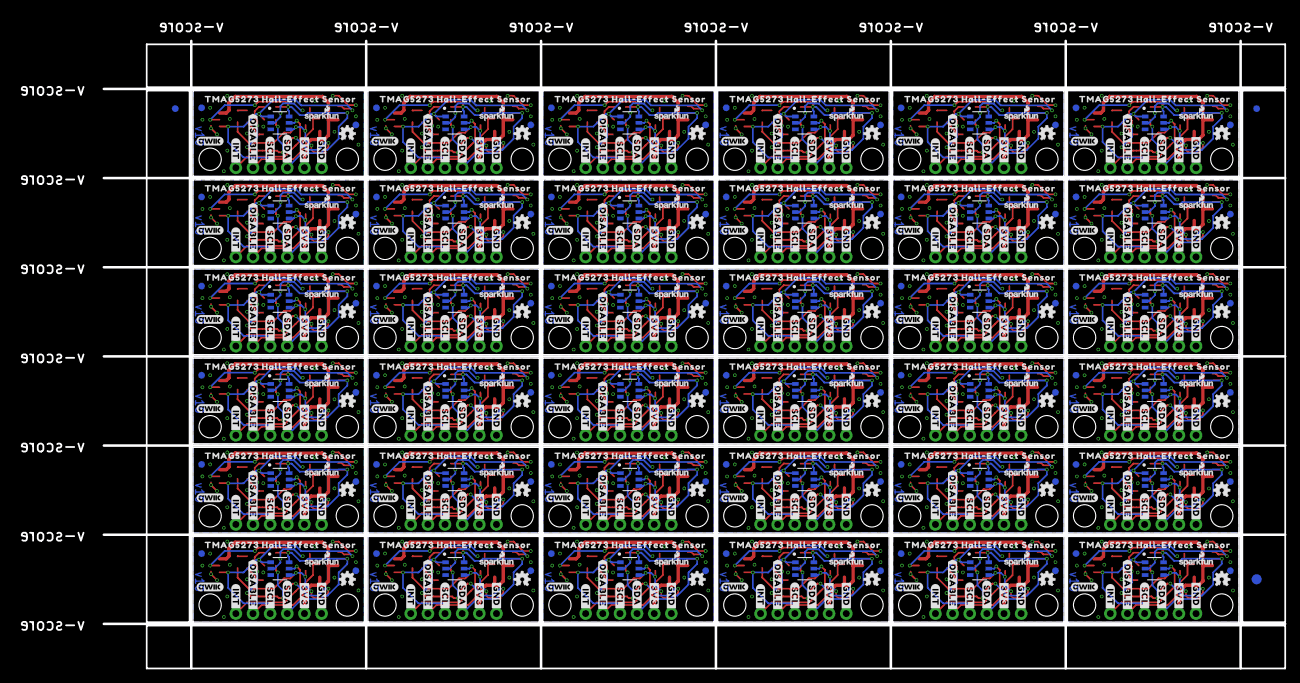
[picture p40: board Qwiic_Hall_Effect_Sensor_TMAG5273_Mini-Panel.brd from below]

Board: 2 copper layers, 175.0 x 93.0 mm, 1338 parts (471 on the bottom side), 432 nets.

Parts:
C1, C2, C3, C4, C5, C6, C7, C8, C9, C10, C11, C12, C13, C14, C15, C16, C17, C18, C19, C20, C21, C22, C23, C24, C25, C26, C27, C28, C29, C30, C31, C32, C33, C34, C35, C36: 0.1uF; 0603
D1, D2, D3, D4, D5, D6, D7, D8, D9, D10, D11, D12, D13, D14, D15, D16, D17, D18, D19, D20, D21, D22, D23, D24, D25, D26, D27, D28, D29, D30, D31, D32, D33, D34, D35, D36: Red; LED-0603
E$1, E$2, E$3, E$4: FIDUCIAL-1X2
E$5, E$6: FIDUCIAL-1.5X3
FD1, FD2, FD3, FD4, FD5, FD6, FD7, FD8, FD9, FD10, FD11, FD12, FD13, FD14, FD15, FD16, FD17, FD18, FD19, FD20, FD21, FD22, FD23, FD24, FD25, FD26, FD27, FD28, FD29, FD30, FD31, FD32, FD33, FD34, FD35, FD36, FD37, FD38, FD39, FD40, FD41, FD42, FD43, FD44, FD45, FD46, FD47, FD48, FD49, FD50, FD51, FD52, FD53, FD54, FD55, FD56, FD57, FD58, FD59, FD60, FD61, FD62, FD63, FD64, FD65, FD66, FD67, FD68, FD69, FD70, FD71, FD72, FD73, FD74, FD75, FD76, FD77, FD78, FD79, FD80, FD81, FD82, FD83, FD84, FD85, FD86, FD87, FD88, FD89, FD90, FD91, FD92, FD93, FD94, FD95, FD96, FD97, FD98, FD99, FD100, FD101, FD102, FD103, FD104, FD105, FD106, FD107, FD108, FD109, FD110, FD111, FD112, FD113, FD114, FD115, FD116, FD117, FD118, FD119, FD120, FD121, FD122, FD123, FD124, FD125, FD126, FD127, FD128, FD129, FD130, FD131, FD132, FD133, FD134, FD135, FD136, FD137, FD138, FD139, FD140, FD141, FD142, FD143, FD144: FIDUCIAL1X2; FIDUCIAL-1X2
H1, H2, H3, H4, H5, H6, H7, H8, H9, H10, H11, H12, H13, H14, H15, H16, H17, H18, H19, H20, H21, H22, H23, H24, H25, H26, H27, H28, H29, H30, H31, H32, H33, H34, H35, H36, H37, H38, H39, H40, H41, H42, H43, H44, H45, H46, H47, H48, H49, H50, H51, H52, H53, H54, H55, H56, H57, H58, H59, H60, H61, H62, H63, H64, H65, H66, H67, H68, H69, H70, H71, H72: STAND-OFF
I2C, I2C1, I2C2, I2C3, I2C4, I2C5, I2C6, I2C7, I2C8, I2C9, I2C10, I2C11, I2C12, I2C13, I2C14, I2C15, I2C16, I2C17, I2C18, I2C19, I2C20, I2C21, I2C22, I2C23, I2C24, I2C25, I2C26, I2C27, I2C28, I2C29, I2C30, I2C31, I2C32, I2C33, I2C34, I2C35: JUMPER-SMT_3_2-NC_TRACE_SILK; SMT-JUMPER_3_2-NC_TRACE_SILK
INT, INT1, INT2, INT3, INT4, INT5, INT6, INT7, INT8, INT9, INT10, INT11, INT12, INT13, INT14, INT15, INT16, INT17, INT18, INT19, INT20, INT21, INT22, INT23, INT24, INT25, INT26, INT27, INT28, INT29, INT30, INT31, INT32, INT33, INT34, INT35: JUMPER-SMT_2_NC_TRACE_SILK; SMT-JUMPER_2_NC_TRACE_SILK
J1, J2, J4, J5, J7, J8, J10, J11, J13, J14, J16, J17, J19, J20, J22, J23, J25, J26, J28, J29, J31, J32, J34, J35, J37, J38, J40, J41, J43, J44, J46, J47, J49, J50, J52, J53, J55, J56, J58, J59, J61, J62, J64, J65, J67, J68, J70, J71, J73, J74, J76, J77, J79, J80, J82, J83, J85, J86, J88, J89, J91, J92, J94, J95, J97, J98, J100, J101, J103, J104, J106, J107: Vertical Qwiic Connector; JST04_1MM_VERT
J3, J6, J9, J12, J15, J18, J21, J24, J27, J30, J33, J36, J39, J42, J45, J48, J51, J54, J57, J60, J63, J66, J69, J72, J75, J78, J81, J84, J87, J90, J93, J96, J99, J102, J105, J108: 1X06_NO_SILK
LED, LED1, LED2, LED3, LED4, LED5, LED6, LED7, LED8, LED9, LED10, LED11, LED12, LED13, LED14, LED15, LED16, LED17, LED18, LED19, LED20, LED21, LED22, LED23, LED24, LED25, LED26, LED27, LED28, LED29, LED30, LED31, LED32, LED33, LED34, LED35: JUMPER-SMT_2_NC_TRACE_SILK; SMT-JUMPER_2_NC_TRACE_SILK
LOGO1, LOGO5, LOGO11, LOGO16, LOGO21, LOGO26, LOGO31, LOGO36, LOGO41, LOGO46, LOGO51, LOGO56, LOGO61, LOGO66, LOGO71, LOGO76, LOGO81, LOGO86, LOGO91, LOGO96, LOGO101, LOGO106, LOGO111, LOGO116, LOGO121, LOGO126, LOGO131, LOGO136, LOGO141, LOGO146, LOGO151, LOGO156, LOGO161, LOGO166, LOGO171, LOGO176: OSHW-LOGOMINI; OSHW-LOGO-MINI
LOGO2, LOGO7, LOGO12, LOGO17, LOGO22, LOGO27, LOGO32, LOGO37, LOGO42, LOGO47, LOGO52, LOGO57, LOGO62, LOGO67, LOGO72, LOGO77, LOGO82, LOGO87, LOGO92, LOGO97, LOGO102, LOGO107, LOGO112, LOGO117, LOGO122, LOGO127, LOGO132, LOGO137, LOGO142, LOGO147, LOGO152, LOGO157, LOGO162, LOGO167, LOGO172, LOGO177: SFE_LOGO_NAME_FLAME5_MM; SFE_LOGO_NAME_FLAME_5MM
LOGO3, LOGO8, LOGO13, LOGO18, LOGO23, LOGO28, LOGO33, LOGO38, LOGO43, LOGO48, LOGO53, LOGO58, LOGO63, LOGO68, LOGO73, LOGO78, LOGO83, LOGO88, LOGO93, LOGO98, LOGO103, LOGO108, LOGO113, LOGO118, LOGO123, LOGO128, LOGO133, LOGO138, LOGO143, LOGO148, LOGO153, LOGO158, LOGO163, LOGO168, LOGO173, LOGO178: QWIIC_LOGO_4MM; QWIIC_4MM
LOGO4, LOGO9, LOGO14, LOGO19, LOGO24, LOGO29, LOGO34, LOGO39, LOGO44, LOGO49, LOGO54, LOGO59, LOGO64, LOGO69, LOGO74, LOGO79, LOGO84, LOGO89, LOGO94, LOGO99, LOGO104, LOGO109, LOGO114, LOGO119, LOGO124, LOGO129, LOGO134, LOGO139, LOGO144, LOGO149, LOGO154, LOGO159, LOGO164, LOGO169, LOGO174, LOGO179: SFE_LOGO_NAME7_MM; SFE_LOGO_NAME_7MM
LOGO6, LOGO10, LOGO15, LOGO20, LOGO25, LOGO30, LOGO35, LOGO40, LOGO45, LOGO50, LOGO55, LOGO60, LOGO65, LOGO70, LOGO75, LOGO80, LOGO85, LOGO90, LOGO95, LOGO100, LOGO105, LOGO110, LOGO115, LOGO120, LOGO125, LOGO130, LOGO135, LOGO140, LOGO145, LOGO150, LOGO155, LOGO160, LOGO165, LOGO170, LOGO175, LOGO180: SFE_LOGO_FLAME.1_INCH; SFE_LOGO_FLAME_.1
Q1, Q2, Q3, Q4, Q5, Q6, Q7, Q8, Q9, Q10, Q11, Q12, Q13, Q14, Q15, Q16, Q17, Q18, Q19, Q20, Q21, Q22, Q23, Q24, Q25, Q26, Q27, Q28, Q29, Q30, Q31, Q32, Q33, Q34, Q35, Q36: 20V/4.2A/52mΩ/1.4W; SOT23-3
R1, R2, R5, R8, R11, R13, R16, R18, R21, R23, R26, R28, R31, R33, R36, R38, R41, R43, R46, R48, R51, R53, R56, R58, R61, R63, R66, R68, R71, R73, R76, R78, R81, R83, R86, R88, R91, R93, R96, R98, R101, R103, R106, R108, R111, R113, R116, R118, R121, R123, R126, R128, R131, R133, R136, R138, R141, R143, R146, R148, R151, R153, R156, R158, R161, R163, R166, R168, R171, R173, R176, R178: 2.2k; 0603
R3, R9, R14, R19, R24, R29, R34, R39, R44, R49, R54, R59, R64, R69, R74, R79, R84, R89, R94, R99, R104, R109, R114, R119, R124, R129, R134, R139, R144, R149, R154, R159, R164, R169, R174, R179: 4.7k; 0603
R4, R6, R7, R10, R12, R15, R17, R20, R22, R25, R27, R30, R32, R35, R37, R40, R42, R45, R47, R50, R52, R55, R57, R60, R62, R65, R67, R70, R72, R75, R77, R80, R82, R85, R87, R90, R92, R95, R97, R100, R102, R105, R107, R110, R112, R115, R117, R120, R122, R125, R127, R130, R132, R135, R137, R140, R142, R145, R147, R150, R152, R155, R157, R160, R162, R165, R167, R170, R172, R175, R177, R180: 10k; 0603
U1, U2, U3, U4, U5, U6, U7, U8, U9, U10, U11, U12, U13, U14, U15, U16, U17, U18, U19, U20, U21, U22, U23, U24, U25, U26, U27, U28, U29, U30, U31, U32, U33, U34, U35, U36: TMAG5273; SOT23-6_DBV_TEX
U$1, U$19, U$30, U$41, U$52, U$63, U$74, U$85, U$96, U$107, U$118, U$129, U$140, U$151, U$162, U$173, U$184, U$195, U$206, U$217, U$228, U$239, U$250, U$261, U$272, U$283, U$294, U$305, U$316, U$327, U$338, U$349, U$360, U$371, U$382, U$393: PWR5282
U$2, U$11, U$23, U$34, U$45, U$56, U$67, U$78, U$89, U$100, U$111, U$122, U$133, U$144, U$155, U$166, U$177, U$188, U$199, U$210, U$221, U$232, U$243, U$254, U$265, U$276, U$287, U$298, U$309, U$320, U$331, U$342, U$353, U$364, U$375, U$386: #SCL#38
U$3, U$13, U$24, U$35, U$46, U$57, U$68, U$79, U$90, U$101, U$112, U$123, U$134, U$145, U$156, U$167, U$178, U$189, U$200, U$211, U$222, U$233, U$244, U$255, U$266, U$277, U$288, U$299, U$310, U$321, U$332, U$343, U$354, U$365, U$376, U$387: #SDA#37
U$4, U$14, U$25, U$36, U$47, U$58, U$69, U$80, U$91, U$102, U$113, U$124, U$135, U$146, U$157, U$168, U$179, U$190, U$201, U$212, U$223, U$234, U$245, U$256, U$267, U$278, U$289, U$300, U$311, U$322, U$333, U$344, U$355, U$366, U$377, U$388: #3V3#37
U$5, U$15, U$26, U$37, U$48, U$59, U$70, U$81, U$92, U$103, U$114, U$125, U$136, U$147, U$158, U$169, U$180, U$191, U$202, U$213, U$224, U$235, U$246, U$257, U$268, U$279, U$290, U$301, U$312, U$323, U$334, U$345, U$356, U$367, U$378, U$389: #GND#36
U$6, U$16, U$27, U$38, U$49, U$60, U$71, U$82, U$93, U$104, U$115, U$126, U$137, U$148, U$159, U$170, U$181, U$192, U$203, U$214, U$225, U$236, U$247, U$258, U$269, U$280, U$291, U$302, U$313, U$324, U$335, U$346, U$357, U$368, U$379, U$390: TMAG5273_HALL#EFFECT_SENSOR0
U$7, U$22, U$33, U$44, U$55, U$66, U$77, U$88, U$99, U$110, U$121, U$132, U$143, U$154, U$165, U$176, U$187, U$198, U$209, U$220, U$231, U$242, U$253, U$264, U$275, U$286, U$297, U$308, U$319, U$330, U$341, U$352, U$363, U$374, U$385, U$396: #DISABLE#5291
U$8, U$17, U$28, U$39, U$50, U$61, U$72, U$83, U$94, U$105, U$116, U$127, U$138, U$149, U$160, U$171, U$182, U$193, U$204, U$215, U$226, U$237, U$248, U$259, U$270, U$281, U$292, U$303, U$314, U$325, U$336, U$347, U$358, U$369, U$380, U$391: #I2C#5276
U$9, U$20, U$31, U$42, U$53, U$64, U$75, U$86, U$97, U$108, U$119, U$130, U$141, U$152, U$163, U$174, U$185, U$196, U$207, U$218, U$229, U$240, U$251, U$262, U$273, U$284, U$295, U$306, U$317, U$328, U$339, U$350, U$361, U$372, U$383, U$394: #INT#5285
U$10, U$18, U$29, U$40, U$51, U$62, U$73, U$84, U$95, U$106, U$117, U$128, U$139, U$150, U$161, U$172, U$183, U$194, U$205, U$216, U$227, U$238, U$249, U$260, U$271, U$282, U$293, U$304, U$315, U$326, U$337, U$348, U$359, U$370, U$381, U$392: #LED#5275
U$12, U$21, U$32, U$43, U$54, U$65, U$76, U$87, U$98, U$109, U$120, U$131, U$142, U$153, U$164, U$175, U$186, U$197, U$208, U$219, U$230, U$241, U$252, U$263, U$274, U$285, U$296, U$307, U$318, U$329, U$340, U$351, U$362, U$373, U$384, U$395: #INT#5287

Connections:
3.3V: J1.2, J2.2, J3.2, Q1.2
3.3V1: J4.2, J5.2, J6.2, Q2.2
3.3V2: J7.2, J8.2, J9.2, Q3.2
3.3V3: J10.2, J11.2, J12.2, Q4.2
3.3V4: J13.2, J14.2, J15.2, Q5.2
3.3V5: J16.2, J17.2, J18.2, Q6.2
3.3V6: J19.2, J20.2, J21.2, Q7.2
3.3V7: J22.2, J23.2, J24.2, Q8.2
3.3V8: J25.2, J26.2, J27.2, Q9.2
3.3V9: J28.2, J29.2, J30.2, Q10.2
3.3V10: J31.2, J32.2, J33.2, Q11.2
3.3V11: J34.2, J35.2, J36.2, Q12.2
3.3V12: J37.2, J38.2, J39.2, Q13.2
3.3V13: J40.2, J41.2, J42.2, Q14.2
3.3V14: J43.2, J44.2, J45.2, Q15.2
3.3V15: J46.2, J47.2, J48.2, Q16.2
3.3V16: J49.2, J50.2, J51.2, Q17.2
3.3V17: J52.2, J53.2, J54.2, Q18.2
3.3V18: J55.2, J56.2, J57.2, Q19.2
3.3V19: J58.2, J59.2, J60.2, Q20.2
3.3V20: J61.2, J62.2, J63.2, Q21.2
3.3V21: J64.2, J65.2, J66.2, Q22.2
3.3V22: J67.2, J68.2, J69.2, Q23.2
3.3V23: J70.2, J71.2, J72.2, Q24.2
3.3V24: J73.2, J74.2, J75.2, Q25.2
3.3V25: J76.2, J77.2, J78.2, Q26.2
3.3V26: J79.2, J80.2, J81.2, Q27.2
3.3V27: J82.2, J83.2, J84.2, Q28.2
3.3V28: J85.2, J86.2, J87.2, Q29.2
3.3V29: J88.2, J89.2, J90.2, Q30.2
3.3V30: J91.2, J92.2, J93.2, Q31.2
3.3V31: J94.2, J95.2, J96.2, Q32.2
3.3V32: J97.2, J98.2, J99.2, Q33.2
3.3V33: J100.2, J101.2, J102.2, Q34.2
3.3V34: J103.2, J104.2, J105.2, Q35.2
3.3V35: J106.2, J107.2, J108.2, Q36.2
3.3V_SW: C1.1, I2C.2, INT.2, Q1.3, R3.2, U1.4
3.3V_SW1: C2.1, I2C1.2, INT1.2, Q2.3, R9.2, U2.4
3.3V_SW2: C3.1, I2C2.2, INT2.2, Q3.3, R14.2, U3.4
3.3V_SW3: C4.1, I2C3.2, INT3.2, Q4.3, R19.2, U4.4
3.3V_SW4: C5.1, I2C4.2, INT4.2, Q5.3, R24.2, U5.4
3.3V_SW5: C6.1, I2C5.2, INT5.2, Q6.3, R29.2, U6.4
3.3V_SW6: C7.1, I2C6.2, INT6.2, Q7.3, R34.2, U7.4
3.3V_SW7: C8.1, I2C7.2, INT7.2, Q8.3, R39.2, U8.4
3.3V_SW8: C9.1, I2C8.2, INT8.2, Q9.3, R44.2, U9.4
3.3V_SW9: C10.1, I2C9.2, INT9.2, Q10.3, R49.2, U10.4
3.3V_SW10: C11.1, I2C10.2, INT10.2, Q11.3, R54.2, U11.4
3.3V_SW11: C12.1, I2C11.2, INT11.2, Q12.3, R59.2, U12.4
3.3V_SW12: C13.1, I2C12.2, INT12.2, Q13.3, R64.2, U13.4
3.3V_SW13: C14.1, I2C13.2, INT13.2, Q14.3, R69.2, U14.4
3.3V_SW14: C15.1, I2C14.2, INT14.2, Q15.3, R74.2, U15.4
3.3V_SW15: C16.1, I2C15.2, INT15.2, Q16.3, R79.2, U16.4
3.3V_SW16: C17.1, I2C16.2, INT16.2, Q17.3, R84.2, U17.4
3.3V_SW17: C18.1, I2C17.2, INT17.2, Q18.3, R89.2, U18.4
3.3V_SW18: C19.1, I2C18.2, INT18.2, Q19.3, R94.2, U19.4
3.3V_SW19: C20.1, I2C19.2, INT19.2, Q20.3, R99.2, U20.4
3.3V_SW20: C21.1, I2C20.2, INT20.2, Q21.3, R104.2, U21.4
3.3V_SW21: C22.1, I2C21.2, INT21.2, Q22.3, R109.2, U22.4
3.3V_SW22: C23.1, I2C22.2, INT22.2, Q23.3, R114.2, U23.4
3.3V_SW23: C24.1, I2C23.2, INT23.2, Q24.3, R119.2, U24.4
3.3V_SW24: C25.1, I2C24.2, INT24.2, Q25.3, R124.2, U25.4
3.3V_SW25: C26.1, I2C25.2, INT25.2, Q26.3, R129.2, U26.4
3.3V_SW26: C27.1, I2C26.2, INT26.2, Q27.3, R134.2, U27.4
3.3V_SW27: C28.1, I2C27.2, INT27.2, Q28.3, R139.2, U28.4
3.3V_SW28: C29.1, I2C28.2, INT28.2, Q29.3, R144.2, U29.4
3.3V_SW29: C30.1, I2C29.2, INT29.2, Q30.3, R149.2, U30.4
3.3V_SW30: C31.1, I2C30.2, INT30.2, Q31.3, R154.2, U31.4
3.3V_SW31: C32.1, I2C31.2, INT31.2, Q32.3, R159.2, U32.4
3.3V_SW32: C33.1, I2C32.2, INT32.2, Q33.3, R164.2, U33.4
3.3V_SW33: C34.1, I2C33.2, INT33.2, Q34.3, R169.2, U34.4
3.3V_SW34: C35.1, I2C34.2, INT34.2, Q35.3, R174.2, U35.4
3.3V_SW35: C36.1, I2C35.2, INT35.2, Q36.3, R179.2, U36.4
!INT: J3.6, R4.1, U1.5
!INT1: J6.6, R6.1, U2.5
!INT2: J9.6, R12.1, U3.5
!INT3: J12.6, R17.1, U4.5
!INT4: J15.6, R22.1, U5.5
!INT5: J18.6, R27.1, U6.5
!INT6: J21.6, R32.1, U7.5
!INT7: J24.6, R37.1, U8.5
!INT8: J27.6, R42.1, U9.5
!INT9: J30.6, R47.1, U10.5
!INT10: J33.6, R52.1, U11.5
!INT11: J36.6, R57.1, U12.5
!INT12: J39.6, R62.1, U13.5
!INT13: J42.6, R67.1, U14.5
!INT14: J45.6, R72.1, U15.5
!INT15: J48.6, R77.1, U16.5
!INT16: J51.6, R82.1, U17.5
!INT17: J54.6, R87.1, U18.5
!INT18: J57.6, R92.1, U19.5
!INT19: J60.6, R97.1, U20.5
!INT20: J63.6, R102.1, U21.5
!INT21: J66.6, R107.1, U22.5
!INT22: J69.6, R112.1, U23.5
!INT23: J72.6, R117.1, U24.5
!INT24: J75.6, R122.1, U25.5
!INT25: J78.6, R127.1, U26.5
!INT26: J81.6, R132.1, U27.5
!INT27: J84.6, R137.1, U28.5
!INT28: J87.6, R142.1, U29.5
!INT29: J90.6, R147.1, U30.5
!INT30: J93.6, R152.1, U31.5
!INT31: J96.6, R157.1, U32.5
!INT32: J99.6, R162.1, U33.5
!INT33: J102.6, R167.1, U34.5
!INT34: J105.6, R172.1, U35.5
!INT35: J108.6, R177.1, U36.5
DISABLE: J3.5, Q1.1, R7.2
DISABLE1: J6.5, Q2.1, R10.2
DISABLE2: J9.5, Q3.1, R15.2
DISABLE3: J12.5, Q4.1, R20.2
DISABLE4: J15.5, Q5.1, R25.2
DISABLE5: J18.5, Q6.1, R30.2
DISABLE6: J21.5, Q7.1, R35.2
DISABLE7: J24.5, Q8.1, R40.2
DISABLE8: J27.5, Q9.1, R45.2
DISABLE9: J30.5, Q10.1, R50.2
DISABLE10: J33.5, Q11.1, R55.2
DISABLE11: J36.5, Q12.1, R60.2
DISABLE12: J39.5, Q13.1, R65.2
DISABLE13: J42.5, Q14.1, R70.2
DISABLE14: J45.5, Q15.1, R75.2
DISABLE15: J48.5, Q16.1, R80.2
DISABLE16: J51.5, Q17.1, R85.2
DISABLE17: J54.5, Q18.1, R90.2
DISABLE18: J57.5, Q19.1, R95.2
DISABLE19: J60.5, Q20.1, R100.2
DISABLE20: J63.5, Q21.1, R105.2
DISABLE21: J66.5, Q22.1, R110.2
DISABLE22: J69.5, Q23.1, R115.2
DISABLE23: J72.5, Q24.1, R120.2
DISABLE24: J75.5, Q25.1, R125.2
DISABLE25: J78.5, Q26.1, R130.2
DISABLE26: J81.5, Q27.1, R135.2
DISABLE27: J84.5, Q28.1, R140.2
DISABLE28: J87.5, Q29.1, R145.2
DISABLE29: J90.5, Q30.1, R150.2
DISABLE30: J93.5, Q31.1, R155.2
DISABLE31: J96.5, Q32.1, R160.2
DISABLE32: J99.5, Q33.1, R165.2
DISABLE33: J102.5, Q34.1, R170.2
DISABLE34: J105.5, Q35.1, R175.2
DISABLE35: J108.5, Q36.1, R180.2
GND: C1.2, J1.1, J2.1, J3.1, LED.1, R7.1, U1.2, U1.3
GND1: C2.2, J4.1, J5.1, J6.1, LED1.1, R10.1, U2.2, U2.3
GND2: C3.2, J7.1, J8.1, J9.1, LED2.1, R15.1, U3.2, U3.3
GND3: C4.2, J10.1, J11.1, J12.1, LED3.1, R20.1, U4.2, U4.3
GND4: C5.2, J13.1, J14.1, J15.1, LED4.1, R25.1, U5.2, U5.3
GND5: C6.2, J16.1, J17.1, J18.1, LED5.1, R30.1, U6.2, U6.3
GND6: C7.2, J19.1, J20.1, J21.1, LED6.1, R35.1, U7.2, U7.3
GND7: C8.2, J22.1, J23.1, J24.1, LED7.1, R40.1, U8.2, U8.3
GND8: C9.2, J25.1, J26.1, J27.1, LED8.1, R45.1, U9.2, U9.3
GND9: C10.2, J28.1, J29.1, J30.1, LED9.1, R50.1, U10.2, U10.3
GND10: C11.2, J31.1, J32.1, J33.1, LED10.1, R55.1, U11.2, U11.3
GND11: C12.2, J34.1, J35.1, J36.1, LED11.1, R60.1, U12.2, U12.3
GND12: C13.2, J37.1, J38.1, J39.1, LED12.1, R65.1, U13.2, U13.3
GND13: C14.2, J40.1, J41.1, J42.1, LED13.1, R70.1, U14.2, U14.3
GND14: C15.2, J43.1, J44.1, J45.1, LED14.1, R75.1, U15.2, U15.3
GND15: C16.2, J46.1, J47.1, J48.1, LED15.1, R80.1, U16.2, U16.3
GND16: C17.2, J49.1, J50.1, J51.1, LED16.1, R85.1, U17.2, U17.3
GND17: C18.2, J52.1, J53.1, J54.1, LED17.1, R90.1, U18.2, U18.3
GND18: C19.2, J55.1, J56.1, J57.1, LED18.1, R95.1, U19.2, U19.3
GND19: C20.2, J58.1, J59.1, J60.1, LED19.1, R100.1, U20.2, U20.3
GND20: C21.2, J61.1, J62.1, J63.1, LED20.1, R105.1, U21.2, U21.3
GND21: C22.2, J64.1, J65.1, J66.1, LED21.1, R110.1, U22.2, U22.3
GND22: C23.2, J67.1, J68.1, J69.1, LED22.1, R115.1, U23.2, U23.3
GND23: C24.2, J70.1, J71.1, J72.1, LED23.1, R120.1, U24.2, U24.3
GND24: C25.2, J73.1, J74.1, J75.1, LED24.1, R125.1, U25.2, U25.3
GND25: C26.2, J76.1, J77.1, J78.1, LED25.1, R130.1, U26.2, U26.3
GND26: C27.2, J79.1, J80.1, J81.1, LED26.1, R135.1, U27.2, U27.3
GND27: C28.2, J82.1, J83.1, J84.1, LED27.1, R140.1, U28.2, U28.3
GND28: C29.2, J85.1, J86.1, J87.1, LED28.1, R145.1, U29.2, U29.3
GND29: C30.2, J88.1, J89.1, J90.1, LED29.1, R150.1, U30.2, U30.3
GND30: C31.2, J91.1, J92.1, J93.1, LED30.1, R155.1, U31.2, U31.3
GND31: C32.2, J94.1, J95.1, J96.1, LED31.1, R160.1, U32.2, U32.3
GND32: C33.2, J97.1, J98.1, J99.1, LED32.1, R165.1, U33.2, U33.3
GND33: C34.2, J100.1, J101.1, J102.1, LED33.1, R170.1, U34.2, U34.3
GND34: C35.2, J103.1, J104.1, J105.1, LED34.1, R175.1, U35.2, U35.3
GND35: C36.2, J106.1, J107.1, J108.1, LED35.1, R180.1, U36.2, U36.3
unnamed: D1.C, LED.2
unnamed: I2C.3, R2.2
unnamed: D2.A, R9.1
unnamed: D1.A, R3.1
unnamed: INT.1, R4.2
unnamed: I2C.1, R5.2
unnamed: D2.C, LED1.2
unnamed: INT1.1, R6.2
unnamed: I2C1.3, R1.2
unnamed: I2C1.1, R8.2
unnamed: D3.A, R14.1
unnamed: D3.C, LED2.2
unnamed: INT2.1, R12.2
unnamed: I2C2.3, R11.2
unnamed: I2C2.1, R13.2
unnamed: D4.A, R19.1
unnamed: D4.C, LED3.2
unnamed: INT3.1, R17.2
unnamed: I2C3.3, R16.2
unnamed: I2C3.1, R18.2
unnamed: D5.A, R24.1
unnamed: D5.C, LED4.2
unnamed: INT4.1, R22.2
unnamed: I2C4.3, R21.2
unnamed: I2C4.1, R23.2
unnamed: D6.A, R29.1
unnamed: D6.C, LED5.2
unnamed: INT5.1, R27.2
unnamed: I2C5.3, R26.2
unnamed: I2C5.1, R28.2
unnamed: D7.A, R34.1
unnamed: D7.C, LED6.2
unnamed: INT6.1, R32.2
unnamed: I2C6.3, R31.2
unnamed: I2C6.1, R33.2
unnamed: D8.A, R39.1
unnamed: D8.C, LED7.2
unnamed: INT7.1, R37.2
unnamed: I2C7.3, R36.2
unnamed: I2C7.1, R38.2
unnamed: D9.A, R44.1
unnamed: D9.C, LED8.2
unnamed: INT8.1, R42.2
unnamed: I2C8.3, R41.2
unnamed: I2C8.1, R43.2
unnamed: D10.A, R49.1
unnamed: D10.C, LED9.2
unnamed: INT9.1, R47.2
unnamed: I2C9.3, R46.2
unnamed: I2C9.1, R48.2
unnamed: D11.A, R54.1
unnamed: D11.C, LED10.2
unnamed: INT10.1, R52.2
unnamed: I2C10.3, R51.2
unnamed: I2C10.1, R53.2
unnamed: D12.A, R59.1
unnamed: D12.C, LED11.2
unnamed: INT11.1, R57.2
unnamed: I2C11.3, R56.2
unnamed: I2C11.1, R58.2
unnamed: D13.A, R64.1
unnamed: D13.C, LED12.2
unnamed: INT12.1, R62.2
unnamed: I2C12.3, R61.2
unnamed: I2C12.1, R63.2
unnamed: D14.A, R69.1
unnamed: D14.C, LED13.2
unnamed: INT13.1, R67.2
unnamed: I2C13.3, R66.2
unnamed: I2C13.1, R68.2
unnamed: D15.A, R74.1
unnamed: D15.C, LED14.2
unnamed: INT14.1, R72.2
unnamed: I2C14.3, R71.2
unnamed: I2C14.1, R73.2
unnamed: D16.A, R79.1
unnamed: D16.C, LED15.2
unnamed: INT15.1, R77.2
unnamed: I2C15.3, R76.2
unnamed: I2C15.1, R78.2
unnamed: D17.A, R84.1
unnamed: D17.C, LED16.2
unnamed: INT16.1, R82.2
unnamed: I2C16.3, R81.2
unnamed: I2C16.1, R83.2
unnamed: D18.A, R89.1
unnamed: D18.C, LED17.2
unnamed: INT17.1, R87.2
unnamed: I2C17.3, R86.2
unnamed: I2C17.1, R88.2
unnamed: D19.A, R94.1
unnamed: D19.C, LED18.2
unnamed: INT18.1, R92.2
unnamed: I2C18.3, R91.2
unnamed: I2C18.1, R93.2
unnamed: D20.A, R99.1
unnamed: D20.C, LED19.2
unnamed: INT19.1, R97.2
unnamed: I2C19.3, R96.2
unnamed: I2C19.1, R98.2
unnamed: D21.A, R104.1
unnamed: D21.C, LED20.2
unnamed: INT20.1, R102.2
unnamed: I2C20.3, R101.2
unnamed: I2C20.1, R103.2
unnamed: D22.A, R109.1
unnamed: D22.C, LED21.2
unnamed: INT21.1, R107.2
unnamed: I2C21.3, R106.2
unnamed: I2C21.1, R108.2
unnamed: D23.A, R114.1
unnamed: D23.C, LED22.2
unnamed: INT22.1, R112.2
unnamed: I2C22.3, R111.2
unnamed: I2C22.1, R113.2
unnamed: D24.A, R119.1
unnamed: D24.C, LED23.2
unnamed: INT23.1, R117.2
unnamed: I2C23.3, R116.2
unnamed: I2C23.1, R118.2
unnamed: D25.A, R124.1
unnamed: D25.C, LED24.2
unnamed: INT24.1, R122.2
unnamed: I2C24.3, R121.2
unnamed: I2C24.1, R123.2
unnamed: D26.A, R129.1
unnamed: D26.C, LED25.2
unnamed: INT25.1, R127.2
unnamed: I2C25.3, R126.2
unnamed: I2C25.1, R128.2
unnamed: D27.A, R134.1
unnamed: D27.C, LED26.2
unnamed: INT26.1, R132.2
unnamed: I2C26.3, R131.2
unnamed: I2C26.1, R133.2
unnamed: D28.A, R139.1
unnamed: D28.C, LED27.2
unnamed: INT27.1, R137.2
unnamed: I2C27.3, R136.2
unnamed: I2C27.1, R138.2
unnamed: D29.A, R144.1
unnamed: D29.C, LED28.2
unnamed: INT28.1, R142.2
unnamed: I2C28.3, R141.2
unnamed: I2C28.1, R143.2
unnamed: D30.A, R149.1
unnamed: D30.C, LED29.2
unnamed: INT29.1, R147.2
unnamed: I2C29.3, R146.2
unnamed: I2C29.1, R148.2
unnamed: D31.A, R154.1
unnamed: D31.C, LED30.2
unnamed: INT30.1, R152.2
unnamed: I2C30.3, R151.2
unnamed: I2C30.1, R153.2
unnamed: D32.A, R159.1
unnamed: D32.C, LED31.2
unnamed: INT31.1, R157.2
unnamed: I2C31.3, R156.2
unnamed: I2C31.1, R158.2
unnamed: D33.A, R164.1
unnamed: D33.C, LED32.2
unnamed: INT32.1, R162.2
unnamed: I2C32.3, R161.2
unnamed: I2C32.1, R163.2
unnamed: D34.A, R169.1
unnamed: D34.C, LED33.2
unnamed: INT33.1, R167.2
unnamed: I2C33.3, R166.2
unnamed: I2C33.1, R168.2
unnamed: D35.A, R174.1
unnamed: D35.C, LED34.2
unnamed: INT34.1, R172.2
unnamed: I2C34.3, R171.2
unnamed: I2C34.1, R173.2
unnamed: D36.A, R179.1
unnamed: D36.C, LED35.2
unnamed: INT35.1, R177.2
unnamed: I2C35.3, R176.2
unnamed: I2C35.1, R178.2
SCL: J1.4, J2.4, J3.4, R5.1, U1.1
SCL1: J4.4, J5.4, J6.4, R8.1, U2.1
SCL2: J7.4, J8.4, J9.4, R13.1, U3.1
SCL3: J10.4, J11.4, J12.4, R18.1, U4.1
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

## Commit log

2023-09-20 Schematic created and TMAG added to library
    [Qwiic_Hall_Effect_Sensor_TMAG5273.sch]
2023-09-29 Restructured file folders for new board
    Added the micro folder and schematic to the project. Moved the 1x1 board into its own file folder.
    [Qwiic_Hall_Effect_Sensor_TMAG5273.sch, Qwiic_Hall_Effect_Sensor_TMAG5273_Mini.sch]
2023-10-13 Completed schematic and routing
    Need to finish aesthetics and dimensions to layout. Almost ready for review.
    [Qwiic_Hall_Effect_Sensor_TMAG5273.brd, Qwiic_Hall_Effect_Sensor_TMAG5273.sch, Qwiic_Hall_Effect_Sensor_TMAG5273_Mini.brd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]
2023-10-13 Updates for design review
    Changed LED and associated resistor to have the correct part and value; added dimension lines and further notes on the layout; adjusted aesthetics in schematic to now be the same as each other (minus the change in Qwiic connectors and number of standoffs)
    [Qwiic_Hall_Effect_Sensor_TMAG5273.brd, Qwiic_Hall_Effect_Sensor_TMAG5273.sch, Qwiic_Hall_Effect_Sensor_TMAG5273_Mini.brd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]
2023-10-16 Ready for review
    Updates from ENG Checklist - Small tweaks added - updated ordering of PTH headers for SDA and SCL, fixed final errors on design
    [Qwiic_Hall_Effect_Sensor_TMAG5273.brd, Qwiic_Hall_Effect_Sensor_TMAG5273.sch, Qwiic_Hall_Effect_Sensor_TMAG5273_Mini.brd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]
2023-10-17 Updated !INT silk
    Updated !INT silk to be the correct end (now ( rather than < )
    [Qwiic_Hall_Effect_Sensor_TMAG5273.brd, Qwiic_Hall_Effect_Sensor_TMAG5273_Mini.brd]
2023-10-17 Design Review Changes
    Adjusted schematic to have the correct power-on reset circuit, along with the change in the layout. The GPIO net was relabled to RESET to match the layout of the board/labeling. Adjusted some labeling in the schematic.
    [Qwiic_Hall_Effect_Sensor_TMAG5273.brd, Qwiic_Hall_Effect_Sensor_TMAG5273.sch, Qwiic_Hall_Effect_Sensor_TMAG5273_Mini.brd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]
2023-10-18 Adjusted from design review
    Added truth tables, changed RESET to Disable, adjusted magnetic axis to be centered to the middle of the board, added push button for 1x1 reset option
    [Qwiic_Hall_Effect_Sensor_TMAG5273.brd, Qwiic_Hall_Effect_Sensor_TMAG5273.sch, Qwiic_Hall_Effect_Sensor_TMAG5273_Mini.brd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]
2023-10-18 Added gerber files
    Files added and now ready for order
    [Qwiic_Hall_Effect_Sensor_TMAG5273.GBL, Qwiic_Hall_Effect_Sensor_TMAG5273.GBO, Qwiic_Hall_Effect_Sensor_TMAG5273.GBP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]
2023-10-30 Design review updates
    Addition of gerber files for both mini and 1x1, adjusted board for reds engineering checklist run.
    [Qwiic_Hall_Effect_Sensor_TMAG5273-Panel.GBL, Qwiic_Hall_Effect_Sensor_TMAG5273-Panel.GBO, Qwiic_Hall_Effect_Sensor_TMAG5273-Panel.GBP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]
2023-10-31 Updates from design review
    Adjusted traces for better GND connections; changed direction of tail end for the DISABLE pin; changed jumper names in schematic to match layout; added more GND vias to the Mini; updated trace widths to be the correct size
    [Qwiic_Hall_Effect_Sensor_TMAG5273.brd, Qwiic_Hall_Effect_Sensor_TMAG5273.sch, Qwiic_Hall_Effect_Sensor_TMAG5273_Mini.brd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]
2023-11-01 Files for ordering
    Re-added the correct panel files for the project along with ordering instructions. Made final adjustments from design review and board is ready for order!
    [Qwiic_Hall_Effect_Sensor_TMAG5273-Panel.brd, Qwiic_Hall_Effect_Sensor_TMAG5273.brd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]
2023-11-27 Updated I2C address in schematic
    Updated the I2C address to the actual address used in the library/for the devices usage
    [Qwiic_Hall_Effect_Sensor_TMAG5273.sch, Qwiic_Hall_Effect_Sensor_TMAG5273_Mini.sch]
2023-12-08 Add Technical Documents
    Datasheet, application notes, schematic, board dimensions, etc.
2023-12-14 Update hookup guide
    Include missing images
    Add warnings for button and magnet

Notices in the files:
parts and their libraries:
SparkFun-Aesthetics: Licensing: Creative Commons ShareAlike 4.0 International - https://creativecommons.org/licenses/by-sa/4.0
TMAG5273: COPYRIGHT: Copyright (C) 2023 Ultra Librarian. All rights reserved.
